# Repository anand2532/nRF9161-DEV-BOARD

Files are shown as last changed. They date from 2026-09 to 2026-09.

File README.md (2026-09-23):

# nRF9161-DEV-BOARD

Development board for **Nordic Semiconductor nRF9161-LACA-R7** (LTE-M, NB-IoT, DECT NR+, GNSS).

Electrical source of truth is official Nordic documentation only:

- nRF9161 Product Specification v1.0 (pinout Table 55, mechanics Table 56, reference circuitry)
- nRF91 Hardware Design Guidelines (nWP-037 family / Table 2) — nRF9161 uses the nRF9160 SiP power/RF pinout with DK extra **FB3 on VDD2**
- nRF91 Series Antenna and RF Interface Guidelines (nWP033)
- nRF9161 DK PCA10153 1.0.0 (FB3, GNSS U.FL + COEX0, TPD3F303, SWF MM8130)
- PCN134: DEC0 = **4.7 µF** (not the older 47 µF)

Do not treat this README as a substitute for those documents when certifying a product.

Project files keep the existing names `nRF9161-DEV-BOARD.kicad_*` (not `nRF9161_Board.*`).

## Board purpose

A 120 mm × 80 mm, 4-layer breakout so firmware and RF bring-up can use every nRF9161 interface: LTE/NR+ and GNSS antenna ports, nano-SIM, SWD, all 32 GPIOs, and labelled UART/SPI/I2C/I2S/PDM/ADC headers.

## nRF9161 capabilities on this board

| Function | Implementation |
| --- | --- |
| LTE-M / NB-IoT / DECT NR+ | ANT pin 61, reserved π-match (0 Ω series, DNP shunts), U.FL J2, SWF J3 |
| AUX | AUX pin 64, reserved π-match, TP1 |
| GNSS | GPS pin 67, nWP033 active-antenna bias-T, U.FL J5, SWF J6 |
| UICC/SIM | SIM_RST/CLK/IO/1V8 via TPD3F303 + JAE SF72S006 nano-SIM. SIM_DET pin 45 **floats** |
| 32 GPIOs | J12 (P0.00–P0.15) and J13 (P0.16–P0.31) |
| SWD | 10-pin Cortex-M J8 |
| MAGPIO / MIPI RFFE | J14 |
| COEX | J15 (COEX0 also enables GNSS bias through R4) |
| ENABLE / nRESET | R1 10 kΩ + C14; SW1 DISABLE; R5 1 kΩ + SW2 RESET |

Onboard GNSS ceramic antenna + BGM1212N7 LNA from the nRF9161 DK is **not fitted**. GNSS is U.FL-only for an external **active** antenna.

## Power requirements

VIN **3.0–5.5 V** on J1 (nRF9161 VDD range).

```
VIN (J1)
  D1 PMEG4030ER reverse Schottky → D2 SMAJ5.0A → F1 2 A → FB4 → C1/C2
  R2 50 mΩ (JP1 bypass) → VDD_nRF
       FB1 → VDD1 (pin 102) + C3 47 µF / C4 4.7 µF / C5 100 nF / C6 15 pF
       FB2 + FB3 → VDD2 (pin 22) + C7–C10 (FB3 per nRF9161 DK)
  R1 10 kΩ → ENABLE (pin 101) + C14 100 nF; SW1 to GND = disable
  TLV73333 3.3 V (EN=ENABLE) → VDD_GPIO (pin 12) + C11/C12
  DEC0 (pin 13) → C13 4.7 µF
```

Peak LTE TX on VDD2 is on the order of **500 mA**. Do not power the board from a weak USB 5 V dongle without checking cable and supply headroom. Use a current-limited bench supply for first power-up (1 A limit is a reasonable start; 2 A fuse is the hard limit).

Open JP1 and measure across R2 / TP19–TP20 for current. Close JP1 for normal operation.

Power LED D3 is on VIN, not a GPIO.

Test points: TP_VIN (TP15), TP_VDD_nRF (TP14), TP_VDD1 (TP11), TP_VDD2 (TP12), TP_VDD_GPIO (TP10/TP13), TP_GND (TP16), TP_ENABLE (TP17).

## RF architecture

Nordic evaluates ANT/AUX/GPS as **50 Ω single-ended**. Matching values are antenna- and PCB-specific (nWP033). This board does **not** invent tuned L/C values:

- LTE/NR+: series L1 is a 0 Ω / LQW15AN placeholder; C21/C22 DNP high-Q 0402 (HDG: Murata LQW15AN + GJM1555C1).
- AUX: same reserved π (L2, C23, C24).
- GNSS: nWP033 active-antenna bias-T — C27 100 pF DC block, L4 100 nH choke, C28–C30 + FB5 on ~3.3 V bias from VDD_GPIO via U3 TPS22919DCKR (ON=COEX0) → FB5; R4/TP2 are COEX0 sense only. Shunts C31/C32 DNP.

Tune L1/C21/C22 (and GNSS shunts) on the finished mechanics with a VNA.

LTE and GNSS matching sit immediately west of the SiP (U1 rotation 180°, RF edge west). Do not place digital traces under the matching networks.

## Antenna requirements

| Connector | Net | Use |
| --- | --- | --- |
| J2 U.FL | ANT_FIT | External LTE / DECT NR+ antenna |
| J3 SWF MM8130 | ANT_FIT | Conducted LTE RF test |
| J5 U.FL | GNSS_ANT | External **active** GNSS antenna (DC on center) |
| J6 SWF MM8130 | GNSS_ANT | Conducted GNSS RF test |
| TP1 | AUX_FIT | AUX test |

Disable GNSS LNA bias (`%XCOEX0`) if using a passive GNSS antenna.

## SIM requirements

- nRF9161 SIM_RST / SIM_CLK / SIM_IO / SIM_1V8 → TPD3F303DPV → JAE SF72S006 **nano-SIM (4FF)**
- SIM_DET (pin 45) **must float** (PS). Mechanical card-detect is `SIM_CD` on J7 CSW-DSW / TP6 — **not** pin 45
- Close JP2 to feed SIM_1V8 to the card
- SIM VPP (C6) NC

## GPIO map (authoritative)

All 32 GPIOs are on J12/J13. Protocol headers J9–J11 and J16–J18 are the **same nets** (intentional probe multiplexing). Onboard LEDs/USER share P0.00–P0.02 and P0.08 — drive those pins as GPIO or leave the LED/button unused in firmware.

| Pin | GPIO | Default header | Onboard | Alternate |
| --- | --- | --- | --- | --- |
| 95 | P0.00 | J12.1 | STATUS LED D4 | — |
| 96 | P0.01 | J12.2 | LTE LED D5 | — |
| 97 | P0.02 | J12.3 | GNSS LED D6 | — |
| 99 | P0.03 | J12.4 | SPARE LED D7 (optional) | — |
| 100 | P0.04 | J12.5 / UART CTS J9 | — | — |
| 2 | P0.05 | J12.6 / UART RTS J9 | — | — |
| 3 | P0.06 | J12.7 / UART TX J9 | — | — |
| 4 | P0.07 | J12.8 / UART RX J9 | — | — |
| 15 | P0.08 | J12.9 | USER SW3, R14 10 kΩ to VDD_GPIO | — |
| 16 | P0.09 | J12.10 / I2S SDIN J16 | — | — |
| 18 | P0.10 | J12.11 / I2S SCK J16 | — | — |
| 19 | P0.11 | J12.12 / I2S LRCK J16 | — | — |
| 20 | P0.12 | J12.13 / I2S SDOUT J16 | — | — |
| 23 | P0.13 | J12.14 / AIN0 J18 | — | AIN0 |
| 24 | P0.14 | J12.15 / AIN1 J18 | — | AIN1 |
| 25 | P0.15 | J12.16 / AIN2 J18 | — | AIN2 |
| 26 | P0.16 | J13.1 / AIN3 J18 | — | AIN3 |
| 28 | P0.17 | J13.2 / AIN4 J18 / PDM CLK J17 | — | AIN4 |
| 29 | P0.18 | J13.3 / AIN5 J18 / PDM DIN J17 | — | AIN5 |
| 30 | P0.19 | J13.4 / AIN6 J18 | — | AIN6 |
| 35 | P0.20 | J13.5 / AIN7 J18 | — | AIN7 |
| 37 | P0.21 | J13.6 / SPI SCK J10 | — | TRACECLK |
| 38 | P0.22 | J13.7 / SPI MOSI J10 / J8.6 SWO | — | TRACEDATA0 |
| 39 | P0.23 | J13.8 / SPI MISO J10 | — | TRACEDATA1 |
| 40 | P0.24 | J13.9 / SPI CS J10 | — | TRACEDATA2 |
| 42 | P0.25 | J13.10 | — | TRACEDATA3 |
| 83 | P0.26 | J13.11 | — | — |
| 84 | P0.27 | J13.12 | — | — |
| 86 | P0.28 | J13.13 | — | — |
| 87 | P0.29 | J13.14 | — | — |
| 88 | P0.30 | J13.15 / I2C SDA J11 | — | — |
| 89 | P0.31 | J13.16 / I2C SCL J11 | — | — |

J12/J13 pins 17–18 = VDD_GPIO (3.3 V), 19–20 = GND.

Full 127-pin audit: `reports/PIN_AUDIT.csv`.

## Peripheral map

| Header | Signals |
| --- | --- |
| J9 UART | TX P0.06, RX P0.07, RTS P0.05, CTS P0.04, 3V3, GND |
| J10 SPI | SCK P0.21, MOSI P0.22, MISO P0.23, CS P0.24, 3V3, GND |
| J11 I2C | SDA P0.30, SCL P0.31, 3V3, GND |
| J16 I2S | SCK P0.10, LRCK P0.11, SDIN P0.09, SDOUT P0.12, 3V3, GND |
| J17 PDM | CLK P0.17, DATA P0.18, 3V3, GND |
| J18 ADC | AIN0–AIN7 (P0.13–P0.20), GND |
| J8 SWD | 10-pin 1.27 mm ARM Cortex (J-Link) |

PWM can be assigned to any GPIO in software; there is no dedicated PWM header.

## SWD / programming

J8 (Samtec FTSH-105 style 1.27 mm 2×5):

| Pin | Signal |
| --- | --- |
| 1 | VDD_GPIO (VTREF) |
| 2 | SWDIO (pin 34) + TP7 |
| 3 | GND |
| 4 | SWCLK (pin 33) + TP8 |
| 5 | GND |
| 6 | P0.22 SWO (optional) |
| 7 | NC |
| 8 | nRESET via R5 1 kΩ + TP9 |
| 9 | NC |
| 10 | GND |

Use nRF Command Line Tools / J-Link. SWD is referenced to the SiP debug domain; VDD_GPIO on pin 1 is target-voltage sense at 3.3 V.

```
nrfjprog -f NRF91 --program firmware.hex --chiperase --verify --reset
```

## PCB stackup

Assumed **4-layer, 1.6 mm**, JLCPCB-like 7628 / JLC04161H-7628 (confirm with the fabricator impedance coupon):

| Layer | Name | Copper | Use |
| --- | --- | --- | --- |
| L1 | F.Cu | 1 oz | Components, RF microstrip, short digital |
| prepreg | ~0.12 mm, εr ≈ 4.2 | | |
| L2 | In1.Cu | 1 oz | **Solid GND** |
| core | ~1.2 mm | | |
| L3 | In2.Cu | 1 oz | VDD_nRF pour + remaining signals |
| prepreg | ~0.12 mm | | |
| L4 | B.Cu | 1 oz | GND pour + digital |

Outline 120 mm × 80 mm, R2 mm corners.

## Impedance assumptions

50 Ω microstrip on L1 over L2 GND:

- H ≈ 0.12 mm, εr ≈ 4.2, 1 oz copper
- Trace width **0.20 mm** (net class `RF_50OHM`)
- Confirm with the fabricator’s 4-layer impedance coupon before tape-out (typical 0.16–0.22 mm)

RF keepout: no digital components or buses in the west matching/U.FL region. L2 under the 50 Ω line is solid GND (required for microstrip). Do not split L2 under ANT/GPS.

## Assembly notes

1. LGA 16.0×10.5 mm, 0.30 mm round-rect pads from PS Table 56 (b=0.30). Nordic also documents oblong b×b1 0.30×0.80 for perimeter fanout; this revision uses 0.30 mm pads. Verify against the DK PcbDoc before SMT.
2. Stencil: follow Nordic DK practice; typical 0.10–0.12 mm stainless with reduction on LGA pads. Characterise with the EMS.
3. Populate DNP match parts only after VNA tune.
4. Close JP1 and JP2 for bring-up unless measuring current / isolating SIM VCC.
5. Ferrites: BOM uses BLM18KG221SN1 on VDD1/VDD2 (HDG Table 2 family). Some later DK notes prefer BLM18PG121SN1D (DCR < 0.1 Ω) — either is a Nordic-documented option; do not substitute arbitrary beads.

## First power-up procedure

1. Visual inspect solder, LGA, RF matching, SIM cage, polarity of D1/D2/LEDs.
2. With power off, measure resistance VIN–GND and VDD_nRF–GND. Expect high kΩ after capacitors charge; a dead short is a stop.
3. Leave J2/J5 antennas disconnected until DC rails are good.
4. Apply **current-limited** 3.3–5.0 V at J1 (start ~200 mA limit, raise to 1 A).
5. Check TP15 VIN, TP14 VDD_nRF, TP11 VDD1, TP12 VDD2, TP10 VDD_GPIO (~3.3 V), TP17 ENABLE high, TP16 GND.
6. Confirm SW1 not held (DISABLE). nRESET should sit high (internal pull-up).
7. Connect J-Link to J8. `nrfjprog -f NRF91 --ids` must see the SiP.
8. Program a blink/UART sample.
9. Toggle P0.00–P0.02 and watch STATUS/LTE/GNSS LEDs; press USER (P0.08).
10. Insert nano-SIM, close JP2, check SIM_1V8, CLK, RST, IO with a scope (keep probes short).
11. Fit LTE antenna on J2, run `%COPS` / Nordic asset_tracker LTE attach.
12. Fit **active** GNSS antenna on J5, enable COEX0 / LNA bias, check `$GNGGA` or `%XMONITOR`.
13. DECT NR+ only with matching firmware and a suitable 1.9 GHz antenna on J2.

## Hardware validation

Follow Nordic nRF9161 Hardware Verification Guidelines: current vs TX, VDD2 droop during LTE pulses, conducted RF via J3/J6 SWF, UICC ISO-7816, SWD, GPIO loopback on J12/J13.

## Known limitations — not production-ready until these are closed

kicad-cli DRC (`--severity-error`): **0 shorts, 0 clearance, 0 hole_clearance**. ERC: **0 errors**. The board is **not fab-ready** because **116 pads are still unconnected**.

1. **Routing is incomplete.** Outer LGA pads are Nordic oblong 0.30×0.80 mm; 27 U1 nets have courtyard vias; J3 SWF tap is on F.Cu. Remaining unconnected copper is mainly VDD1/VDD2/VDD_GPIO, SIM (RST/CLK/IO/1V8), ENABLE/nRESET, MAGPIO/MIPI/COEX, and several GPIOs plus their protocol-header duplicates (J9/J10/J16/J18). Finish those in Pcbnew.
2. GNSS_VBIAS still needs C30 and L4 joined around the GNSS_ANT spine without crossing the 50 Ω line.
3. 0.50 mm-pitch LGA escape cannot run traces *along* pad rows; remaining U1 pads that failed fanout must leave along the oblong long axis into the north/south/east via rings (west MAGPIO/MIPI should jog to the north ring).
4. In2.Cu is the VDD_nRF plane — do not pour GPIO on it. Long GPIO remainder belongs on B.Cu with unique channels south of J18 (y≈46–55) and west wrap x≈25–33 for J12 pins in the RF x-range.
5. Silkscreen is dense on 0402 clusters. Connector names and pin-1 markers are present.
6. No onboard GNSS LNA/patch. Active antenna required.
7. Input TVS is 5.0 V; continuous VIN must stay within 3.0–5.5 V.
8. `schematics/` (plural) is leftover unused hierarchy; the live design is `schematic/` (singular).

**Do not send this PCB to a fab until unconnected nets are routed and DRC unconnected_items is zero.**

## Reports and manufacturing

- BOM: `BOM.csv`
- ERC: `reports/ERC.txt`, `reports/ERC_kicad-cli.rpt`
- DRC: `reports/DRC_kicad-cli.rpt`, `reports/DRC_SUMMARY.txt`
- Pin audit: `reports/PIN_AUDIT.csv`
- Gerbers/drill/pos: `fab/` (generated from the last saved PCB; reflects the routing state above)

## Project files

- `nRF9161-DEV-BOARD.kicad_pro`
- `nRF9161-DEV-BOARD.kicad_sch` — sheets A–L
- `schematic/01_nRF9161.kicad_sch` … `12_TESTPOINTS.kicad_sch`
- `nRF9161-DEV-BOARD.kicad_pcb`
- `libraries/Nordic_nRF9161.kicad_sym`
- `libraries/Board.pretty` — LGA, SWF, TPD3F303 USON

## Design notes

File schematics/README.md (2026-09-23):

DO NOT EDIT — live hierarchical tree is schematic/ (singular). This folder is leftover unused.

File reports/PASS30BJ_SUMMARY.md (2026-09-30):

# PASS30BJ_SUMMARY — P0.05 leftover

**Timestamp:** 2026-09-30 18:05 IST
**KiCad:** 9.0.2
**Decision:** **NO-ROUTE**
**Net:** P0.05
**Git HEAD:** `d9a24687f90a94df2bd3796832823588efd1e078`
**PCB blob at start:** `7bcfe5791b156e426a2a0affefe938be4d39f8e6`
**PCB blob at end:** `7bcfe5791b156e426a2a0affefe938be4d39f8e6`
**sha1sum at start:** `c6dc3ba60aa52dbe533823c2a6a2af7aa5fb0e40`
**sha1sum at end:** `c6dc3ba60aa52dbe533823c2a6a2af7aa5fb0e40`
**Routed:** no
**Copper changed:** no
**New via:** no
**New segments:** 0
**Stopping rule:** length (pad-edge 63.217656 mm > 36 mm).

## Preconditions

Live `kicad-cli` DRC (`run_drc`, same gate as pass30bh / pass30bi): unconnected **51** (required 51), P0.05 opens **1** (required 1). short/clearance/crossing/hole 0/0/0/0. hole_to_hole 1. GND islands 12. Counts matched, so the gap was measured. No copper was added. No backup (no edit).

## Leftover pad

**J9.3** center (116.000, 13.080), circle PTH 1.700 x 1.700 mm, drill 1.000 mm. Copper on F.Cu, In1.Cu, In2.Cu, B.Cu. This pad is its own island. U1.2 and J12.6 are already one island and were not ripped. Prior report named J9.3 at (116.00, 13.08): **True**.

## Pad-edge

Pad-edge to the nearest copper on the closed U1.2/J12.6 island: **63.217656 mm** on In1.Cu. `GetClearance` from J9.3 to the locked In1 run. The minimum is shared by In1.Cu (47.400,38.400)-(57.050,38.400), In1.Cu (57.050,38.400)-(57.050,74.700) because both end on the round cap at (57.05, 38.40). Track-edge point (57.132695, 38.364481), pad-edge point (115.218994, 13.415455). Center distance to that corner 64.157657 mm. **Over the 36 mm cap.** Same length rule as pass30bh (J9.2 was 58.617 mm and was not routed). No route attempted.

## Why no route

Rule that stopped the pass: **length**. Pad-edge 63.217656 mm is over 36 mm. No segments were laid, so there is no foreign clearance, no POWER clearance, and no new via. Whole-segment crossing count: 0 (no segments). The locked P0.05 In1 run was not ripped and nothing was stacked on its centerline. P0.07, P0.00, SIM_RST, SIM_CLK, and the four skirts were not ripped or stacked. J9.2 (P0.07) was not touched and stays open. Skirt slot, sealed pocket, and RF keepout were not entered. No second path. No other net. No Gerbers. No git commit.

## Locked copper check (read only)

```
{
  "p016": true,
  "p017": true,
  "p019": true,
  "p020": true,
  "sim_clk": true,
  "sim_rst_in1": true,
  "sim_rst_neck": true,
  "sim_rst_via": true,
  "p000": true,
  "p007": true,
  "p007_via": true,
  "p005": true,
  "p005_via": true,
  "j9_2": true
}
```

J9.2: `{"xy": [116.0, 10.54], "net": "P0.07", "fp_xy": [116.0, 8.0]}`.

All locked checks true: **True**.

## DRC (unchanged board)

| | unconnected | P0.05 | short | clearance | crossing | hole | hole_to_hole | GND islands |
| --- | --- | --- | --- | --- | --- | --- | --- | --- |
| before | 51 | 1 | 0 | 0 | 0 | 0 | 1 | 12 |
| after | 51 | 1 | 0 | 0 | 0 | 0 | 1 | 12 |

No mid DRC: copper was not edited. AFTER is a copy of BEFORE. End blob matches start blob: **True**.

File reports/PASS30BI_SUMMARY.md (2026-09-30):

# PASS30BI_SUMMARY — P0.05 U1.2 to J12.6

**Timestamp:** 2026-09-30 18:00 IST
**KiCad:** 9.0.2
**Decision:** **KEEP**
**Net:** P0.05
**Pair:** U1.2 ↔ J12.6 only
**Git HEAD:** `99ff66c8a933ebb01cc397bcf392732c55d9c9c6`
**PCB blob at start:** `953e98bc52f2b39ffec50928389f4492eff69ce7`
**PCB blob at end:** `7bcfe5791b156e426a2a0affefe938be4d39f8e6`
**sha1sum at start:** `828df5c6726a56fb12bc18312f258fc973d582d6`
**sha1sum at end:** `c6dc3ba60aa52dbe533823c2a6a2af7aa5fb0e40`
**Expected tip/blob matched:** True / True
**End blob matches start:** False
**Ends already one island:** False
**Via (47.40, 36.50) on U1.2 island:** True
**Start via:** {'xy': [47.4, 36.5], 'width_mm': 0.6, 'radius_mm': 0.3, 'drill_mm': 0.3, 'through': True, 'nm': [47400000, 36500000], 'net': 'P0.05'}
**J12.6 center:** [18.7, 76.0]
**J12.6 size mm:** [1.7, 1.7]
**J12.6 drill mm:** 1.0
**J12.6 layers:** ['F.Cu', 'In1.Cu', 'In2.Cu', 'B.Cu']
**Far island F.Cu-only:** False
**U1 island layers:** ['F.Cu', 'In1.Cu', 'In2.Cu', 'B.Cu']
**Pad-edge (U1.2 copper to J12.6 copper):** 45.730103 mm (census 45.733)
**New via:** no
**Joined:** J12.6 pad center on In1.Cu (PTH copper already on In1)
**New segments:** 7 (limit 10)
**Crossing test failed:** False
**Whole-segment crossing count:** 0
**Min foreign clearance:** 0.33 mm vs {'net': 'P0.20', 'item': 'pad J18.8'}
**Min POWER/VIN clearance:** 0.33 mm vs {'net': 'VDD_GPIO', 'item': 'pad J18.9'}
**Min hole clearance:** 0.68 mm vs hole J18.8 [P0.20]
**Other P0.05 opens left untouched:** [{'name': 'J9.3', 'xy': [116.0, 13.08], 'island': ['J9.3'], 'same_as_u1': False, 'same_as_j12': False}]
**P0.05 opens:** 2 → 1
**U1.2↔J12.6 open:** True → False
**Unconnected:** 52 → 51
**GND islands:** 12 → 12 (waived)
**J9.2 before/after:** {'xy': [116.0, 10.54], 'net': 'P0.07', 'fp_xy': [116.0, 8.0]} / {'xy': [116.0, 10.54], 'net': 'P0.07', 'fp_xy': [116.0, 8.0]}

## Islands

U1 island: ['U1.2', 'F.Cu (44.000,36.500)-(47.400,36.500)', 'via@47.400,36.500']
Far island: ['J12.6']

## Straight chord

F.Cu 0.18 mm [43.622, 36.647] → [19.101, 75.25], length 45.732604 mm. Crosses SiP body: True. P0.02 {'xy': [40.75, 41.1], 'width_mm': 0.6, 'center_distance_mm': 0.03664350727677847, 'edge_clearance_mm': -0.35335649272322156}. Not used.

## Whole-segment crossing test

segment-vs-segment interior intersection plus 0.05 mm samples, against P0.16, P0.17, P0.19, P0.20, the SIM_CLK In1 run, the SIM_RST run (F.Cu neck plus In1), the P0.00 In1 run, and the P0.07 In2 run. Layers are not exempt. A same-centerline stack on x=44.25, x=44.60, the y=63.20 eastbounds, or any locked P0.07 centerline is a fail. Endpoint-only touches are not crossings.
Crossings: **0**. Min centerline to a locked run: **0.5 mm** vs {'net': 'P0.07', 'segment': [[48.05, 35.5], [48.05, 37.9]]}.

- (47.4, 36.5) → (47.4, 38.4) crossed=False nearest P0.07 [[48.05, 35.5], [48.05, 37.9]] center 0.65 mm (edge 0.47 mm), 38 samples
- (47.4, 38.4) → (57.05, 38.4) crossed=False nearest P0.07 [[48.05, 35.5], [48.05, 37.9]] center 0.5 mm (edge 0.32 mm), 193 samples
- (57.05, 38.4) → (57.05, 74.7) crossed=False nearest P0.07 [[48.05, 37.9], [63.1, 37.9]] center 0.5 mm (edge 0.32 mm), 727 samples
- (57.05, 74.7) → (22.51, 74.7) crossed=False nearest P0.07 [[25.2, 79.2], [25.2, 76.0]] center 1.3 mm (edge 1.12 mm), 691 samples
- (22.51, 74.7) → (22.51, 79.4) crossed=False nearest P0.07 [[25.2, 76.0], [23.78, 76.0]] center 1.27 mm (edge 1.09 mm), 95 samples
- (22.51, 79.4) → (18.7, 79.4) crossed=False nearest P0.07 [[62.7, 79.2], [25.2, 79.2]] center 2.6974 mm (edge 2.5174 mm), 77 samples
- (18.7, 79.4) → (18.7, 76.0) crossed=False nearest P0.07 [[25.2, 76.0], [23.78, 76.0]] center 5.08 mm (edge 4.9 mm), 69 samples

## Attempt

In1.Cu only, 7 segments, no new via. Via (47.40, 36.50) is P0.05 and is on the U1.2 island. Starts there and lands on J12.6 (PTH, In1 copper) from the south. Kept.

- (47.4, 36.5) → (47.4, 38.4) In1.Cu 0.18 mm
- (47.4, 38.4) → (57.05, 38.4) In1.Cu 0.18 mm
- (57.05, 38.4) → (57.05, 74.7) In1.Cu 0.18 mm
- (57.05, 74.7) → (22.51, 74.7) In1.Cu 0.18 mm
- (22.51, 74.7) → (22.51, 79.4) In1.Cu 0.18 mm
- (22.51, 79.4) → (18.7, 79.4) In1.Cu 0.18 mm
- (18.7, 79.4) → (18.7, 76.0) In1.Cu 0.18 mm

South of the P0.07 y=37.90 run at y=38.40 (0.50 mm off that centerline), east to x=57.05 (the J18.8/J18.9 gap, east of the P0.20 y=63.20 end at x=55.78), south to y=74.70 (north of the J12 row and of the P0.07 x=25.20 wall), west to x=22.51 (the J12.7/J12.8 gap), south to y=79.40 (south of the P0.07 y=79.20 run and of the header, west of x=25.20 so the locked horizontal is not crossed), west to x=18.70, then north onto the J12.6 pad center. x=44.25 and x=44.60 not used. P0.07 centerline not used. Sealed y=44.60 pocket not entered. RF keepout box x<=24.2 and y in [20, 64] not entered. P0.00, SIM_RST, SIM_CLK, and P0.07 centerlines not stacked. J9.2 not touched. No header or U1 move. No other net. J9.3 left open.

## Clearance by segment

- In1.Cu (47.4, 36.5)–(47.4, 38.4) ok=True foreign=0.61 vs {'net': 'P0.07', 'item': 'via@47.400,35.500'} power=None vs None hole=0.76 vs via P0.07 @47.400,35.500 why=None
- In1.Cu (47.4, 38.4)–(57.05, 38.4) ok=True foreign=2.01 vs {'net': 'P0.06', 'item': 'via@48.620,36.000'} power=2.4504 vs {'net': 'VDD2', 'item': 'via@59.700,37.126'} hole=2.16 vs via P0.06 @48.620,36.000 why=None
- In1.Cu (57.05, 38.4)–(57.05, 74.7) ok=True foreign=0.33 vs {'net': 'P0.20', 'item': 'pad J18.8'} power=0.33 vs {'net': 'VDD_GPIO', 'item': 'pad J18.9'} hole=0.68 vs hole J18.8 [P0.20] why=None
- In1.Cu (57.05, 74.7)–(22.51, 74.7) ok=True foreign=0.36 vs {'net': 'P0.07', 'item': 'pad J12.8'} power=0.36 vs {'net': 'VDD_GPIO', 'item': 'pad J12.17'} hole=0.71 vs hole J12.8 [P0.07] why=None
- In1.Cu (22.51, 74.7)–(22.51, 79.4) ok=True foreign=0.33 vs {'net': 'P0.06', 'item': 'pad J12.7'} power=None vs None hole=0.68 vs hole J12.8 [P0.07] why=None
- In1.Cu (22.51, 79.4)–(18.7, 79.4) ok=True foreign=1.7941 vs {'net': 'P0.01', 'item': 'via@24.500,78.500'} power=None vs None hole=1.9441 vs via P0.01 @24.500,78.500 why=None
- In1.Cu (18.7, 79.4)–(18.7, 76.0) ok=True foreign=1.6 vs {'net': 'P0.04', 'item': 'pad J12.5'} power=None vs None hole=1.95 vs hole J12.5 [P0.04] why=None

## Gate

KEEP. In1 south approach, 7 new segments, no new via, from existing P0.05 through-via (47.40, 36.50) onto J12.6. Via is on the U1.2 island. Straight F.Cu chord not used (P0.02). P0.07 centerline not used. Skirt slot, sealed pocket, and RF keepout not used. Whole-segment crossings: 0. P0.05 opens 2→1. U1.2↔J12.6 open closed. Unconnected 52→51. Foreign 0.33 mm vs {'net': 'P0.20', 'item': 'pad J18.8'}. POWER 0.33 mm vs {'net': 'VDD_GPIO', 'item': 'pad J18.9'}. short/clearance/crossing/hole 0/0/0/0. hole_to_hole 1. GND islands 12→12 (waived). Other non-GND gained: none. J9.3 left open. J9.2 not touched. Four skirts, SIM_CLK, SIM_RST, P0.00, and P0.07 not ripped or stacked. No other net.

## DRC

| | unconnected | P0.05 | short | clearance | crossing | hole | hole_to_hole | GND islands |
| --- | --- | --- | --- | --- | --- | --- | --- | --- |
| before | 52 | 2 | 0 | 0 | 0 | 0 | 1 | 12 |
| after | 51 | 1 | 0 | 0 | 0 | 0 | 1 | 12 |

No other non-GND net gained an open.
P0.16 / P0.17 / P0.19 / P0.20 skirts not ripped and not stacked. SIM_CLK, SIM_RST, P0.00, and the P0.07 In2 run not ripped and not stacked. J9.2 not touched. Skirt slot, sealed pocket, and RF keepout not used. No other net. No Gerbers. No git commit.

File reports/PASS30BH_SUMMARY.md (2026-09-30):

# PASS30BH_SUMMARY — P0.07 leftover

**Timestamp:** 2026-09-30 17:47 IST
**KiCad:** 9.0.2
**Decision:** **NO-ROUTE**
**Net:** P0.07
**Git HEAD:** `bed9dc7e7d4542c71796af436ae8c8e2b224188d`
**PCB blob at start:** `953e98bc52f2b39ffec50928389f4492eff69ce7`
**PCB blob at end:** `953e98bc52f2b39ffec50928389f4492eff69ce7`
**sha1sum at start:** `828df5c6726a56fb12bc18312f258fc973d582d6`
**sha1sum at end:** `828df5c6726a56fb12bc18312f258fc973d582d6`
**Routed:** no
**Copper changed:** no
**New via:** no
**New segments:** 0
**Stopping rule:** length (pad-edge 58.616524 mm > 36 mm).

## Preconditions

Live `kicad-cli` DRC (`run_drc`, same gate as pass30bg): unconnected **52** (required 52), P0.07 opens **1** (required 1). short/clearance/crossing/hole 0/0/0/0. hole_to_hole 1. GND islands 12. Counts matched, so the gap was measured. No copper was added. No backup (no edit).

## Leftover pad

**J9.2** center (116.000, 10.540), circular PTH 1.700 mm, drill 1.000 mm. Copper on F.Cu, In1.Cu, In2.Cu, B.Cu. This pad is its own island. U1.4 and J12.8 are already one island and were not ripped.

## Pad-edge

Pad-edge to the nearest copper on the closed U1.4/J12.8 island: **58.616524 mm** on In2.Cu. `GetClearance` from J9.2 to the locked In2 run. The minimum is shared by In2.Cu (48.050,37.900)-(63.100,37.900), In2.Cu (63.100,37.900)-(63.100,70.000) because both end on the round cap at (63.10, 37.90). Track-edge point (63.179941, 37.858654), pad-edge point (115.245003, 10.930486). Center distance to that corner 59.556524 mm. **Over the 36 mm cap.** Same length rule as the P0.17 leftover. No route attempted.

## Why no route

Rule that stopped the pass: **length**. Pad-edge 58.616524 mm is over 36 mm. No segments were laid, so there is no foreign clearance, no POWER clearance, and no new via. Whole-segment crossing count: 0 (no segments). The locked P0.07 In2 run was not ripped and nothing was stacked on its centerline. P0.00, SIM_RST, SIM_CLK, and the four skirts were not ripped or stacked. P0.05 via at (47.40, 36.50) is still net P0.05 and was not routed. Skirt slot, sealed pocket, and RF keepout were not entered. No second path. No other net. No Gerbers. No git commit.

## Locked copper check (read only)

```
{
  "p016": true,
  "p017": true,
  "p019": true,
  "p020": true,
  "sim_clk": true,
  "sim_rst_in1": true,
  "sim_rst_neck": true,
  "sim_rst_via": true,
  "p000": true
}
```

All locked checks true: **True**.

## DRC (unchanged board)

| | unconnected | P0.07 | short | clearance | crossing | hole | hole_to_hole | GND islands |
| --- | --- | --- | --- | --- | --- | --- | --- | --- |
| before | 52 | 1 | 0 | 0 | 0 | 0 | 1 | 12 |
| after | 52 | 1 | 0 | 0 | 0 | 0 | 1 | 12 |

No mid DRC: copper was not edited. AFTER is a copy of BEFORE. End blob matches start blob: **True**.

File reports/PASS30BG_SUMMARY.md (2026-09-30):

# PASS30BG_SUMMARY — P0.07

**Timestamp:** 2026-09-30 17:41 IST
**KiCad:** 9.0.2
**Decision:** **KEEP**
**Net:** P0.07
**Git HEAD:** `e851c3b7098da41ad116489be01451cd2c113723`
**PCB blob at start:** `1689715203e755d4422b71fb29202c387b9c7889`
**PCB blob at end:** `953e98bc52f2b39ffec50928389f4492eff69ce7`
**Expected tip/blob matched:** True / True
**Ends already one island:** False
**Named via (47.40, 36.50) on U1.4 island:** False
**Named via:** {'net': 'P0.05', 'xy': [47.4, 36.5], 'width_mm': 0.6, 'radius_mm': 0.3, 'drill_mm': 0.3, 'through': True, 'nm': [47400000, 36500000], 'on_u1_island': False}
**Start via (47.40, 35.50) on U1.4 island:** True
**Start via:** {'xy': [47.4, 35.5], 'width_mm': 0.6, 'radius_mm': 0.3, 'drill_mm': 0.3, 'through': True, 'nm': [47400000, 35500000], 'net': 'P0.07'}
**J12.8 center:** [23.78, 76.0]
**J12.8 layers:** ['F.Cu', 'In1.Cu', 'In2.Cu', 'B.Cu']
**Far island F.Cu-only:** False
**U1 island layers:** ['F.Cu', 'In1.Cu', 'In2.Cu', 'B.Cu']
**Pad-edge (U1.4 to J12.8):** 44.117219 mm (census 44.118)
**New via:** no
**Joined:** J12.8 pad center on In2.Cu (PTH copper already on In2)
**New segments:** 9 (limit 10)
**Crossing test failed:** False
**Whole-segment crossing count:** 0
**Min foreign clearance:** 0.18 mm vs {'net': 'P0.08', 'item': 'pad J12.9'}
**Min POWER/VIN clearance:** 0.2842 mm vs {'net': 'VDD2', 'item': 'via@59.700,37.126'}
**Min hole clearance:** 0.33 mm vs via P0.06 @48.620,36.000
**P0.07 opens:** 2 → 1
**Unconnected:** 53 → 52
**GND islands:** 12 → 12 (waived)

## Islands

U1 island: ['U1.4', 'F.Cu (44.000,35.500)-(47.400,35.500)', 'via@47.400,35.500']
Far island: ['J12.8']

## Straight chord

F.Cu 0.18 mm [43.622, 35.647] → [24.181, 75.25], length 44.117458 mm. Crosses SiP body: True. P0.02 {'xy': [40.75, 41.1], 'width_mm': 0.6, 'center_distance_mm': 0.17516972579450418, 'edge_clearance_mm': -0.2148302742054958}. Not used.

## Whole-segment crossing test

segment-vs-segment interior intersection plus 0.05 mm samples, against P0.16, P0.17, P0.19, P0.20, the SIM_CLK In1 run, the SIM_RST run (F.Cu neck plus In1), and the P0.00 In1 run. Layers are not exempt. A same-centerline stack on x=44.25, x=44.60, or the y=63.20 eastbounds is a fail. Endpoint-only touches are not crossings.
Crossings: **0**. Min centerline to a locked run: **1.9 mm** vs {'net': 'SIM_CLK', 'segment': [[57.2, 19.55], [57.2, 36.0]]}.

- (47.4, 35.5) → (48.05, 35.5) crossed=False nearest P0.16 [[44.6, 27.4], [44.6, 60.4]] center 2.8 mm (edge 2.62 mm), 13 samples
- (48.05, 35.5) → (48.05, 37.9) crossed=False nearest P0.16 [[44.6, 27.4], [44.6, 60.4]] center 3.45 mm (edge 3.27 mm), 48 samples
- (48.05, 37.9) → (63.1, 37.9) crossed=False nearest SIM_CLK [[57.2, 19.55], [57.2, 36.0]] center 1.9 mm (edge 1.72 mm), 302 samples
- (63.1, 37.9) → (63.1, 70.0) crossed=False nearest SIM_CLK [[57.2, 36.0], [73.3, 36.0]] center 1.9 mm (edge 1.72 mm), 643 samples
- (63.1, 70.0) → (62.7, 70.0) crossed=False nearest P0.20 [[44.25, 63.2], [55.78, 63.2]] center 9.7019 mm (edge 9.5219 mm), 8 samples
- (62.7, 70.0) → (62.7, 79.2) crossed=False nearest P0.20 [[44.25, 63.2], [55.78, 63.2]] center 9.7019 mm (edge 9.5219 mm), 185 samples
- (62.7, 79.2) → (25.2, 79.2) crossed=False nearest P0.19 [[44.25, 40.7], [44.25, 63.2]] center 16.0 mm (edge 15.82 mm), 751 samples
- (25.2, 79.2) → (25.2, 76.0) crossed=False nearest P0.19 [[44.25, 40.7], [44.25, 63.2]] center 22.9509 mm (edge 22.7709 mm), 65 samples
- (25.2, 76.0) → (23.78, 76.0) crossed=False nearest P0.19 [[44.25, 40.7], [44.25, 63.2]] center 22.9509 mm (edge 22.7709 mm), 29 samples

## Attempt

In2.Cu only, 9 segments, no new via. Named via (47.40, 36.50) is P0.05 and was not used. Starts at existing P0.07 through-via (47.40, 35.50) and lands on J12.8 (PTH, In2 copper). Kept.

- (47.4, 35.5) → (48.05, 35.5) In2.Cu 0.18 mm
- (48.05, 35.5) → (48.05, 37.9) In2.Cu 0.18 mm
- (48.05, 37.9) → (63.1, 37.9) In2.Cu 0.18 mm
- (63.1, 37.9) → (63.1, 70.0) In2.Cu 0.18 mm
- (63.1, 70.0) → (62.7, 70.0) In2.Cu 0.18 mm
- (62.7, 70.0) → (62.7, 79.2) In2.Cu 0.18 mm
- (62.7, 79.2) → (25.2, 79.2) In2.Cu 0.18 mm
- (25.2, 79.2) → (25.2, 76.0) In2.Cu 0.18 mm
- (25.2, 76.0) → (23.78, 76.0) In2.Cu 0.18 mm

East of the SiP at x=48.05 (clear of the P0.06 via at 48.62, 36.00), east to x=63.10 (east of the P0.20 y=63.20 end at x=55.78 and of the skirt verticals), south to y=70, jog to x=62.70 to clear J13.1, south to y=79.20 (south of the header row and of the RF keepout), west to x=25.20, north into the gap east of J12.8, then west onto the pad center. x=44.25 and x=44.60 not used. Sealed y=44.60 pocket not entered. RF keepout box x<=24.2 and y in [20, 64] not entered. P0.00, SIM_RST, and SIM_CLK centerlines not stacked. No header or U1 move. No other net.

## Clearance by segment

- In2.Cu (47.4, 35.5)–(48.05, 35.5) ok=True foreign=0.3682 vs {'net': 'P0.06', 'item': 'via@48.620,36.000'} power=None vs None hole=0.5182 vs via P0.06 @48.620,36.000 why=None
- In2.Cu (48.05, 35.5)–(48.05, 37.9) ok=True foreign=0.18 vs {'net': 'P0.06', 'item': 'via@48.620,36.000'} power=None vs None hole=0.33 vs via P0.06 @48.620,36.000 why=None
- In2.Cu (48.05, 37.9)–(63.1, 37.9) ok=True foreign=0.2842 vs {'net': 'VDD2', 'item': 'via@59.700,37.126'} power=0.2842 vs {'net': 'VDD2', 'item': 'via@59.700,37.126'} hole=0.4842 vs via VDD2 @59.700,37.126 why=None
- In2.Cu (63.1, 37.9)–(63.1, 70.0) ok=True foreign=0.21 vs {'net': 'ENABLE', 'item': 'via@62.500,40.950'} power=0.81 vs {'net': 'VDD2', 'item': 'via@61.800,45.100'} hole=0.36 vs via ENABLE @62.500,40.950 why=None
- In2.Cu (63.1, 70.0)–(62.7, 70.0) ok=True foreign=2.6877 vs {'net': 'P0.08', 'item': 'via@65.200,72.250'} power=None vs None hole=2.8377 vs via P0.08 @65.200,72.250 why=None
- In2.Cu (62.7, 70.0)–(62.7, 79.2) ok=True foreign=0.31 vs {'net': 'P0.01', 'item': 'via@62.000,74.500'} power=None vs None hole=0.46 vs via P0.01 @62.000,74.500 why=None
- In2.Cu (62.7, 79.2)–(25.2, 79.2) ok=True foreign=0.31 vs {'net': 'P0.01', 'item': 'via@27.200,78.500'} power=2.26 vs {'net': 'VDD_GPIO', 'item': 'pad J12.17'} hole=0.46 vs via P0.01 @27.200,78.500 why=None
- In2.Cu (25.2, 79.2)–(25.2, 76.0) ok=True foreign=0.18 vs {'net': 'P0.08', 'item': 'pad J12.9'} power=None vs None hole=0.46 vs via P0.01 @24.500,78.500 why=None
- In2.Cu (25.2, 76.0)–(23.78, 76.0) ok=True foreign=0.18 vs {'net': 'P0.08', 'item': 'pad J12.9'} power=None vs None hole=0.53 vs hole J12.9 [P0.08] why=None

## Gate

KEEP. In2 south bypass, 9 new segments, no new via, from existing P0.07 through-via (47.40, 35.50) onto J12.8. Named via (47.40, 36.50) is P0.05 and was not used. Straight F.Cu chord not used (P0.02). Skirt slot, sealed pocket, and RF keepout not used. Whole-segment crossings: 0. P0.07 opens 2→1. Unconnected 53→52. Foreign 0.18 mm vs {'net': 'P0.08', 'item': 'pad J12.9'}. POWER 0.2842 mm vs {'net': 'VDD2', 'item': 'via@59.700,37.126'}. short/clearance/crossing/hole 0/0/0/0. hole_to_hole 1. GND islands 12→12 (waived). Other non-GND gained: none. Four skirts, SIM_CLK, SIM_RST, and P0.00 not ripped or stacked. No other net.

## DRC

| | unconnected | P0.07 | short | clearance | crossing | hole | hole_to_hole | GND islands |
| --- | --- | --- | --- | --- | --- | --- | --- | --- |
| before | 53 | 2 | 0 | 0 | 0 | 0 | 1 | 12 |
| after | 52 | 1 | 0 | 0 | 0 | 0 | 1 | 12 |

No other non-GND net gained an open.
P0.16 / P0.17 / P0.19 / P0.20 skirts not ripped and not stacked. SIM_CLK, SIM_RST, and P0.00 not ripped and not stacked. Skirt slot, sealed pocket, and RF keepout not used. No other net. No Gerbers. No git commit.

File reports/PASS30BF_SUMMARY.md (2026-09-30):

# PASS30BF_SUMMARY — P0.00

**Timestamp:** 2026-09-30 17:28 IST
**KiCad:** 9.0.2
**Decision:** **KEEP**
**Net:** P0.00
**Git HEAD:** `b60ffcb6ad9ac026ee3b82eadcfdd6fd9ef8adba`
**PCB blob at start:** `625ef9d7ba5150f27306905b448cc93eee4f59d9`
**PCB blob at end:** `1689715203e755d4422b71fb29202c387b9c7889`
**Expected tip/blob matched:** True / True
**Ends already one island:** False
**Start via (39.75, 41.10) on U1.95 island:** True
**Start via:** {'xy': [39.75, 41.1], 'width_mm': 0.6, 'radius_mm': 0.3, 'drill_mm': 0.3, 'through': True, 'nm': [39750000, 41100000]}
**Far island layers:** ['F.Cu', 'In1.Cu', 'In2.Cu', 'B.Cu']
**Far island F.Cu-only:** False
**Far through-vias:** [{'name': 'via@80.140,19.126', 'xy': [80.14, 19.125833], 'width_mm': 0.6, 'drill_mm': 0.3, 'nm': [80140000, 19125833]}]
**U1 island layers:** ['F.Cu', 'In1.Cu', 'In2.Cu', 'B.Cu']
**Pad-edge (U1.95 to F.Cu x=79.49 segment):** 43.297995 mm (census 43.298)
**New via:** no
**Joined:** existing through-via (80.14, 19.125833) on In1.Cu
**New segments:** 9 (limit 10)
**Crossing test failed:** False
**Whole-segment crossing count:** 0
**Min foreign clearance:** 0.16 mm vs {'net': 'MIPI_VIO', 'item': 'via@24.650,24.400'}
**Min POWER/VIN clearance:** 0.2457 mm vs {'net': 'VDD2', 'item': 'via@68.137,16.874'}
**Min hole clearance:** 0.31 mm vs via MIPI_VIO @24.650,24.400
**P0.00 opens:** 1 → 0
**Unconnected:** 54 → 53
**GND islands:** 12 → 12 (waived)

## Islands

U1 island: ['J12.1', 'U1.95', 'F.Cu (39.750,41.100)-(6.000,76.000)', 'F.Cu (39.750,37.250)-(39.750,41.100)', 'via@39.750,41.100']
Far island: ['R10.1', 'F.Cu (79.490,18.000)-(79.490,19.126)', 'F.Cu (79.490,19.126)-(80.140,19.126)', 'via@80.140,19.126']

## Straight chord

F.Cu 0.18 mm [39.897, 36.872] → [79.408, 19.163], length 43.298127 mm. Crosses SiP body: True. VDD1 {'track': [50.68, 35.0, 50.68, 31.0], 'width_mm': 0.4, 'proper_cross': True, 'edge_clearance_mm': -0.29000000000000004}. Not used.

## Whole-segment crossing test

segment-vs-segment interior intersection plus 0.05 mm samples, against P0.16, P0.17, P0.19, P0.20, the SIM_CLK In1 run, and the SIM_RST run (F.Cu neck plus In1). Layers are not exempt. A same-centerline stack on x=44.25, x=44.60, or the y=63.20 eastbounds is a fail. Endpoint-only touches are not crossings.
Crossings: **0**. Min centerline to a locked run: **1.0 mm** vs {'net': 'SIM_RST', 'segment': [[32.75, 25.5], [26.2, 25.5]]}.

- (39.75, 41.1) → (39.75, 37.4) crossed=False nearest P0.19 [[44.25, 39.1], [42.8, 39.9]] center 3.05 mm (edge 2.87 mm), 75 samples
- (39.75, 37.4) → (25.2, 37.4) crossed=False nearest P0.19 [[44.25, 39.1], [42.8, 39.9]] center 3.9437 mm (edge 3.7637 mm), 292 samples
- (25.2, 37.4) → (25.2, 23.5) crossed=False nearest SIM_RST [[32.75, 25.5], [26.2, 25.5]] center 1.0 mm (edge 0.82 mm), 278 samples
- (25.2, 23.5) → (25.0, 23.5) crossed=False nearest SIM_RST [[26.2, 25.5], [26.2, 17.6]] center 1.0 mm (edge 0.82 mm), 4 samples
- (25.0, 23.5) → (25.0, 15.2) crossed=False nearest SIM_RST [[26.2, 25.5], [26.2, 17.6]] center 1.2 mm (edge 1.02 mm), 167 samples
- (25.0, 15.2) → (68.7, 15.2) crossed=False nearest SIM_RST [[26.2, 25.5], [26.2, 17.6]] center 2.4 mm (edge 2.22 mm), 875 samples
- (68.7, 15.2) → (68.7, 16.4) crossed=False nearest SIM_RST [[55.3, 18.5], [68.0, 18.5]] center 2.2136 mm (edge 2.0336 mm), 24 samples
- (68.7, 16.4) → (80.14, 16.4) crossed=False nearest SIM_RST [[55.3, 18.5], [68.0, 18.5]] center 2.2136 mm (edge 2.0336 mm), 229 samples
- (80.14, 16.4) → (80.14, 19.125833) crossed=False nearest SIM_RST [[55.3, 18.5], [68.0, 18.5]] center 12.14 mm (edge 11.96 mm), 55 samples

## Attempt

In1.Cu only, 9 segments, no new via. Starts at existing through-via (39.75, 41.10) and lands on existing through-via (80.14, 19.125833). Kept.

- (39.75, 41.1) → (39.75, 37.4) In1.Cu 0.18 mm
- (39.75, 37.4) → (25.2, 37.4) In1.Cu 0.18 mm
- (25.2, 37.4) → (25.2, 23.5) In1.Cu 0.18 mm
- (25.2, 23.5) → (25.0, 23.5) In1.Cu 0.18 mm
- (25.0, 23.5) → (25.0, 15.2) In1.Cu 0.18 mm
- (25.0, 15.2) → (68.7, 15.2) In1.Cu 0.18 mm
- (68.7, 15.2) → (68.7, 16.4) In1.Cu 0.18 mm
- (68.7, 16.4) → (80.14, 16.4) In1.Cu 0.18 mm
- (80.14, 16.4) → (80.14, 19.125833) In1.Cu 0.18 mm

West of the SiP on In1 at x=25.20 then x=25.00 (east of the RF keepout x=24.2), north at y=15.20 (north of SIM_RST y=17.60 and of SIM_CLK), east to x=80.14, south onto the existing far through-via. x=44.25 and x=44.60 not used. Sealed y=44.60 pocket not entered. SIM_RST and SIM_CLK centerlines not stacked. No header or U1 move. No other net.

## Clearance by segment

- In1.Cu (39.75, 41.1)–(39.75, 37.4) ok=True foreign=0.61 vs {'net': 'COEX0', 'item': 'via@38.750,41.100'} power=None vs None hole=0.76 vs via COEX0 @38.750,41.100 why=None
- In1.Cu (39.75, 37.4)–(25.2, 37.4) ok=True foreign=2.01 vs {'net': 'GND', 'item': 'via@39.000,35.000'} power=2.11 vs {'net': 'VDD_GPIO', 'item': 'via@28.500,40.000'} hole=2.16 vs via GND @39.000,35.000 why=None
- In1.Cu (25.2, 37.4)–(25.2, 23.5) ok=True foreign=0.16 vs {'net': 'MIPI_VIO', 'item': 'via@24.650,24.400'} power=3.7112 vs {'net': 'VDD_GPIO', 'item': 'via@28.500,40.000'} hole=0.31 vs via MIPI_VIO @24.650,24.400 why=None
- In1.Cu (25.2, 23.5)–(25.0, 23.5) ok=True foreign=0.1757 vs {'net': 'MAGPIO1', 'item': 'via@25.600,23.100'} power=None vs None hole=0.3257 vs via MAGPIO1 @25.600,23.100 why=None
- In1.Cu (25.0, 23.5)–(25.0, 15.2) ok=True foreign=0.21 vs {'net': 'MAGPIO1', 'item': 'via@25.600,23.100'} power=None vs None hole=0.36 vs via MAGPIO1 @25.600,23.100 why=None
- In1.Cu (25.0, 15.2)–(68.7, 15.2) ok=True foreign=0.21 vs {'net': 'nRESET', 'item': 'via@45.680,15.800'} power=0.61 vs {'net': 'VDD2_MID', 'item': 'via@67.213,16.300'} hole=0.36 vs via nRESET @45.680,15.800 why=None
- In1.Cu (68.7, 15.2)–(68.7, 16.4) ok=True foreign=0.21 vs {'net': 'P0.15', 'item': 'via@69.300,15.350'} power=0.2457 vs {'net': 'VDD2', 'item': 'via@68.137,16.874'} hole=0.36 vs via P0.15 @69.300,15.350 why=None
- In1.Cu (68.7, 16.4)–(80.14, 16.4) ok=True foreign=0.2457 vs {'net': 'VDD2', 'item': 'via@68.137,16.874'} power=0.2457 vs {'net': 'VDD2', 'item': 'via@68.137,16.874'} hole=0.4457 vs via VDD2 @68.137,16.874 why=None
- In1.Cu (80.14, 16.4)–(80.14, 19.125833) ok=True foreign=None vs None power=None vs None hole=None vs None why=None

## Gate

KEEP. In1 west/north bypass, 9 new segments, no new via, from existing through-via (39.75, 41.10) onto existing through-via (80.14, 19.125833). Straight F.Cu chord not used (VDD1). Skirt slot and sealed pocket not used. Whole-segment crossings: 0. P0.00 opens 1→0. Unconnected 54→53. Foreign 0.16 mm vs {'net': 'MIPI_VIO', 'item': 'via@24.650,24.400'}. POWER 0.2457 mm vs {'net': 'VDD2', 'item': 'via@68.137,16.874'}. short/clearance/crossing/hole 0/0/0/0. hole_to_hole 1. GND islands 12→12 (waived). Other non-GND gained: none. Four skirts, SIM_CLK, and SIM_RST not ripped or stacked. No other net.

## DRC

| | unconnected | P0.00 | short | clearance | crossing | hole | hole_to_hole | GND islands |
| --- | --- | --- | --- | --- | --- | --- | --- | --- |
| before | 54 | 1 | 0 | 0 | 0 | 0 | 1 | 12 |
| after | 53 | 0 | 0 | 0 | 0 | 0 | 1 | 12 |

No other non-GND net gained an open.
P0.16 / P0.17 / P0.19 / P0.20 skirts not ripped and not stacked. SIM_CLK and SIM_RST not ripped and not stacked. Skirt slot and sealed pocket not used. No other net. No Gerbers. No git commit.

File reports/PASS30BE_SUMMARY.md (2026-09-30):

# PASS30BE_SUMMARY — SIM_RST

**Timestamp:** 2026-09-30 17:18 IST
**KiCad:** 9.0.2
**Decision:** **KEEP**
**Net:** SIM_RST
**Git HEAD:** `2201658b04f89bfdfeeced2907dfc9a9eb94ee8d`
**PCB blob at start:** `036e870670d173055c85ca41c994405c95fbb4e8`
**PCB blob at end:** `625ef9d7ba5150f27306905b448cc93eee4f59d9`
**Expected tip/blob matched:** True / True
**Ends already one island:** False
**Far island layers:** ['F.Cu', 'In1.Cu', 'In2.Cu', 'B.Cu']
**Far island B.Cu-only:** False
**Far through-vias:** [{'name': 'via@79.376,58.050', 'xy': [79.376, 58.05]}, {'name': 'via@79.300,36.000', 'xy': [79.3, 36.0]}, {'name': 'via@78.000,36.000', 'xy': [78.0, 36.0]}, {'name': 'via@79.376,57.250', 'xy': [79.376, 57.25]}, {'name': 'via@71.030,49.126', 'xy': [71.03, 49.126]}]
**U1 island layers:** ['F.Cu']
**Pad-edge (U1.43 to B.Cu x=71.68 track):** 42.124496 mm (census 42.124)
**P0.25 flank x=32.71 copper clearance:** 0.15 mm (stored x nm 32710000; under 0.15: False)
**P0.25 x decision:** rejected as a through-run. Clearance is exactly 0.150 mm, not under the gate, but the north continuation crosses SIM_CLK In1 at (32.71, 22.665). Kept route does not pass that via.
**New via:** yes (32.75, 25.50) 0.50/0.30 through
**New segments:** 9 (limit 10)
**Crossing test failed:** False
**Min foreign clearance:** 0.16 mm vs {'net': 'COEX0', 'item': 'B.Cu trk (32.25,22.00)-(32.25,30.50)'}
**Min POWER/VIN clearance:** 0.2358 mm vs {'net': 'VDD1', 'item': 'via@49.438,16.874'}
**Min hole clearance:** 0.31 mm vs via MAGPIO2 @26.750,23.100
**SIM_RST opens:** 1 → 0
**Unconnected:** 55 → 54
**GND islands:** 12 → 12 (waived)

## Islands

U1 island: ['U1.43']
Far island: ['TP4.1', 'U4.6', 'C36.1', 'F.Cu (78.000,36.000)-(79.300,36.000)', 'F.Cu (78.250,56.600)-(78.250,57.050)', 'F.Cu (71.030,48.000)-(71.030,49.126)', 'F.Cu (71.680,48.000)-(71.030,48.000)', 'F.Cu (78.250,57.050)-(79.376,57.050)', 'F.Cu (79.376,57.050)-(79.376,58.050)', 'via@79.376,58.050', 'via@79.300,36.000', 'via@78.000,36.000', 'via@79.376,57.250', 'via@71.030,49.126', 'B.Cu (71.680,43.800)-(71.680,48.000)', 'B.Cu (71.680,48.000)-(71.680,43.800)', 'B.Cu (79.376,57.250)-(79.376,58.050)', 'B.Cu (71.680,43.800)-(78.250,43.800)', 'B.Cu (71.680,43.800)-(78.000,43.800)', 'B.Cu (78.250,56.600)-(74.000,56.600)', 'B.Cu (71.680,43.800)-(78.000,43.800)', 'B.Cu (78.000,43.800)-(78.000,36.000)', 'B.Cu (78.250,43.800)-(71.680,43.800)', 'B.Cu (71.680,48.000)-(71.680,43.800)', 'B.Cu (71.030,49.126)-(71.680,48.000)', 'B.Cu (74.000,43.800)-(71.680,43.800)', 'B.Cu (71.680,48.000)-(71.680,43.800)', 'B.Cu (79.376,57.250)-(78.250,56.600)', 'B.Cu (74.000,56.600)-(74.000,43.800)', 'B.Cu (78.000,36.000)-(78.000,43.800)', 'B.Cu (78.000,43.800)-(78.000,36.000)']

## Straight chord

F.Cu 0.18 mm [32.897, 27.128] → [71.597, 43.764], length 42.124179 mm. Crosses SiP body: True. VDD1 {'track': [50.68, 35.0, 50.68, 31.0], 'width_mm': 0.4, 'proper_cross': True, 'edge_clearance_mm': -0.29000000000000004}. Not used.

## P0.25 flank

Via: {'xy': [33.25, 23.1], 'width_mm': 0.6, 'radius_mm': 0.3, 'drill_mm': 0.3, 'pos_nm': [33250000, 23100000]}

- x=32.71 stored_nm=32710000 copper=0.150000 mm hole=0.300000 mm under_0.15=False
- x=32.70 stored_nm=32700000 copper=0.160000 mm hole=0.310000 mm under_0.15=False
- x=32.69 stored_nm=32689999 copper=0.170001 mm hole=0.320000 mm under_0.15=False

## Whole-segment crossing test

segment-vs-segment interior intersection plus 0.05 mm samples, against P0.16, P0.17, P0.19, P0.20, and the SIM_CLK In1 run. Layers are not exempt. A same-centerline stack on x=44.25, x=44.60, or the y=63.20 eastbounds is a fail. Endpoint-only touches are not crossings.
Crossings: **0**. Min centerline to a locked run: **0.6 mm** vs {'net': 'SIM_CLK', 'segment': [[57.2, 36.0], [73.3, 36.0]]}.

- (32.71, 26.4) → (32.75, 25.5) crossed=False nearest SIM_CLK [[31.25, 23.1], [33.6, 22.4]] center 2.7283 mm (edge 2.5483 mm), 19 samples
- (32.75, 25.5) → (26.2, 25.5) crossed=False nearest SIM_CLK [[31.25, 23.1], [33.6, 22.4]] center 2.4 mm (edge 2.22 mm), 132 samples
- (26.2, 25.5) → (26.2, 17.6) crossed=False nearest SIM_CLK [[31.25, 23.1], [33.6, 22.4]] center 5.05 mm (edge 4.87 mm), 158 samples
- (26.2, 17.6) → (55.3, 17.6) crossed=False nearest SIM_CLK [[33.6, 22.4], [33.6, 19.2]] center 1.6 mm (edge 1.42 mm), 582 samples
- (55.3, 17.6) → (55.3, 18.5) crossed=False nearest SIM_CLK [[56.0, 20.05], [56.0, 19.55]] center 1.2619 mm (edge 1.0819 mm), 18 samples
- (55.3, 18.5) → (68.0, 18.5) crossed=False nearest SIM_CLK [[56.0, 20.05], [56.0, 19.55]] center 1.05 mm (edge 0.87 mm), 255 samples
- (68.0, 18.5) → (68.0, 35.4) crossed=False nearest SIM_CLK [[57.2, 36.0], [73.3, 36.0]] center 0.6 mm (edge 0.42 mm), 338 samples
- (68.0, 35.4) → (78.0, 35.4) crossed=False nearest SIM_CLK [[57.2, 36.0], [73.3, 36.0]] center 0.6 mm (edge 0.42 mm), 201 samples
- (78.0, 35.4) → (78.0, 36.0) crossed=False nearest SIM_CLK [[57.2, 36.0], [73.3, 36.0]] center 4.7 mm (edge 4.52 mm), 13 samples

## Attempt

F.Cu neck plus In1.Cu, one 0.50/0.30 through-via. Kept.

- via (32.75, 25.50) drill 0.30 diameter 0.50 through
- (32.71, 26.4) → (32.75, 25.5) F.Cu 0.18 mm
- (32.75, 25.5) → (26.2, 25.5) In1.Cu 0.18 mm
- (26.2, 25.5) → (26.2, 17.6) In1.Cu 0.18 mm
- (26.2, 17.6) → (55.3, 17.6) In1.Cu 0.18 mm
- (55.3, 17.6) → (55.3, 18.5) In1.Cu 0.18 mm
- (55.3, 18.5) → (68.0, 18.5) In1.Cu 0.18 mm
- (68.0, 18.5) → (68.0, 35.4) In1.Cu 0.18 mm
- (68.0, 35.4) → (78.0, 35.4) In1.Cu 0.18 mm
- (78.0, 35.4) → (78.0, 36.0) In1.Cu 0.18 mm

West of the SiP on In1 at x=26.20 (east of the RF keepout x=24.2), north at y=17.60 (north of the skirt cap y=20.80 and of the SIM_CLK run), east to x=68.00, south to y=35.40 (0.60 mm centerline off the SIM_CLK y=36.00 run), east onto through-via (78.00, 36.00). x=44.25 and x=44.60 not used. Sealed y=44.60 pocket not entered. No header or U1 move. Skirts not ripped and not stacked. SIM_CLK run not ripped and not stacked. No other net.

## Clearance by segment

- via (32.75, 25.50) 0.50 mm ok=True foreign=0.16 vs {'net': 'COEX0', 'item': 'B.Cu trk (32.25,22.00)-(32.25,30.50)'} power=9.1319 hole=2.1515 vs via P0.25 @33.250,23.100
- F.Cu (32.71, 26.4)–(32.75, 25.5) ok=True foreign=0.22 vs {'net': 'GND', 'item': 'pad U1.44'} power=None vs None hole=2.2115 vs via P0.25 @33.250,23.100 why=None
- In1.Cu (32.75, 25.5)–(26.2, 25.5) ok=True foreign=1.5107 vs {'net': 'MIPI_VIO', 'item': 'via@24.650,24.400'} power=None vs None hole=1.6607 vs via MIPI_VIO @24.650,24.400 why=None
- In1.Cu (26.2, 25.5)–(26.2, 17.6) ok=True foreign=0.16 vs {'net': 'MAGPIO2', 'item': 'via@26.750,23.100'} power=None vs None hole=0.31 vs via MAGPIO2 @26.750,23.100 why=None
- In1.Cu (26.2, 17.6)–(55.3, 17.6) ok=True foreign=0.2358 vs {'net': 'VDD1', 'item': 'via@49.438,16.874'} power=0.2358 vs {'net': 'VDD1', 'item': 'via@49.438,16.874'} hole=0.4358 vs via VDD1 @49.438,16.874 why=None
- In1.Cu (55.3, 17.6)–(55.3, 18.5) ok=True foreign=0.3354 vs {'net': 'VDD_nRF', 'item': 'via@56.087,17.350'} power=0.3354 vs {'net': 'VDD_nRF', 'item': 'via@56.087,17.350'} hole=0.5354 vs via VDD_nRF @56.087,17.350 why=None
- In1.Cu (55.3, 18.5)–(68.0, 18.5) ok=True foreign=0.5179 vs {'net': 'VDD2', 'item': 'via@68.790,19.126'} power=0.5179 vs {'net': 'VDD2', 'item': 'via@68.790,19.126'} hole=0.7179 vs via VDD2 @68.790,19.126 why=None
- In1.Cu (68.0, 18.5)–(68.0, 35.4) ok=True foreign=0.3 vs {'net': 'VDD2', 'item': 'via@68.790,19.126'} power=0.3 vs {'net': 'VDD2', 'item': 'via@68.790,19.126'} hole=0.5 vs via VDD2 @68.790,19.126 why=None
- In1.Cu (68.0, 35.4)–(78.0, 35.4) ok=True foreign=0.21 vs {'net': 'SIM_CLK', 'item': 'via@73.300,36.000'} power=2.91 vs {'net': 'VDD_GPIO', 'item': 'via@78.000,32.000'} hole=0.36 vs via SIM_CLK @73.300,36.000 why=None
- In1.Cu (78.0, 35.4)–(78.0, 36.0) ok=True foreign=2.91 vs {'net': 'VDD_GPIO', 'item': 'via@78.000,32.000'} power=2.91 vs {'net': 'VDD_GPIO', 'item': 'via@78.000,32.000'} hole=3.11 vs via VDD_GPIO @78.000,32.000 why=None

## Gate

KEEP. F.Cu neck plus In1 west/north bypass, 9 new segments, one 0.50/0.30 through-via at (32.75, 25.50), landing on existing through-via (78.00, 36.00). x=32.71 through-run was not used (P0.25 clearance exactly 0.150 mm, but it crosses SIM_CLK). Skirt slot and sealed pocket not used. Whole-segment crossings: 0. SIM_RST opens 1→0. Unconnected 55→54. Foreign 0.16 mm vs {'net': 'COEX0', 'item': 'B.Cu trk (32.25,22.00)-(32.25,30.50)'}. POWER 0.2358 mm vs {'net': 'VDD1', 'item': 'via@49.438,16.874'}. short/clearance/crossing/hole 0/0/0/0. hole_to_hole 1. GND islands 12→12 (waived). Other non-GND gained: none. Four skirts and the SIM_CLK run not ripped or stacked. No other net.

## DRC

| | unconnected | SIM_RST | short | clearance | crossing | hole | hole_to_hole | GND islands |
| --- | --- | --- | --- | --- | --- | --- | --- | --- |
| before | 55 | 1 | 0 | 0 | 0 | 0 | 1 | 12 |
| after | 54 | 0 | 0 | 0 | 0 | 0 | 1 | 12 |

No other non-GND net gained an open.
P0.16 / P0.17 / P0.19 / P0.20 skirts not ripped and not stacked. SIM_CLK In1 run not ripped and not stacked. No other net. No Gerbers. No git commit.

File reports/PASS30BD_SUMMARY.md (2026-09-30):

# PASS30BD_SUMMARY — SIM_CLK

**Timestamp:** 2026-09-30 13:58 IST
**KiCad:** 9.0.2
**Decision:** **KEEP**
**Net:** SIM_CLK
**Git HEAD:** `558e22168742b1b3293ff22ca9a987baccc5f8c5`
**PCB blob at start:** `2d07228fba7bf2e61497e4e15cb3c4a9b90e1d57`
**PCB blob at end:** `036e870670d173055c85ca41c994405c95fbb4e8`
**Expected tip/blob matched:** True / True
**Ends already one island:** False
**Far island layers:** ['F.Cu', 'In1.Cu', 'In2.Cu', 'B.Cu']
**U1 island layers:** ['F.Cu', 'In1.Cu', 'In2.Cu', 'B.Cu']
**Pad-edge (U1.46 to B.Cu 45.50 track):** 40.989923 mm (census 40.990)
**Existing via:** {'pos': [31.25, 23.1], 'drill_mm': 0.3, 'pad_mm': 0.6, 'top': 'F.Cu', 'bottom': 'B.Cu', 'through': True, 'on': {'F.Cu': True, 'In1.Cu': True, 'In2.Cu': True, 'B.Cu': True}}
**New via:** no
**New segments:** 9 (limit 10)
**Crossing test failed:** False
**Min foreign clearance:** 0.169 mm vs {'net': 'ENABLE', 'item': 'via@56.500,20.300'}
**Min POWER/VIN clearance:** 0.2836 mm vs {'net': 'VDD_GPIO', 'item': 'via@40.170,19.126'}
**Min hole clearance:** 0.319 mm vs via ENABLE @56.500,20.300
**SIM_CLK opens:** 1 → 0
**Unconnected:** 56 → 55
**GND islands:** 12 → 12 (waived)

## Islands

U1 island: ['U1.46', 'F.Cu (31.250,26.750)-(31.250,23.100)', 'via@31.250,23.100']
Far island: ['U4.7', 'C35.1', 'TP3.1', 'F.Cu (71.680,42.400)-(70.900,42.400)', 'F.Cu (70.900,44.000)-(70.900,42.400)', 'F.Cu (77.750,57.726)-(78.400,57.726)', 'F.Cu (72.000,36.000)-(73.300,36.000)', 'F.Cu (71.680,44.000)-(70.900,44.000)', 'F.Cu (71.680,44.000)-(71.680,42.400)', 'F.Cu (77.750,56.600)-(77.750,57.726)', 'via@70.900,42.400', 'via@78.400,57.726', 'via@73.300,36.000', 'B.Cu (71.580,57.730)-(75.500,57.730)', 'B.Cu (70.900,45.500)-(68.140,45.500)', 'B.Cu (78.400,59.150)-(78.400,57.730)', 'B.Cu (68.140,54.400)-(71.580,54.400)', 'B.Cu (70.900,42.400)-(70.900,45.500)', 'B.Cu (68.140,45.500)-(68.140,54.400)', 'B.Cu (73.300,36.000)-(73.300,42.400)', 'B.Cu (75.500,57.730)-(75.500,59.150)', 'B.Cu (71.580,54.400)-(71.580,57.730)', 'B.Cu (75.500,59.150)-(78.400,59.150)', 'B.Cu (73.300,42.400)-(70.900,42.400)']

## Straight chord

F.Cu 0.18 mm [31.397, 27.128] → [68.06, 45.46], length 40.990704 mm. Crosses SiP body: True. VDD2 via {'via_xy': [61.3, 42.0], 'via_radius_mm': 0.4, 'centerline_distance_mm': 0.0715, 'edge_clearance_mm': -0.4185}. Not used.

## Lanes checked

The four locked skirts occupy x=44.25 and x=44.60 from about y=26.5 to y=63.2, and a same-centerline stack is forbidden on every layer. East of them, x=44.93 hits P0.06 (45.150, 36.000) at -0.12 mm. West of them, x=43.92 is inside the fab body. That slot is closed, but it is not the only way out: the through-via can leave north on In1.Cu, run at y=19.20/20.05/19.55 (all north of the skirt y=20.80 cap), and drop south at x=57.20, which is east of every locked segment. F.Cu and B.Cu copies of that polyline are blocked by VDD_GPIO, DEC0, P0.15, and VDD2 tracks. In2.Cu clears the same polyline; only In1.Cu was placed.

x=44.93 remeasure: {'via_xy': [45.15, 36.0], 'radius_mm': 0.25, 'width_mm': 0.5, 'centerline_x': 44.93, 'edge_clearance_mm': -0.12}
x=43.92 inside body: True

Per-layer probe of x=44.93 from y=27.40 to y=50.00 (stops before the y=60.40 east caps so the via hit is visible):

- In1.Cu: ok=False foreign=-0.18 vs {'net': 'P0.16', 'item': 'trk (45.55,27.40)-(44.60,27.40)'} hole=-0.02 vs via P0.06 @45.150,36.000
- In2.Cu: ok=False foreign=-0.18 vs {'net': 'P0.17', 'item': 'trk (45.55,27.40)-(44.60,27.40)'} hole=-0.02 vs via P0.06 @45.150,36.000
- F.Cu: ok=False foreign=-0.12 vs {'net': 'P0.06', 'item': 'via@45.150,36.000'} hole=-0.02 vs via P0.06 @45.150,36.000
- B.Cu: ok=False foreign=-0.12 vs {'net': 'P0.06', 'item': 'via@45.150,36.000'} hole=-0.02 vs via P0.06 @45.150,36.000

## Free space from via (31.25, 23.10)

The via sits at x=31.25, inside the fab body's x-range (28–44), so a straight south run enters the body at y=26.75. Straight north dies on the COEX0 via (31.110, 22.000). East along y=23.10 dies on the P0.25 via (33.250, 23.100) before the skirt. West dies on the SIM_IO via (30.250, 23.100). F.Cu and B.Cu therefore do not reach the far island in a straight shot. The kept route leaves northeast, then runs north of the skirts.

## Whole-segment crossing test

segment-vs-segment interior intersection plus 0.05 mm samples, against P0.16, P0.17, P0.19, and P0.20, layers not exempt. A same-centerline stack on x=44.25, x=44.60, or the y=63.20 eastbounds is a fail even on another layer. Endpoint-only touches are not crossings. A sample in the interior of a locked segment is a crossing.
Crossings: **0**. Min centerline to a locked skirt: **0.75 mm** vs {'net': 'P0.16', 'segment': [[40.7, 20.8], [45.55, 20.8]]}.

Per new segment, nearest locked skirt:

- (31.25, 23.1) → (33.6, 22.4) crossed=False nearest P0.20 [[36.45, 20.8], [36.45, 26.5]] center 2.85 mm (edge 2.67 mm), 50 samples
- (33.6, 22.4) → (33.6, 19.2) crossed=False nearest P0.20 [[36.2, 20.8], [36.45, 20.8]] center 2.6 mm (edge 2.42 mm), 64 samples
- (33.6, 19.2) → (39.4, 19.2) crossed=False nearest P0.20 [[36.2, 20.8], [36.45, 20.8]] center 1.6 mm (edge 1.42 mm), 116 samples
- (39.4, 19.2) → (39.4, 20.05) crossed=False nearest P0.16 [[40.7, 20.8], [45.55, 20.8]] center 1.5008 mm (edge 1.3208 mm), 18 samples
- (39.4, 20.05) → (56.0, 20.05) crossed=False nearest P0.16 [[40.7, 20.8], [45.55, 20.8]] center 0.75 mm (edge 0.57 mm), 333 samples
- (56.0, 20.05) → (56.0, 19.55) crossed=False nearest P0.16 [[40.7, 20.8], [45.55, 20.8]] center 10.4769 mm (edge 10.2969 mm), 11 samples
- (56.0, 19.55) → (57.2, 19.55) crossed=False nearest P0.16 [[40.7, 20.8], [45.55, 20.8]] center 10.5245 mm (edge 10.3445 mm), 25 samples
- (57.2, 19.55) → (57.2, 36.0) crossed=False nearest P0.16 [[40.7, 20.8], [45.55, 20.8]] center 11.65 mm (edge 11.47 mm), 329 samples
- (57.2, 36.0) → (73.3, 36.0) crossed=False nearest P0.16 [[44.6, 27.4], [44.6, 60.4]] center 12.6 mm (edge 12.42 mm), 322 samples

## Attempt

In1.Cu 0.18 mm, no new via. Kept.

- (31.25, 23.1) → (33.6, 22.4) In1.Cu
- (33.6, 22.4) → (33.6, 19.2) In1.Cu
- (33.6, 19.2) → (39.4, 19.2) In1.Cu
- (39.4, 19.2) → (39.4, 20.05) In1.Cu
- (39.4, 20.05) → (56.0, 20.05) In1.Cu
- (56.0, 20.05) → (56.0, 19.55) In1.Cu
- (56.0, 19.55) → (57.2, 19.55) In1.Cu
- (57.2, 19.55) → (57.2, 36.0) In1.Cu
- (57.2, 36.0) → (73.3, 36.0) In1.Cu

North bypass: leave the through-via northeast to clear P0.25, run north at x=33.60 (west of SWDCLK/P0.22), east at y=19.20 under VDD_GPIO (40.170, 19.126), south to y=20.05 (still 0.75 mm north of the P0.16/P0.20 y=20.80 cap), east to x=56.00, north to y=19.55 to clear ENABLE (56.500, 20.300), east to x=57.20, south to y=36.00, east onto SIM_CLK via (73.30, 36.00). x>24.2. No header or U1 move. Fanout vias not moved. Skirts not ripped and not stacked. No other net.

## Clearance by segment

- (31.25, 23.1)–(33.6, 22.4) ok=True foreign=0.181 vs {'net': 'P0.25', 'item': 'via@33.250,23.100'} power=None vs None hole=0.331 vs via P0.25 @33.250,23.100 why=None
- (33.6, 22.4)–(33.6, 19.2) ok=True foreign=0.21 vs {'net': 'SWDCLK', 'item': 'via@34.200,19.800'} power=None vs None hole=0.36 vs via SWDCLK @34.200,19.800 why=None
- (33.6, 19.2)–(39.4, 19.2) ok=True foreign=0.21 vs {'net': 'SWDCLK', 'item': 'via@34.200,19.800'} power=0.2836 vs {'net': 'VDD_GPIO', 'item': 'via@40.170,19.126'} hole=0.36 vs via SWDCLK @34.200,19.800 why=None
- (39.4, 19.2)–(39.4, 20.05) ok=True foreign=0.2836 vs {'net': 'VDD_GPIO', 'item': 'via@40.170,19.126'} power=0.2836 vs {'net': 'VDD_GPIO', 'item': 'via@40.170,19.126'} hole=0.4836 vs via VDD_GPIO @40.170,19.126 why=None
- (39.4, 20.05)–(56.0, 20.05) ok=True foreign=0.169 vs {'net': 'ENABLE', 'item': 'via@56.500,20.300'} power=0.4342 vs {'net': 'VDD_GPIO', 'item': 'via@40.170,19.126'} hole=0.319 vs via ENABLE @56.500,20.300 why=None
- (56.0, 20.05)–(56.0, 19.55) ok=True foreign=0.169 vs {'net': 'ENABLE', 'item': 'via@56.500,20.300'} power=1.4001 vs {'net': 'VDD2', 'item': 'via@54.500,21.200'} hole=0.319 vs via ENABLE @56.500,20.300 why=None
- (56.0, 19.55)–(57.2, 19.55) ok=True foreign=0.36 vs {'net': 'ENABLE', 'item': 'via@56.500,20.300'} power=1.71 vs {'net': 'VDD_nRF', 'item': 'via@56.087,17.350'} hole=0.51 vs via ENABLE @56.500,20.300 why=None
- (57.2, 19.55)–(57.2, 36.0) ok=True foreign=0.31 vs {'net': 'ENABLE', 'item': 'via@56.500,23.800'} power=0.41 vs {'net': 'VDD2', 'item': 'via@58.000,30.950'} hole=0.46 vs via ENABLE @56.500,23.800 why=None
- (57.2, 36.0)–(73.3, 36.0) ok=True foreign=0.6358 vs {'net': 'VDD2', 'item': 'via@59.700,37.126'} power=0.6358 vs {'net': 'VDD2', 'item': 'via@59.700,37.126'} hole=0.8358 vs via VDD2 @59.700,37.126 why=None

## Gate

KEEP. In1.Cu north bypass, 9 new segments, no new via. Skirt slot (x=44.25 / x=44.60) was not the only way and was not used. Whole-segment crossing test: 0 crossings (min center to a locked skirt 0.75 mm). SIM_CLK opens 1→0. Unconnected 56→55. Foreign 0.169 mm vs {'net': 'ENABLE', 'item': 'via@56.500,20.300'}. POWER 0.2836 mm vs {'net': 'VDD_GPIO', 'item': 'via@40.170,19.126'}. short/clearance/crossing/hole 0/0/0/0. hole_to_hole 1. GND islands 12→12 (waived). Other non-GND gained: none. Four skirts not ripped or stacked. No other net.

## DRC

| | unconnected | SIM_CLK | short | clearance | crossing | hole | hole_to_hole | GND islands |
| --- | --- | --- | --- | --- | --- | --- | --- | --- |
| before | 56 | 1 | 0 | 0 | 0 | 0 | 1 | 12 |
| after | 55 | 0 | 0 | 0 | 0 | 0 | 1 | 12 |

No other non-GND net gained an open.
P0.16 / P0.17 / P0.19 / P0.20 skirts not ripped and not stacked. No new via. No other net. No Gerbers. No git commit.

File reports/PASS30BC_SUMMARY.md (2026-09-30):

# PASS30BC_SUMMARY — P0.20

**Timestamp:** 2026-09-30 13:43 IST
**KiCad:** 9.0.2
**Decision:** **KEEP**
**Net:** P0.20
**Git HEAD:** `9ad4b9475455a74a7195575b6d0cec9b6566a38e`
**PCB blob at start:** `9f2d8c0370c9ac60c5283fc3cbb2bc8b015d447a`
**PCB blob at end:** `2d07228fba7bf2e61497e4e15cb3c4a9b90e1d57`
**Expected tip/blob matched:** True / True
**Ends already one island:** False
**Far island layers:** ['F.Cu', 'In1.Cu', 'In2.Cu', 'B.Cu']
**Far island F.Cu only:** False
**U1 island layers:** ['F.Cu', 'In1.Cu', 'In2.Cu', 'B.Cu']
**Pad-edge (U1.35 to F.Cu 55.78 stub):** 38.594909 mm (census 38.595)
**Existing via:** {'pos': [36.2, 20.8], 'drill_mm': 0.3, 'pad_mm': 0.6, 'top': 'F.Cu', 'bottom': 'B.Cu', 'through': True, 'on': {'F.Cu': True, 'In1.Cu': True, 'In2.Cu': True, 'B.Cu': True}}
**New via:** no
**Third In1 skirt:** no
**New segments:** 9 (limit 10)
**Crossing test failed:** False
**Min foreign clearance:** 0.17 mm vs {'net': 'P0.17', 'item': 'trk (44.60,27.40)-(44.60,60.40)'}
**Min POWER/VIN clearance:** 0.2736 mm vs {'net': 'VDD2', 'item': 'via@44.722,25.900'}
**Min hole clearance:** 0.3397 mm vs via P0.06 @44.000,39.900
**P0.20 opens:** 1 → 0
**Unconnected:** 57 → 56
**GND islands:** 12 → 12 (waived)

## Islands

U1 island: ['U1.35', 'F.Cu (36.750,26.750)-(36.200,20.800)', 'via@36.200,20.800']
Far island: ['J18.8', 'J13.5', 'F.Cu (55.780,62.000)-(55.780,60.900)', 'F.Cu (74.160,60.900)-(74.160,76.000)', 'F.Cu (55.780,60.900)-(74.160,60.900)']

## Straight chord

F.Cu 0.18 mm (36.878, 27.147) → (55.736, 60.821), length 38.59485 mm. Crosses SiP body: True. P0.06 via {'via_xy': [44.0, 39.9], 'via_radius_mm': 0.3, 'centerline_distance_mm': 0.0174, 'edge_clearance_mm': -0.3726}. Not used.

## Layer exit from (36.20, 20.80)

F.Cu and B.Cu (and In1/In2 on this same x) die at the P0.21 via (35.750, 23.100), before y=26.5. The neighbor vias at x=39.25/40.25 were the ones that died at y=26.5. This via is through-hole to In2, so the route jogs to x=36.45 on In2 and does not punch a new via.

## Whole-segment crossing test

segment-vs-segment interior intersection plus 0.05 mm samples, against P0.16, P0.17, and P0.19, layers not exempt. Collinear overlap with P0.19 is the x=44.25 In2 slot, not a crossing. Endpoint-only touches are not crossings. A sample in the interior of a locked segment is a crossing.
Crossings: **0**. Min centerline to P0.16/P0.17: **0.35 mm** vs {'net': 'P0.16', 'segment': [[45.55, 27.4], [44.6, 27.4]]}. Min centerline to P0.19: **0.0 mm** (0 means the same-centerline slot, not a transverse cross). Stacks recorded: 6.

Per new segment, nearest of P0.16/P0.17:

- (36.20, 20.80) → (36.45, 20.80) crossed=False nearest P0.17 [[40.25, 23.1], [40.25, 21.5]] center 3.8639 mm (edge 3.6839 mm), 6 samples
- (36.45, 20.80) → (36.45, 26.50) crossed=False nearest P0.17 [[40.25, 23.1], [40.25, 21.5]] center 3.8 mm (edge 3.62 mm), 114 samples
- (36.45, 26.50) → (44.25, 26.50) crossed=False nearest P0.16 [[45.55, 27.4], [44.6, 27.4]] center 0.9657 mm (edge 0.7857 mm), 156 samples
- (44.25, 26.50) → (44.25, 39.10) crossed=False nearest P0.16 [[45.55, 27.4], [44.6, 27.4]] center 0.35 mm (edge 0.17 mm), 253 samples
- (44.25, 39.10) → (42.80, 39.90) crossed=False nearest P0.16 [[44.6, 27.4], [44.6, 60.4]] center 0.35 mm (edge 0.17 mm), 34 samples
- (42.80, 39.90) → (44.25, 40.70) crossed=False nearest P0.16 [[44.6, 27.4], [44.6, 60.4]] center 0.35 mm (edge 0.17 mm), 34 samples
- (44.25, 40.70) → (44.25, 63.20) crossed=False nearest P0.16 [[44.6, 27.4], [44.6, 60.4]] center 0.35 mm (edge 0.17 mm), 451 samples
- (44.25, 63.20) → (55.78, 63.20) crossed=False nearest P0.17 [[48.16, 60.4], [48.16, 61.3]] center 1.9 mm (edge 1.72 mm), 231 samples
- (55.78, 63.20) → (55.78, 62.00) crossed=False nearest P0.17 [[48.16, 60.4], [48.16, 61.3]] center 7.6521 mm (edge 7.4721 mm), 25 samples

## Why not y=61.63

J18 pads are 1.700 mm circles on y=62.000. y=61.63 is inside the pad copper. Not placed.
Probe (44.25, 61.63)–(55.78, 61.63) foreign 0.0 mm vs {'net': 'P0.16', 'item': 'pad J18.4'}.

## No-dodge check

{'ok': False, 'foreign_mm': -0.14, 'foreign_item': {'net': 'P0.06', 'item': 'via@44.000,39.900'}, 'hole_mm': 0.01, 'hole_item': 'via P0.06 @44.000,39.900', 'why': 'x=44.25 passes 0.25 mm from P0.06 via (44.000, 39.900). Edge clearance is negative. Dodge required. P0.19 dodge not ripped.'}

## Attempt

In2.Cu 0.18 mm, no new via. Kept.

- (36.20, 20.80) → (36.45, 20.80) In2.Cu
- (36.45, 20.80) → (36.45, 26.50) In2.Cu
- (36.45, 26.50) → (44.25, 26.50) In2.Cu
- (44.25, 26.50) → (44.25, 39.10) In2.Cu
- (44.25, 39.10) → (42.80, 39.90) In2.Cu
- (42.80, 39.90) → (44.25, 40.70) In2.Cu
- (44.25, 40.70) → (44.25, 63.20) In2.Cu
- (44.25, 63.20) → (55.78, 63.20) In2.Cu
- (55.78, 63.20) → (55.78, 62.00) In2.Cu

x=36.45 clears the P0.21 via (35.750, 23.100) that blocks a straight south exit. y=26.50 then x=44.25 is the In2 slot beside the P0.17 skirt (x=44.60) and on the P0.19 centerline. West dodge (44.25, 39.10)→(42.80, 39.90)→(44.25, 40.70) around P0.06 via (44.000, 39.900). Eastbound y=63.20, then north onto J18.8 (55.78, 62.00). No third In1 skirt. No via punched into the F.Cu stub. Skirts and the P0.19 run not ripped. x>24.2. No other net.

## Clearance by segment

- (36.20, 20.80)–(36.45, 20.80) ok=True foreign=0.9186 vs {'net': 'P0.22', 'item': 'via@35.250,19.900'} power=None vs None hole=1.0686 vs via P0.22 @35.250,19.900 why=None
- (36.45, 20.80)–(36.45, 26.50) ok=True foreign=0.31 vs {'net': 'P0.21', 'item': 'via@35.750,23.100'} power=None vs None hole=0.46 vs via P0.21 @35.750,23.100 why=None
- (36.45, 26.50)–(44.25, 26.50) ok=True foreign=0.2736 vs {'net': 'VDD2', 'item': 'via@44.722,25.900'} power=0.2736 vs {'net': 'VDD2', 'item': 'via@44.722,25.900'} hole=0.4736 vs via VDD2 @44.722,25.900 why=None
- (44.25, 26.50)–(44.25, 39.10) ok=True foreign=0.17 vs {'net': 'P0.17', 'item': 'trk (44.60,27.40)-(44.60,60.40)'} power=0.2736 vs {'net': 'VDD2', 'item': 'via@44.722,25.900'} hole=0.4736 vs via VDD2 @44.722,25.900 why=None
- (44.25, 39.10)–(42.80, 39.90) ok=True foreign=0.17 vs {'net': 'P0.17', 'item': 'trk (44.60,27.40)-(44.60,60.40)'} power=None vs None hole=0.3397 vs via P0.06 @44.000,39.900 why=None
- (42.80, 39.90)–(44.25, 40.70) ok=True foreign=0.17 vs {'net': 'P0.17', 'item': 'trk (44.60,27.40)-(44.60,60.40)'} power=None vs None hole=0.3397 vs via P0.06 @44.000,39.900 why=None
- (44.25, 40.70)–(44.25, 63.20) ok=True foreign=0.17 vs {'net': 'P0.17', 'item': 'trk (44.60,60.40)-(48.16,60.40)'} power=None vs None hole=0.56 vs via ENABLE @43.400,45.126 why=None
- (44.25, 63.20)–(55.78, 63.20) ok=True foreign=0.26 vs {'net': 'P0.16', 'item': 'pad J18.4'} power=1.8692 vs {'net': 'VDD_GPIO', 'item': 'pad J18.9'} hole=0.61 vs hole J18.4 [P0.16] why=None
- (55.78, 63.20)–(55.78, 62.00) ok=True foreign=1.6 vs {'net': 'P0.19', 'item': 'pad J18.7'} power=1.6 vs {'net': 'VDD_GPIO', 'item': 'pad J18.9'} hole=1.95 vs hole J18.7 [P0.19] why=None

## Gate

KEEP. In2.Cu x=44.25 slot, 9 new segments, no new via. Whole-segment crossing test: 0 crossings (min center to P0.16/P0.17 0.35 mm; P0.19 same-centerline stacks 6, not crossings). P0.20 opens 1→0. Unconnected 57→56. Foreign 0.17 mm vs {'net': 'P0.17', 'item': 'trk (44.60,27.40)-(44.60,60.40)'}. POWER 0.2736 mm vs {'net': 'VDD2', 'item': 'via@44.722,25.900'}. short/clearance/crossing/hole 0/0/0/0. hole_to_hole 1. GND islands 12→12 (waived). Other non-GND gained: none. No third In1 skirt. Skirts and P0.19 not ripped.

## DRC

| | unconnected | P0.20 | short | clearance | crossing | hole | hole_to_hole | GND islands |
| --- | --- | --- | --- | --- | --- | --- | --- | --- |
| before | 57 | 1 | 0 | 0 | 0 | 0 | 1 | 12 |
| mid | 56 | 0 | 0 | 0 | 0 | 0 | 1 | 12 |
| after | 56 | 0 | 0 | 0 | 0 | 0 | 1 | 12 |

No other non-GND net gained an open.
P0.16 / P0.17 skirts and the P0.19 run not ripped. No third In1 skirt. No new via. No other net. No Gerbers. No git commit.

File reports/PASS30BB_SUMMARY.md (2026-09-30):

# PASS30BB_SUMMARY — P0.19

**Timestamp:** 2026-09-30 13:32 IST
**KiCad:** 9.0.2
**Decision:** **KEEP**
**Net:** P0.19
**Git HEAD:** `816310c76593afe19c905ba35450d05129ac5a6f`
**PCB blob at start:** `e1adfbd7a38989b42abaef3557368955484cd560`
**PCB blob at end:** `9f2d8c0370c9ac60c5283fc3cbb2bc8b015d447a`
**U1.30 and J18.7 same island:** False
**Pad-edge:** 36.658325 mm
**New via:** no
**New segments:** 8 (limit 10)
**Skirts crossed:** False
**Skirts ripped:** no
**Min foreign clearance:** 0.17 mm vs {'net': 'P0.16', 'item': 'trk (44.60,27.40)-(44.60,60.40)'}
**Min POWER/VIN clearance:** 0.2736 mm vs {'net': 'VDD2', 'item': 'via@44.722,25.900'}
**Min hole clearance:** 0.3397 mm vs via P0.06 @44.000,39.900
**P0.19 opens:** 1 → 0
**Unconnected:** 58 → 57
**GND islands:** 12 → 12 (waived)

## Whole-segment skirt test

segment-vs-segment intersection plus 0.05 mm samples along each new segment, both skirts, layers not exempt.
Crossings: **0**. Min centerline distance to either skirt: **0.35 mm** vs {'net': 'P0.16', 'segment': [[45.55, 27.4], [44.6, 27.4]]}.
Both P0.16 (In1.Cu) and P0.17 (In2.Cu) were tested. Different layers were not treated as allowed to cross.

Per new segment, nearest skirt:

- (39.25, 23.10) → (39.25, 26.50) crossed=False nearest P0.17 [[40.25, 23.1], [40.25, 21.5]] center 1.0 mm (edge 0.82 mm), 68 samples
- (39.25, 26.50) → (44.25, 26.50) crossed=False nearest P0.16 [[45.55, 27.4], [44.6, 27.4]] center 0.9657 mm (edge 0.7857 mm), 101 samples
- (44.25, 26.50) → (44.25, 39.10) crossed=False nearest P0.16 [[45.55, 27.4], [44.6, 27.4]] center 0.35 mm (edge 0.17 mm), 253 samples
- (44.25, 39.10) → (42.80, 39.90) crossed=False nearest P0.16 [[44.6, 27.4], [44.6, 60.4]] center 0.35 mm (edge 0.17 mm), 34 samples
- (42.80, 39.90) → (44.25, 40.70) crossed=False nearest P0.16 [[44.6, 27.4], [44.6, 60.4]] center 0.35 mm (edge 0.17 mm), 34 samples
- (44.25, 40.70) → (44.25, 63.20) crossed=False nearest P0.16 [[44.6, 27.4], [44.6, 60.4]] center 0.35 mm (edge 0.17 mm), 451 samples
- (44.25, 63.20) → (53.24, 63.20) crossed=False nearest P0.17 [[48.16, 60.4], [48.16, 61.3]] center 1.9 mm (edge 1.72 mm), 180 samples
- (53.24, 63.20) → (53.24, 62.00) crossed=False nearest P0.17 [[48.16, 60.4], [48.16, 61.3]] center 5.128 mm (edge 4.948 mm), 25 samples

## Why not y=61.63

J18 pads are 1.700 mm circles on y=62.000. y=61.63 is inside J18.4 (P0.16), J18.5 (P0.17) and J18.6 (P0.18). Blocked. Not placed.
Clearance of (44.25, 61.63)–(53.24, 61.63): foreign 0.0 mm vs {'net': 'P0.16', 'item': 'pad J18.4'}; hole -0.22 mm vs hole J18.4 [P0.16].
J18.7 is a 1.700 mm circle at (53.240, 62.000), drill 1.000 mm, on In1.Cu. Pad copper runs y=61.15–62.85. The P0.17 end cap stops at y=61.30 on x=48.16, which is J18.5's center, so there is no corridor between the end cap and the pad. The open eastbound is south of the pads.

## Attempt

In1.Cu 0.18 mm, no new via. Kept. Corners:

- (39.25, 23.10) → (39.25, 26.50) In1.Cu
- (39.25, 26.50) → (44.25, 26.50) In1.Cu
- (44.25, 26.50) → (44.25, 39.10) In1.Cu
- (44.25, 39.10) → (42.80, 39.90) In1.Cu
- (42.80, 39.90) → (44.25, 40.70) In1.Cu
- (44.25, 40.70) → (44.25, 63.20) In1.Cu
- (44.25, 63.20) → (53.24, 63.20) In1.Cu
- (53.24, 63.20) → (53.24, 62.00) In1.Cu

West dodge (44.25, 39.10)→(42.80, 39.90)→(44.25, 40.70) is around P0.06 via (44.000, 39.900). Vertical x=44.25 is 0.35 mm center-to-center from the locked x=44.60 skirts (edge 0.17 mm) and passes between J18.3 (43.08, 62.00) and J18.4 (45.62, 62.00). Eastbound y=63.20 is 1.90 mm south of the P0.17 end cap (y=61.30) and 0.26 mm off the J18 pad copper. North stub ends at the J18.7 center, not past the pad. x>24.2. No new via. P0.17 not retried. No other net.

## Clearance by segment

- (39.25, 23.10)–(39.25, 26.50) ok=True foreign=0.61 vs {'net': 'P0.17', 'item': 'via@40.250,23.100'} power=None vs None hole=0.76 vs via P0.17 @40.250,23.100 why=None
- (39.25, 26.50)–(44.25, 26.50) ok=True foreign=0.2736 vs {'net': 'VDD2', 'item': 'via@44.722,25.900'} power=0.2736 vs {'net': 'VDD2', 'item': 'via@44.722,25.900'} hole=0.4736 vs via VDD2 @44.722,25.900 why=None
- (44.25, 26.50)–(44.25, 39.10) ok=True foreign=0.17 vs {'net': 'P0.16', 'item': 'trk (44.60,27.40)-(44.60,60.40)'} power=0.2736 vs {'net': 'VDD2', 'item': 'via@44.722,25.900'} hole=0.4736 vs via VDD2 @44.722,25.900 why=None
- (44.25, 39.10)–(42.80, 39.90) ok=True foreign=0.17 vs {'net': 'P0.16', 'item': 'trk (44.60,27.40)-(44.60,60.40)'} power=None vs None hole=0.3397 vs via P0.06 @44.000,39.900 why=None
- (42.80, 39.90)–(44.25, 40.70) ok=True foreign=0.17 vs {'net': 'P0.16', 'item': 'trk (44.60,27.40)-(44.60,60.40)'} power=None vs None hole=0.3397 vs via P0.06 @44.000,39.900 why=None
- (44.25, 40.70)–(44.25, 63.20) ok=True foreign=0.17 vs {'net': 'P0.16', 'item': 'trk (44.60,60.40)-(45.62,60.40)'} power=None vs None hole=0.56 vs via ENABLE @43.400,45.126 why=None
- (44.25, 63.20)–(53.24, 63.20) ok=True foreign=0.26 vs {'net': 'P0.16', 'item': 'pad J18.4'} power=None vs None hole=0.61 vs hole J18.4 [P0.16] why=None
- (53.24, 63.20)–(53.24, 62.00) ok=True foreign=1.6 vs {'net': 'P0.18', 'item': 'pad J18.6'} power=None vs None hole=1.95 vs hole J18.6 [P0.18] why=None

## Gate

KEEP. In1.Cu south of both end caps, 8 new segments, no new via. Whole-segment skirt test: 0 crossings (min center distance 0.35 mm). P0.19 opens 1→0. Unconnected 58→57. Foreign 0.17 mm vs {'net': 'P0.16', 'item': 'trk (44.60,27.40)-(44.60,60.40)'}. POWER 0.2736 mm vs {'net': 'VDD2', 'item': 'via@44.722,25.900'}. short/clearance/crossing/hole 0/0/0/0. hole_to_hole 1. GND islands 12→12 (waived). Other non-GND gained: none. Skirts not crossed or ripped. P0.17 not retried.

## DRC

| | unconnected | P0.19 | short | clearance | crossing | hole | hole_to_hole | GND islands |
| --- | --- | --- | --- | --- | --- | --- | --- | --- |
| before | 58 | 1 | 0 | 0 | 0 | 0 | 1 | 12 |
| mid | 57 | 0 | 0 | 0 | 0 | 0 | 1 | 12 |
| after | 57 | 0 | 0 | 0 | 0 | 0 | 1 | 12 |

No other non-GND net gained an open.
Locked copper not ripped. P0.16 and P0.17 skirts not crossed and not ripped. P0.17 not retried. No other net. No Gerbers. No git commit.

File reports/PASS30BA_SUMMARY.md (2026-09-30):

# PASS30BA_SUMMARY — P0.19

**Timestamp:** 2026-09-30 13:23 IST
**KiCad:** 9.0.2
**Decision:** **NO-ROUTE**
**Net:** P0.19
**Git HEAD:** `019630abc7962b82bee07d5c52f7057c9bbcceff`
**PCB blob at start:** `e1adfbd7a38989b42abaef3557368955484cd560`
**U1.30 and J18.7 same island:** False
**New via:** no
**New segments:** 0 (limit 8)
**Min foreign clearance:** 0.17 mm vs {'net': 'P0.16', 'item': 'trk (44.60,27.40)-(44.60,60.40)'}
**Min POWER/VIN clearance:** 0.2736 mm vs {'net': 'VDD2', 'item': 'via@44.722,25.900'}
**Min hole clearance:** 0.3397 mm vs via P0.06 @44.000,39.900
**P0.19 opens:** 1 → 1
**Unconnected:** 58 → 58
**GND islands:** 12 → 12 (waived)

## Endpoints

U1.30 center [39.25, 26.75], copper point [39.378, 27.147]. Existing exit F.Cu (39.25, 26.75)–(39.25, 23.10) and through-via (39.25, 23.10) were not ripped. J18.7 center [53.24, 62.0] (census point [52.993, 61.187] is inside the 1.7 mm pad, not the center). Same island: **False**. Islands: 2.

U1 island: U1.30, F.Cu (39.250,26.750)-(39.250,23.100), via@39.250,23.100.

J18 island: J18.7, J13.4, F.Cu (64.000,64.000)-(66.400,64.000), via@66.400,64.000, via@64.000,64.000, B.Cu (53.240,64.000)-(64.000,64.000), B.Cu (66.400,64.000)-(71.620,64.000), B.Cu (53.240,62.000)-(53.240,64.000), B.Cu (71.620,64.000)-(71.620,76.000).

## Pad-edge

Remeasured F.Cu effective-shape clearance U1.30↔J18.7: **36.658325 mm** (reported 36.658 mm). Census chord length between [39.378, 27.147] and [52.993, 61.187] is 36.662 mm. U1.30 is F.Cu only, so there is no inner-layer pad-edge.

## Straight chord (not used)

0.18 mm F.Cu chord (39.378, 27.147) → (52.993, 61.187), length 36.662 mm. Crosses the SiP fab body (x 28.0–44.0, y 26.75–37.25): **True**. VDD1 F.Cu (50.52, 38.00)–(43.25, 38.00) w=0.40: the chord centerline intersects that track, so the signed edge clearance is **−0.29 mm** (−(0.09+0.20)). Not used.

Foreign items under 0.15 mm on that chord: 12. POWER/VIN under 0.20 mm: 7.

## Layers checked

Existing via (39.25, 23.10) drill 0.3 mm, pad 0.6 mm, F.Cu to B.Cu. On layers: {'F.Cu': True, 'In1.Cu': True, 'In2.Cu': True, 'B.Cu': True}. Through-via, so the route starts on a layer it already hits. No second via.

- F.Cu: {'cells': 254, 'bbox': [37.75, 40.5, 16.0, 26.5], 'ymax': 26.5, 'xmax': 40.5, 'reaches_j18': False}
- B.Cu: {'cells': 652, 'bbox': [32.75, 46.25, 16.0, 26.5], 'ymax': 26.5, 'xmax': 46.25, 'reaches_j18': False}
- In1.Cu: {'cells': 35483, 'bbox': [24.5, 72.0, 16.0, 70.0], 'ymax': 70.0, 'xmax': 72.0, 'reaches_j18': True}
- In2.Cu: {'cells': 35450, 'bbox': [24.5, 72.0, 16.0, 70.0], 'ymax': 70.0, 'xmax': 72.0, 'reaches_j18': True}

F.Cu and B.Cu free space from the via both die at ymax 26.5, short of J18.7, same wall as the P0.16/P0.17 vias. A second via was not added. In1.Cu and In2.Cu both flood-fill to J18.7. Both inner layers already carry a locked skirt at x=44.60 (P0.16 on In1, P0.17 on In2). The P0.06 via (45.150, 36.000) r=0.25 still closes the strip immediately east of x=44.60 (clearance at x=44.93 is -0.12 mm). The west offset x=44.25 clears that via (0.56 mm) and sits 0.35 mm from the skirt. A second P0.06 via at (44.000, 39.900) blocks x=44.25 at y≈39.9, so the route dodges west of it south of the fab body, then returns. In1 was the one attempt (GND plane; extra islands waived). The eastbound was drawn at y=60.00 on the belief the P0.16 vertical ended before it; that vertical runs to y=60.40, so the segment crosses it. In2 was not used (VDD_nRF zone clearance 0.5 mm, and the P0.17 end cap runs to x=48.16). No sealed B.Cu pocket. x>24.2.

P0.06 via check: {'net': 'P0.06', 'at': [45.15, 36.0], 'radius_mm': 0.25, 'need_dx_mm': 0.49, 'skirt_x': 44.6, 'east_of_skirt_x': 44.93, 'clearance_at_x_44_93_mm': -0.12, 'clearance_at_x_44_25_mm': 0.56, 'east_strip_closed': True, 'west_x_44_25_clears_this_via': True}.

## Attempt

One In1.Cu jog, 0.18 mm, no new via. Added, then removed. Corners:

- (39.25, 23.10) → (39.25, 26.50)
- (39.25, 26.50) → (44.25, 26.50)
- (44.25, 26.50) → (44.25, 39.10)
- (44.25, 39.10) → (42.80, 39.90)
- (42.80, 39.90) → (44.25, 40.70)
- (44.25, 40.70) → (44.25, 60.00)
- (44.25, 60.00) → (53.24, 60.00)
- (53.24, 60.00) → (53.24, 61.40)

x=44.25 is 0.35 mm center-to-center from the locked x=44.60 skirts. The two diagonals dodge P0.06 via (44.000, 39.900). The eastbound segment (44.25, 60.00)–(53.24, 60.00) crosses the locked P0.16 In1 skirt (44.60, 27.40)–(44.60, 60.40) at (44.60, 60.00). Endpoint clearance to that skirt was 0.17 mm and missed the interior intersection. DRC `tracks_crossing` = 1 on that pair. P0.19 opens went 1→0 on the mid board. Full restore from `.mcp-backups/pass30ba/pre-edit.kicad_pcb`. No second path.

## Gate

NO-ROUTE. Mid short/clearance/crossing/hole 0/0/1/0. hole_to_hole 1→1. Other non-GND gained: none. Foreign pre-add 0.17 mm vs P0.16 skirt (44.60, 27.40)–(44.60, 60.40) is the endpoint figure; the real fail is the crossing of that skirt. POWER pre-add 0.2736 mm vs VDD2 via (44.722, 25.900). Post-revert DRC matches pre-edit: unconnected 58, P0.19 1, short/clearance/crossing/hole 0/0/0/0, hole_to_hole 1, GND islands 12.

## DRC

| | unconnected | P0.19 | short | clearance | crossing | hole | hole_to_hole | GND islands |
| --- | --- | --- | --- | --- | --- | --- | --- | --- |
| before | 58 | 1 | 0 | 0 | 0 | 0 | 1 | 12 |
| mid (reverted) | 57 | 0 | 0 | 0 | 1 | 0 | 1 | 12 |
| after restore | 58 | 1 | 0 | 0 | 0 | 0 | 1 | 12 |

No other non-GND net gained an open.
Locked copper not ripped. P0.17 not retried. No other net. No Gerbers. No git commit.

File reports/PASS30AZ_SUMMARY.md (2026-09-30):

# PASS30AZ_SUMMARY — P0.17

**Timestamp:** 2026-09-30 13:09 IST
**KiCad:** 9.0.2
**Decision:** **NO-ROUTE**
**Net:** P0.17
**Git HEAD:** `8942891b2a70c7fe722dc95417f2936f390dfc6d`
**PCB blob:** `e1adfbd7a38989b42abaef3557368955484cd560`
**Routed:** no
**Copper changed:** no
**New via:** no
**New segments:** 0
**Stopping rule:** length (pad-edge 61.510 mm > 36 mm). South U1 pad: no. East fence J10/J11: no.

## Preconditions

Live `kicad-cli` DRC: unconnected **58** (required 58), P0.17 opens **1** (required 1). short/clearance/crossing/hole 0/0/0/0. hole_to_hole 1. GND islands 12. Counts matched, so the gap was measured. No copper was added.

## Endpoints

1. **J17.1** net P0.17, center (108.000, 26.000), rectangle 1.7×1.7 mm PTH. Copper on F.Cu, In1.Cu, In2.Cu, B.Cu. This pad is its own island.
2. **In2.Cu track** net P0.17, (45.550, 21.500)–(45.550, 27.400), width 0.18 mm. DRC anchors the open on this track (length 5.900 mm). It is the pass30ay skirt, not a pad. Pads on the same island:

   - J18.5 center (48.160, 62.000), copper on F.Cu, In1.Cu, In2.Cu, B.Cu
   - J13.2 center (66.540, 76.000), copper on F.Cu, In1.Cu, In2.Cu, B.Cu
   - U1.28 center (40.250, 26.750), copper on F.Cu

Neither endpoint is a south U1 pad (U1 south means center y ≥ 37.0; U1.88 and U1.89 are the south pins). U1.28 is on the skirt island at y=26.750, north of that line, and it is not the open end. Neither endpoint is J10 or J11.

## Pad-edge

Pad-edge length of a 0.18 mm join: **61.510 mm** (exact 61.510000 mm) on In2.Cu. `GetClearance` between J17.1 and the In2 track (45.550, 21.500)–(45.550, 27.400). The west face of J17.1 (y 25.150–26.850) is equally far from the east edge of that track, so every nearest pair has this length. Over the 36 mm cap.

## Straight chord (not used)

0.18 mm In2.Cu chord (45.640, 26.000) → (107.150, 26.000), length 61.510 mm. Nearest copper: east edge of the In2 track at y=26.000, and the west edge of J17.1. Crosses the SiP fab body (x 28.0–44.0, y 26.75–37.25): **False**. The chord is east of x=44 and north of y=26.75.

Foreign items closer than 0.15 mm (5):

- VDD_nRF -0.988 mm (In2.Cu zone fill VDD_nRF (local clearance 0.5 mm); worst at x=92.070, centerline signed depth -0.898 mm)
- VDD_GPIO -0.490 mm (via@87.810,26.000 r=0.400 on In2.Cu)
- P0.08 -0.390 mm (via@79.675,26.000 r=0.300 on In2.Cu)
- ENABLE -0.190 mm (via@90.375,26.200 r=0.300 on In2.Cu)
- VDD1 -0.090 mm (via@49.200,25.600 r=0.400 on In2.Cu)

POWER/VIN items closer than 0.20 mm (3):

- VDD_nRF -0.988 mm (In2.Cu zone fill VDD_nRF (local clearance 0.5 mm); worst at x=92.070, centerline signed depth -0.898 mm)
- VDD_GPIO -0.490 mm (via@87.810,26.000 r=0.400 on In2.Cu)
- VDD1 -0.090 mm (via@49.200,25.600 r=0.400 on In2.Cu)

POWER/VIN nets checked: VDD1, VDD2, VDD2_MID, VDD_GPIO, VDD_nRF, VIN, VIN_F, VIN_FILT, VIN_IN. Negative clearance is overlap. The VDD_nRF entry is the In2 pour the chord runs through, not a track. The chord was not used. No route was attempted.

## Why no route

Rule that stopped the pass: **length**. Pad-edge 61.510 mm is over 36 mm. South-pad and east-fence rules were checked and do not apply. No copper added. The pass30ay In2 skirt was not ripped. P0.19 and P0.20 were not started. No other net was touched. No backup (no edit). No Gerbers. No git commit.

## DRC (unchanged board)

| | unconnected | P0.17 | short | clearance | crossing | hole | hole_to_hole | GND islands |
| --- | --- | --- | --- | --- | --- | --- | --- | --- |
| measured | 58 | 1 | 0 | 0 | 0 | 0 | 1 | 12 |

No before/after pair: copper was not edited.

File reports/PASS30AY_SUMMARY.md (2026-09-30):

# PASS30AY_SUMMARY — P0.17

**Timestamp:** 2026-09-30 12:57 IST
**KiCad:** 9.0.2
**Decision:** **KEEP**
**Net:** P0.17
**Git HEAD:** `c801f86437d7f588994839176f6be98a41a85d5b`
**PCB blob at start:** `b17e5794de90387894b0a45376d750cae33bde73`
**Side of package:** east skirt on In2.Cu
**New via:** no
**New segments:** 7 (limit 8)
**Min foreign clearance:** 0.21 mm vs {'net': 'P0.06', 'item': 'via@45.150,36.000'}
**Min POWER/VIN clearance:** 0.3378 mm vs {'net': 'VDD2', 'item': 'via@44.722,25.900'}
**Min hole clearance (pre-add):** 0.31 mm vs via P0.06 @45.150,36.000
**P0.17 opens:** 2 → 1
**Unconnected:** 59 → 58
**GND islands:** 12 → 12 (waived)
**Backup:** `/workspace/kicad-projects/nRF9161-DEV-BOARD/.mcp-backups/pass30ay/pre-edit.kicad_pcb`

## Remeasured gap

Pad-edge **34.860476 mm** (reported 34.86 mm) on F.Cu effective shapes, U1.28 [40.25, 26.75] to J18.5 [48.16, 62.0]. The stated copper points [40.378, 27.147] → [47.913, 61.187] are 34.864 mm apart (J18.5 center is (48.16, 62.0); (47.913, 61.187) is on the pad edge). Other island is J18.5, already on F.Cu and B.Cu. U1 island is the existing stub F.Cu (40.25, 26.75)–(40.25, 23.10) plus through-via (40.25, 23.10). The second via (40.25, 23.95) was not ripped. Stub not ripped.

## Straight line (not used)

0.18 mm F.Cu chord [40.378, 27.147] → [47.913, 61.187] (34.864 mm). Crosses the SiP body. GND via (42.0, 35.0) clearance **-0.276 mm** (via@42.000,35.000, pad radius 0.3 mm). Foreign nets under 0.15 mm: <no-net>, ENABLE, GND, P0.04 (13 items). Not used.

## Layers checked

Existing via (40.25, 23.10) drill 0.3 mm, pad 0.6 mm, F.Cu to B.Cu. On layers: {'F.Cu': True, 'In1.Cu': True, 'In2.Cu': True, 'B.Cu': True}. It is a through via, so the new copper starts on a layer it already hits. No second via.

Free space (0.18 mm centerline, foreign ≥ 0.15, POWER ≥ 0.20, hole ≥ 0.25, off the fab body, x > 24.2, zones ignored because refill pulls them back) from that via:

- F.Cu: {'cells': 250, 'bbox': [37.75, 40.75, 16.0, 26.5], 'ymax': 26.5, 'reaches_j18': False}
- B.Cu: {'cells': 667, 'bbox': [32.75, 46.25, 16.0, 26.5], 'ymax': 26.5, 'reaches_j18': False}
- In1.Cu: {'cells': 30894, 'bbox': [24.5, 72.0, 16.0, 64.0], 'ymax': 64.0, 'reaches_j18': True}
- In2.Cu: {'cells': 31299, 'bbox': [24.5, 72.0, 16.0, 64.0], 'ymax': 64.0, 'reaches_j18': True}

F.Cu and B.Cu both die at ymax 26.5, short of the header, same as the P0.16 via. One extra via cannot join a pocket that ends near y≈27 to J18.5. In1.Cu flood-fill does reach J18.5, but the locked pass30ax skirt (40.70, 20.80)→(45.55, 20.80)→(45.55, 27.40)→(44.60, 27.40)→(44.60, 60.40)→(45.62, 60.40)→(45.62, 61.10) owns that east corridor. Same-layer 0.18 mm centerlines need ≥ 0.33 mm. The P0.06 via (45.150, 36.000) closes the strip beside x=44.60, so this attempt does not run on In1. In2.Cu has no tracks in the corridor and the through-via already hits it. In2 is the VDD_nRF plane (zone local clearance 0.5 mm). The sealed B.Cu pocket y≈44.60, x≈81.8–97.3 was not used. x > 24.2. No west skirt.

## Route

In2.Cu 0.18 mm, east of the body (long run x=44.60). No new via. Corners:

- (40.25, 23.10) → (40.25, 21.50)
- (40.25, 21.50) → (45.55, 21.50)
- (45.55, 21.50) → (45.55, 27.40)
- (45.55, 27.40) → (44.60, 27.40)
- (44.60, 27.40) → (44.60, 60.40)
- (44.60, 60.40) → (48.16, 60.40)
- (48.16, 60.40) → (48.16, 61.30)

North of the fab body at y=21.50, drop at x=45.55 (clears VDD2 via (44.722, 25.900)), then x=44.60 from y=27.40 to y=60.40 (clears P0.06 via (45.150, 36.000) by 0.21 mm; copper edge x=44.51, fab body ends at x=44.0). End cap (48.16, 60.40)–(48.16, 61.30) overlaps J18.5. P0.16's matching XY on In1.Cu is a different layer, so the 0.33 mm same-layer rule does not apply. That In1 copper was not ripped.

## Gate

KEEP. East In2 skirt, 7 new segments, no new via. P0.17 opens 2→1. Unconnected 59→58. Foreign 0.21 mm vs {'net': 'P0.06', 'item': 'via@45.150,36.000'}. POWER 0.3378 mm vs {'net': 'VDD2', 'item': 'via@44.722,25.900'}. short/clearance/crossing/hole 0/0/0/0. hole_to_hole 1. GND islands 12→12 (waived). Other non-GND gained: none. Locked copper not ripped.

## DRC

| | unconnected | P0.17 | short | clearance | crossing | hole | hole_to_hole | GND islands |
| --- | --- | --- | --- | --- | --- | --- | --- | --- |
| before | 59 | 2 | 0 | 0 | 0 | 0 | 1 | 12 |
| after | 58 | 1 | 0 | 0 | 0 | 0 | 1 | 12 |

No other non-GND net gained an open.
Locked copper not ripped. No Gerbers. No git commit.

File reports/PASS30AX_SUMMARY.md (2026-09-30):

# PASS30AX_SUMMARY — P0.16

**Timestamp:** 2026-09-30 12:43 IST
**KiCad:** 9.0.2
**Decision:** **KEEP**
**Net:** P0.16
**Side of package:** east skirt on In1.Cu
**New via:** no
**New segments:** 6 (limit 8)
**Min foreign clearance:** 0.21 mm vs {'net': 'P0.06', 'item': 'via@45.150,36.000'}
**Min POWER/VIN clearance:** 0.3378 mm vs {'net': 'VDD2', 'item': 'via@44.722,25.900'}
**Min hole clearance (pre-add):** 0.31 mm vs via P0.06 @45.150,36.000
**P0.16 opens:** 1 → 0
**Unconnected:** 60 → 59
**GND islands:** 12 → 12 (waived)

## Remeasured gap

Pad-edge **34.259 mm** on F.Cu, U1.26 [41.25, 26.75] to J18.4 [45.62, 62.0]. Other island is J18.4 already tied on B.Cu to J13.1. The U1 island is the existing stub F.Cu (41.25, 26.75)–(40.70, 20.80) plus via (40.70, 20.80). Stub not ripped.

## Straight line (not used)

0.18 mm F.Cu chord [41.364, 27.15] → [45.537, 61.154] (34.259 mm). Crosses the SiP body. Worst hit GND -0.349 mm (via@42.000,32.000). Foreign nets under 0.15 mm: <no-net>, ENABLE, GND, P0.04, P0.15 (19 items).

## Why not F.Cu or B.Cu

Free space (0.18 mm centerline, foreign ≥ 0.15, POWER ≥ 0.20, hole ≥ 0.25, off the fab body, x > 24.2, GND pour ignored) from the existing via:

- F.Cu: {'cells': 545, 'bbox': [37.75, 47.0, 16.0, 27.0], 'reaches_j18': False}
- B.Cu: {'cells': 652, 'bbox': [32.75, 46.25, 16.0, 26.5], 'reaches_j18': False}

Neither component reaches J18.4. The start pocket ends near y≈27 and the J18 component starts south of the fanout (y≈41). One via is a point, so it cannot join two components that do not overlap. The sealed B.Cu pocket y≈44.60, x≈81.8–97.3 was not used. No west skirt.

## Route

In1.Cu 0.18 mm, east of the body (long run x=44.60 > 44). No new via. Corners:

- (40.70, 20.80) → (45.55, 20.80)
- (45.55, 20.80) → (45.55, 27.40)
- (45.55, 27.40) → (44.60, 27.40)
- (44.60, 27.40) → (44.60, 60.40)
- (44.60, 60.40) → (45.62, 60.40)
- (45.62, 60.40) → (45.62, 61.10)

The north run is y=20.80, above the fab body. The drop at x=45.55 clears VDD2 via (44.722, 25.900). The south run at x=44.60 clears P0.06 via (45.150, 36.000) by 0.21 mm and stays east of the body (copper edge x=44.51). End cap overlaps J18.4.

## Gate

KEEP. East In1 skirt, 6 new segments, no new via. P0.16 opens 1→0. Unconnected 60→59. Foreign 0.21 mm, POWER 0.3378 mm. short/clearance/crossing/hole 0. hole_to_hole 1. GND islands 12→12 (waived). Other non-GND gained: none.

## DRC

| | unconnected | P0.16 | short | clearance | crossing | hole | hole_to_hole | GND islands |
| --- | --- | --- | --- | --- | --- | --- | --- | --- |
| before | 60 | 1 | 0 | 0 | 0 | 0 | 1 | 12 |
| after | 59 | 0 | 0 | 0 | 0 | 0 | 1 | 12 |

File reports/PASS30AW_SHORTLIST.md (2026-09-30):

# PASS30AW shortlist — U1 pads on non-GND opens

**Timestamp:** 2026-09-30 12:27 IST
**Decision:** **NO-COPPER** (measure only)
**KiCad:** 9.0.2, pcbnew, no save, no refill, no DRC file

Every non-GND net that has a U1 pad on one copper island and at least one other island. GND zone islands are ignored. Connector-to-connector opens with no U1 pad are not ranked. Pad-edge is the copper-edge distance from that U1 pad to the nearest copper on the nearest other island.

## Body

U1 `nRF9161_LGA_16.0x10.5mm`. F.Fab rect is exactly **x 28.0–44.0, y 26.75–37.25**. F.Courtyard is **x 27.75–44.25, y 26.5–37.5** (0.25 mm outside the fab). Pad centers span the fab rect. Exit tests use the fab body, not the courtyard. A pad lip outside the fab rect is not a stub. A stub is an existing track or via of that same island outside the fab rect and not only inside the RF keepout (x≤24.2 and y in 20–64).

Legal exit for a 0.18 mm track at 0.15 mm foreign clearance (need a 0.48 mm copper gap), any one of:

- sideways gap to a neighboring U1 pad ≥ 0.48 mm, or
- via-row gap ≥ 0.48 mm between the flanking fanout vias/tracks within 4.4 mm of the body (F.Cu tracks and vias; a missing flank is an open side if a 0.18 mm track still on the pad clears the remaining flank by ≥ 0.15 mm), or
- a stub of this island already outside the fab body and not only inside the keepout.

Every one of these 37 pads has sideways gaps of **0.200 mm** (0.50 mm pitch, 0.30 mm pad). None exit sideways. West exits that stop in the strip 24.2 < x < 28 are not trapped-by-keepout.

## Census — 37 U1-open pads

| mm | net | U1 pad | center | edge | class | by | nearest other copper |
| --- | --- | --- | --- | --- | --- | --- | --- |
| 34.038 | `P0.14` | U1.24 | (42.250, 26.750) | N | trapped | trapped | pad J18.2 F.Cu+B.Cu (40.623, 61.154) |
| 34.259 | `P0.16` | U1.26 | (41.250, 26.750) | N | exit | stub | pad J18.4 F.Cu+B.Cu (45.537, 61.154) |
| 34.863 | `P0.17` | U1.28 | (40.250, 26.750) | N | exit | stub | pad J18.5 F.Cu+B.Cu (47.913, 61.187) |
| 35.644 | `P0.18` | U1.29 | (39.750, 26.750) | N | trapped | trapped | pad J18.6 F.Cu+B.Cu (50.453, 61.187) |
| 36.661 | `P0.19` | U1.30 | (39.250, 26.750) | N | exit | stub | pad J18.7 F.Cu+B.Cu (52.993, 61.187) |
| 38.595 | `P0.20` | U1.35 | (36.750, 26.750) | N | exit | stub | F.Cu (55.78,62.00)-(55.78,60.90) F.Cu (55.736, 60.821) |
| 40.760 | `P0.01` | U1.96 | (40.250, 37.250) | S | trapped | trapped | B.Cu (27.20,78.50)-(62.00,78.50) B.Cu (40.364, 78.410) |
| 40.990 | `SIM_CLK` | U1.46 | (31.250, 26.750) | N | exit | stub | B.Cu (70.90,45.50)-(68.14,45.50) B.Cu (68.060, 45.460) |
| 42.124 | `SIM_RST` | U1.43 | (32.750, 26.750) | N | exit | via-row | B.Cu (71.68,43.80)-(71.68,48.00) B.Cu (71.597, 43.764) |
| 43.298 | `P0.00` | U1.95 | (39.750, 37.250) | S | exit | stub | F.Cu (79.49,18.00)-(79.49,19.13) F.Cu (79.408, 19.163) |
| 44.118 | `P0.07` | U1.4 | (44.000, 35.500) | E | exit | stub | pad J12.8 F.Cu+B.Cu (24.181, 75.250) |
| 45.733 | `P0.05` | U1.2 | (44.000, 36.500) | E | exit | stub | pad J12.6 F.Cu+B.Cu (19.101, 75.250) |
| 46.031 | `SIM_1V8` | U1.49 | (29.750, 26.750) | N | exit | via-row | F.Cu (72.90,44.10)-(72.90,48.60) F.Cu (72.714, 44.027) |
| 47.797 | `P0.09` | U1.16 | (44.000, 29.500) | E | exit | via-row | pad J12.10 F.Cu+B.Cu (29.107, 75.187) |
| 47.976 | `P0.11` | U1.19 | (44.000, 28.000) | E | exit | stub | pad J12.12 F.Cu+B.Cu (34.187, 75.187) |
| 48.028 | `P0.12` | U1.20 | (44.000, 27.500) | E | exit | stub | pad J12.13 F.Cu+B.Cu (36.563, 75.154) |
| 48.055 | `P0.10` | U1.18 | (44.000, 28.500) | E | exit | stub | pad J12.11 F.Cu+B.Cu (31.647, 75.187) |
| 51.402 | `SIM_IO` | U1.48 | (30.250, 26.750) | N | exit | stub | pad C37.1 F.Cu (75.458, 51.862) |
| 58.267 | `P0.03` | U1.99 | (41.750, 37.250) | S | exit | stub | F.Cu (97.49,18.00)-(97.49,19.13) F.Cu (97.404, 19.153) |
| 62.076 | `P0.22` | U1.38 | (35.250, 26.750) | N | exit | stub | via@79.24,71.5 F.Cu+B.Cu (79.029, 71.287) |
| 62.812 | `P0.21` | U1.37 | (35.750, 26.750) | N | exit | stub | pad J13.6 F.Cu+B.Cu (76.161, 75.343) |
| 65.303 | `P0.30` | U1.88 | (36.250, 37.250) | S | exit | stub | F.Cu (101.20,46.40)-(112.40,46.40) F.Cu (101.111, 46.388) |
| 66.628 | `P0.26` | U1.83 | (33.750, 37.250) | S | exit | stub | pad J13.11 F.Cu+B.Cu (88.743, 75.461) |
| 66.737 | `P0.31` | U1.89 | (36.750, 37.250) | S | exit | via-row | F.Cu (103.05,47.10)-(106.70,47.10) F.Cu (102.961, 47.087) |
| 66.873 | `P0.23` | U1.39 | (34.750, 26.750) | N | exit | stub | pad J13.8 F.Cu+B.Cu (81.241, 75.343) |
| 68.318 | `P0.27` | U1.84 | (34.250, 37.250) | S | exit | via-row | pad J13.12 F.Cu+B.Cu (91.202, 75.583) |
| 69.013 | `P0.24` | U1.40 | (34.250, 26.750) | N | exit | via-row | pad J13.9 F.Cu+B.Cu (83.663, 75.461) |
| 69.603 | `P0.28` | U1.86 | (35.250, 37.250) | S | exit | stub | pad J13.13 F.Cu+B.Cu (93.730, 75.599) |
| 69.936 | `COEX1` | U1.92 | (38.250, 37.250) | S | trapped | trapped | pad J15.2 F.Cu+B.Cu (103.538, 63.079) |
| 71.321 | `P0.29` | U1.87 | (35.750, 37.250) | S | trapped | trapped | pad J13.14 F.Cu+B.Cu (96.270, 75.599) |
| 71.584 | `P0.25` | U1.42 | (33.250, 26.750) | N | exit | stub | pad J13.10 F.Cu+B.Cu (86.203, 75.461) |
| 77.438 | `MAGPIO0` | U1.55 | (28.000, 28.500) | W | exit | via-row | pad J14.1 F.Cu+B.Cu (103.500, 47.500) |
| 78.007 | `MAGPIO1` | U1.54 | (28.000, 28.000) | W | exit | stub | pad J14.2 F.Cu+B.Cu (103.538, 49.079) |
| 78.293 | `MIPI_VIO` | U1.57 | (28.000, 29.500) | W | exit | stub | pad J14.4 F.Cu+B.Cu (103.538, 51.619) |
| 78.501 | `MAGPIO2` | U1.53 | (28.000, 27.500) | W | exit | stub | pad J14.3 F.Cu+B.Cu (103.538, 50.349) |
| 78.512 | `MIPI_SCLK` | U1.58 | (28.000, 30.000) | W | exit | stub | pad J14.5 F.Cu+B.Cu (103.538, 52.889) |
| 78.739 | `MIPI_SDATA` | U1.59 | (28.000, 30.500) | W | trapped | trapped | pad J14.6 F.Cu+B.Cu (103.538, 54.159) |

## Ranked exits — 31

Shortest pad-edge first. All of them, not a top five. The straight 0.18 mm chord is F.Cu between the two copper points. Clearance is to foreign copper (negative means the chord overlaps it). The chord is not a proposed route.

### 1. `P0.16` — 34.259 mm — stub

- **A:** U1.26 on F.Cu, copper (41.364, 27.150), center (41.250, 26.750)
- **B:** pad J18.4 on F.Cu+B.Cu at (45.537, 61.154)
- **Pad-edge:** 34.259 mm
- **Exit:** F.Cu (41.25, 26.75)–(40.70, 20.80) and via (40.70, 20.80) r=0.30 already north of the fab body.
- **Straight 0.18 mm F.Cu hits:** GND -0.349 mm (via@42.0,32.0). 5 foreign nets under 0.15 mm.

### 2. `P0.17` — 34.863 mm — stub

- **A:** U1.28 on F.Cu, copper (40.378, 27.147), center (40.250, 26.750)
- **B:** pad J18.5 on F.Cu+B.Cu at (47.913, 61.187)
- **Pad-edge:** 34.863 mm
- **Exit:** F.Cu to via (40.25, 23.10) r=0.30 already north of the fab body.
- **Straight 0.18 mm F.Cu hits:** GND -0.277 mm (via@42.0,35.0). 4 foreign nets under 0.15 mm.

### 3. `P0.19` — 36.661 mm — stub

- **A:** U1.30 on F.Cu, copper (39.378, 27.147), center (39.250, 26.750)
- **B:** pad J18.7 on F.Cu+B.Cu at (52.993, 61.187)
- **Pad-edge:** 36.661 mm
- **Exit:** F.Cu to via (39.25, 23.10) r=0.30 already north of the fab body.
- **Straight 0.18 mm F.Cu hits:** VDD1 -0.29 mm (F.Cu (50.52,38.00)-(43.25,38.00)). 5 foreign nets under 0.15 mm.

### 4. `P0.20` — 38.595 mm — stub

- **A:** U1.35 on F.Cu, copper (36.878, 27.147), center (36.750, 26.750)
- **B:** F.Cu (55.78,62.00)-(55.78,60.90) on F.Cu at (55.736, 60.821)
- **Pad-edge:** 38.595 mm
- **Exit:** F.Cu (36.75, 26.75)–(36.20, 20.80) and via (36.20, 20.80) r=0.30 already north of the fab body.
- **Straight 0.18 mm F.Cu hits:** P0.06 -0.373 mm (via@44.0,39.9). 8 foreign nets under 0.15 mm.

### 5. `SIM_CLK` — 40.990 mm — stub

- **A:** U1.46 on F.Cu, copper (31.397, 27.128), center (31.250, 26.750)
- **B:** B.Cu (70.90,45.50)-(68.14,45.50) on B.Cu at (68.060, 45.460)
- **Pad-edge:** 40.990 mm
- **Exit:** F.Cu to via (31.25, 23.10) r=0.30 already north of the fab body.
- **Straight 0.18 mm F.Cu hits:** VDD2 -0.419 mm (via@61.3,42.0). 9 foreign nets under 0.15 mm.

### 6. `SIM_RST` — 42.124 mm — via-row

- **A:** U1.43 on F.Cu, copper (32.897, 27.128), center (32.750, 26.750)
- **B:** B.Cu (71.68,43.80)-(71.68,48.00) on B.Cu at (71.597, 43.764)
- **Pad-edge:** 42.124 mm
- **Exit:** West side of the via row is open (no F.Cu flank within 4.4 mm). The only flank is P0.25 via (33.25, 23.10) r=0.30. A 0.18 mm track centered at x=32.71, still on the pad, clears that via by 0.15 mm. Sideways pad gaps are 0.200 mm, so the exit is the open via row, not the pad gap.
- **Straight 0.18 mm F.Cu hits:** VDD1 -0.29 mm (F.Cu (50.68,35.00)-(50.68,31.00)). 7 foreign nets under 0.15 mm.

### 7. `P0.00` — 43.298 mm — stub

- **A:** U1.95 on F.Cu, copper (39.897, 36.872), center (39.750, 37.250)
- **B:** F.Cu (79.49,18.00)-(79.49,19.13) on F.Cu at (79.408, 19.163)
- **Pad-edge:** 43.298 mm
- **Exit:** F.Cu to via (39.75, 41.10) r=0.30 already south of the fab body.
- **Straight 0.18 mm F.Cu hits:** VDD1 -0.29 mm (F.Cu (50.68,35.00)-(50.68,31.00)). 9 foreign nets under 0.15 mm.

### 8. `P0.07` — 44.118 mm — stub

- **A:** U1.4 on F.Cu, copper (43.622, 35.647), center (44.000, 35.500)
- **B:** pad J12.8 on F.Cu+B.Cu at (24.181, 75.250)
- **Pad-edge:** 44.118 mm
- **Exit:** F.Cu to via (47.40, 36.50) r=0.30 already east of the fab body.
- **Straight 0.18 mm F.Cu hits:** P0.02 -0.215 mm (via@40.75,41.1). 6 foreign nets under 0.15 mm.

### 9. `P0.05` — 45.733 mm — stub

- **A:** U1.2 on F.Cu, copper (43.622, 36.647), center (44.000, 36.500)
- **B:** pad J12.6 on F.Cu+B.Cu at (19.101, 75.250)
- **Pad-edge:** 45.733 mm
- **Exit:** F.Cu to via (47.40, 36.50) r=0.30 already east of the fab body.
- **Straight 0.18 mm F.Cu hits:** P0.02 -0.353 mm (via@40.75,41.1). 7 foreign nets under 0.15 mm.

### 10. `SIM_1V8` — 46.031 mm — via-row

- **A:** U1.49 on F.Cu, copper (29.897, 27.128), center (29.750, 26.750)
- **B:** F.Cu (72.90,44.10)-(72.90,48.60) on F.Cu at (72.714, 44.027)
- **Pad-edge:** 46.031 mm
- **Exit:** West side of the y=23.10 via row is open. The only flank is SIM_IO via (30.25, 23.10) r=0.30. A 0.18 mm track centered at x=29.71 clears it by 0.15 mm. COEX0 via (29.81, 22.00) is 4.75 mm north of the body, past this row.
- **Straight 0.18 mm F.Cu hits:** GND -0.301 mm (via@42.0,32.0). 9 foreign nets under 0.15 mm.

### 11. `P0.09` — 47.797 mm — via-row

- **A:** U1.16 on F.Cu, copper (43.622, 29.647), center (44.000, 29.500)
- **B:** pad J12.10 on F.Cu+B.Cu at (29.107, 75.187)
- **Pad-edge:** 47.797 mm
- **Exit:** F.Cu via-row gap 0.900 mm between P0.10 via (47.00, 28.50) r=0.30 (inner edge y=28.80) and P0.08 via (46.20, 30.00) r=0.30 (inner edge y=29.70). A 0.18 mm track centered at y=29.45 clears both by at least 0.15 mm. VDD_GPIO at x=47.55 is beyond this row.
- **Straight 0.18 mm F.Cu hits:** GND -0.31 mm (via@42.0,35.0). 8 foreign nets under 0.15 mm.

### 12. `P0.11` — 47.976 mm — stub

- **A:** U1.19 on F.Cu, copper (43.622, 28.147), center (44.000, 28.000)
- **B:** pad J12.12 on F.Cu+B.Cu at (34.187, 75.187)
- **Pad-edge:** 47.976 mm
- **Exit:** F.Cu (44.00, 28.00)–(46.50, 28.00) and via (48.62, 28.00) r=0.30 already east of the fab body.
- **Straight 0.18 mm F.Cu hits:** P0.06 -0.251 mm (via@40.2,44.5). 9 foreign nets under 0.15 mm.

### 13. `P0.12` — 48.028 mm — stub

- **A:** U1.20 on F.Cu, copper (43.636, 27.650), center (44.000, 27.500)
- **B:** pad J12.13 on F.Cu+B.Cu at (36.563, 75.154)
- **Pad-edge:** 48.028 mm
- **Exit:** F.Cu to via (47.00, 27.50) r=0.30 already east of the fab body.
- **Straight 0.18 mm F.Cu hits:** P0.03 -0.275 mm (via@41.75,41.1). 8 foreign nets under 0.15 mm.

### 14. `P0.10` — 48.055 mm — stub

- **A:** U1.18 on F.Cu, copper (43.622, 28.647), center (44.000, 28.500)
- **B:** pad J12.11 on F.Cu+B.Cu at (31.647, 75.187)
- **Pad-edge:** 48.055 mm
- **Exit:** F.Cu to via (47.00, 28.50) r=0.30 already east of the fab body.
- **Straight 0.18 mm F.Cu hits:** GND -0.378 mm (via@42.0,35.0). 7 foreign nets under 0.15 mm.

### 15. `SIM_IO` — 51.402 mm — stub

- **A:** U1.48 on F.Cu, copper (30.397, 27.128), center (30.250, 26.750)
- **B:** pad C37.1 on F.Cu at (75.458, 51.862)
- **Pad-edge:** 51.402 mm
- **Exit:** F.Cu to via (30.25, 23.10) r=0.30 already north of the fab body.
- **Straight 0.18 mm F.Cu hits:** P0.05 -0.356 mm (via@47.4,36.5). 12 foreign nets under 0.15 mm.

### 16. `P0.03` — 58.267 mm — stub

- **A:** U1.99 on F.Cu, copper (41.897, 36.872), center (41.750, 37.250)
- **B:** F.Cu (97.49,18.00)-(97.49,19.13) on F.Cu at (97.404, 19.153)
- **Pad-edge:** 58.267 mm
- **Exit:** F.Cu (41.75, 37.25)–(41.75, 41.10) already south of the fab body.
- **Straight 0.18 mm F.Cu hits:** VDD1 -0.29 mm (F.Cu (50.68,35.00)-(50.68,31.00)). 10 foreign nets under 0.15 mm.

### 17. `P0.22` — 62.076 mm — stub

- **A:** U1.38 on F.Cu, copper (35.389, 27.140), center (35.250, 26.750)
- **B:** via@79.24,71.5 on F.Cu+B.Cu at (79.029, 71.287)
- **Pad-edge:** 62.076 mm
- **Exit:** F.Cu (35.25, 26.75)–(35.25, 22.00) already north of the fab body.
- **Straight 0.18 mm F.Cu hits:** P0.06 -0.324 mm (via@48.8,40.8). 10 foreign nets under 0.15 mm.

### 18. `P0.21` — 62.812 mm — stub

- **A:** U1.37 on F.Cu, copper (35.889, 27.140), center (35.750, 26.750)
- **B:** pad J13.6 on F.Cu+B.Cu at (76.161, 75.343)
- **Pad-edge:** 62.812 mm
- **Exit:** F.Cu to via (35.75, 23.10) r=0.30 already north of the fab body.
- **Straight 0.18 mm F.Cu hits:** VDD1 -0.29 mm (F.Cu (50.52,38.00)-(43.25,38.00)). 10 foreign nets under 0.15 mm.

### 19. `P0.30` — 65.303 mm — stub

- **A:** U1.88 on F.Cu, copper (36.400, 37.614), center (36.250, 37.250)
- **B:** F.Cu (101.20,46.40)-(112.40,46.40) on F.Cu at (101.111, 46.388)
- **Pad-edge:** 65.303 mm
- **Exit:** F.Cu to via (36.25, 41.10) r=0.30 already south of the fab body. Classified only; not a route to retry.
- **Straight 0.18 mm F.Cu hits:** SIM_VCC -0.377 mm (via@94.76,45.54). 18 foreign nets under 0.15 mm.

### 20. `P0.26` — 66.628 mm — stub

- **A:** U1.83 on F.Cu, copper (33.889, 37.639), center (33.750, 37.250)
- **B:** pad J13.11 on F.Cu+B.Cu at (88.743, 75.461)
- **Pad-edge:** 66.628 mm
- **Exit:** F.Cu to via (33.75, 41.10) r=0.30 already south of the fab body.
- **Straight 0.18 mm F.Cu hits:** COEX0 -0.3 mm (via@38.75,41.1). 12 foreign nets under 0.15 mm.

### 21. `P0.31` — 66.737 mm — via-row

- **A:** U1.89 on F.Cu, copper (36.900, 37.614), center (36.750, 37.250)
- **B:** F.Cu (103.05,47.10)-(106.70,47.10) on F.Cu at (102.961, 47.087)
- **Pad-edge:** 66.737 mm
- **Exit:** F.Cu via-row gap 0.900 mm between P0.30 via (36.25, 41.10) r=0.30 (edge x=36.55) and COEX2 via (37.75, 41.10) r=0.30 (edge x=37.45). A 0.18 mm track centered at x=36.80 clears both by at least 0.15 mm. Right neighbor U1.90 is GND and has no local via, so this is not the 0.40 mm adjacent-via pinch. Classified only; not a route to retry.
- **Straight 0.18 mm F.Cu hits:** SIM_CLK -0.301 mm (via@70.9,42.4). 18 foreign nets under 0.15 mm.

### 22. `P0.23` — 66.873 mm — stub

- **A:** U1.39 on F.Cu, copper (34.889, 27.140), center (34.750, 26.750)
- **B:** pad J13.8 on F.Cu+B.Cu at (81.241, 75.343)
- **Pad-edge:** 66.873 mm
- **Exit:** F.Cu to via (34.75, 23.10) r=0.30 already north of the fab body.
- **Straight 0.18 mm F.Cu hits:** VDD1 -0.29 mm (F.Cu (50.52,38.00)-(43.25,38.00)). 8 foreign nets under 0.15 mm.

### 23. `P0.27` — 68.318 mm — via-row

- **A:** U1.84 on F.Cu, copper (34.389, 37.639), center (34.250, 37.250)
- **B:** pad J13.12 on F.Cu+B.Cu at (91.202, 75.583)
- **Pad-edge:** 68.318 mm
- **Exit:** F.Cu via-row gap 0.900 mm between P0.26 via (33.75, 41.10) r=0.30 and P0.28 via (35.25, 41.10) r=0.30. A 0.18 mm track centered at x=34.30 clears both by at least 0.15 mm. Right neighbor U1.85 is GND and has no local via.
- **Straight 0.18 mm F.Cu hits:** P0.00 -0.291 mm (via@39.75,41.1). 12 foreign nets under 0.15 mm.

### 24. `P0.24` — 69.013 mm — via-row

- **A:** U1.40 on F.Cu, copper (34.389, 27.140), center (34.250, 26.750)
- **B:** pad J13.9 on F.Cu+B.Cu at (83.663, 75.461)
- **Pad-edge:** 69.013 mm
- **Exit:** F.Cu via-row gap 0.900 mm between P0.25 via (33.25, 23.10) r=0.30 and P0.23 via (34.75, 23.10) r=0.30. A 0.18 mm track centered at x=34.21 clears the P0.23 via by 0.15 mm. Left neighbor U1.41 is GND and has no local via. SWDCLK at x=34.20 is B.Cu only.
- **Straight 0.18 mm F.Cu hits:** VDD1 -0.29 mm (F.Cu (50.52,38.00)-(43.25,38.00)). 9 foreign nets under 0.15 mm.

### 25. `P0.28` — 69.603 mm — stub

- **A:** U1.86 on F.Cu, copper (35.397, 37.628), center (35.250, 37.250)
- **B:** pad J13.13 on F.Cu+B.Cu at (93.730, 75.599)
- **Pad-edge:** 69.603 mm
- **Exit:** F.Cu to via (35.25, 41.10) r=0.30 already south of the fab body.
- **Straight 0.18 mm F.Cu hits:** P0.02 -0.38 mm (via@40.75,41.1). 10 foreign nets under 0.15 mm.

### 26. `P0.25` — 71.584 mm — stub

- **A:** U1.42 on F.Cu, copper (33.389, 27.140), center (33.250, 26.750)
- **B:** pad J13.10 on F.Cu+B.Cu at (86.203, 75.461)
- **Pad-edge:** 71.584 mm
- **Exit:** F.Cu to via (33.25, 23.10) r=0.30 already north of the fab body.
- **Straight 0.18 mm F.Cu hits:** GND -0.377 mm (via@42.0,35.0). 9 foreign nets under 0.15 mm.

### 27. `MAGPIO0` — 77.438 mm — via-row

- **A:** U1.55 on F.Cu, copper (28.397, 28.628), center (28.000, 28.500)
- **B:** pad J14.1 on F.Cu+B.Cu at (103.500, 47.500)
- **Pad-edge:** 77.438 mm
- **Exit:** F.Cu gap 1.320 mm between MAGPIO1 track y=28.00 w=0.18 (edge y=28.09) and MIPI_VIO track y=29.50 w=0.18 (edge y=29.41). Outward is west, into the strip 24.2 < x < 28, which is outside the RF keepout. Not trapped-by-keepout.
- **Straight 0.18 mm F.Cu hits:** GND -0.36 mm (via@30.0,29.0). 15 foreign nets under 0.15 mm.

### 28. `MAGPIO1` — 78.007 mm — stub

- **A:** U1.54 on F.Cu, copper (28.397, 28.128), center (28.000, 28.000)
- **B:** pad J14.2 on F.Cu+B.Cu at (103.538, 49.079)
- **Pad-edge:** 78.007 mm
- **Exit:** F.Cu to via (25.60, 23.10) r=0.30. Via copper stays at x≥25.30, outside the keepout x≤24.2.
- **Straight 0.18 mm F.Cu hits:** COEX0 -0.365 mm (via@37.0,30.5). 14 foreign nets under 0.15 mm.

### 29. `MIPI_VIO` — 78.293 mm — stub

- **A:** U1.57 on F.Cu, copper (28.397, 29.628), center (28.000, 29.500)
- **B:** pad J14.4 on F.Cu+B.Cu at (103.538, 51.619)
- **Pad-edge:** 78.293 mm
- **Exit:** F.Cu to via (24.65, 24.40) r=0.30. Via copper west edge is x=24.35, still outside the keepout x≤24.2.
- **Straight 0.18 mm F.Cu hits:** VDD1 -0.29 mm (F.Cu (50.52,37.95)-(50.52,35.00)). 18 foreign nets under 0.15 mm.

### 30. `MAGPIO2` — 78.501 mm — stub

- **A:** U1.53 on F.Cu, copper (28.397, 27.628), center (28.000, 27.500)
- **B:** pad J14.3 on F.Cu+B.Cu at (103.538, 50.349)
- **Pad-edge:** 78.501 mm
- **Exit:** F.Cu to via (26.75, 23.10) r=0.30, outside the keepout.
- **Straight 0.18 mm F.Cu hits:** VDD2 -0.459 mm (via@59.7,37.126). 15 foreign nets under 0.15 mm.

### 31. `MIPI_SCLK` — 78.512 mm — stub

- **A:** U1.58 on F.Cu, copper (28.397, 30.128), center (28.000, 30.000)
- **B:** pad J14.5 on F.Cu+B.Cu at (103.538, 52.889)
- **Pad-edge:** 78.512 mm
- **Exit:** F.Cu to via (26.874, 30.65) r=0.30, outside the keepout.
- **Straight 0.18 mm F.Cu hits:** VDD1 -0.29 mm (F.Cu (50.52,37.95)-(50.52,35.00)). 16 foreign nets under 0.15 mm.

## Trapped — 6

Included: U1.24. None are trapped-by-keepout. Blocking gaps are sideways and via-row. Need 0.48 mm.

### `P0.14` U1.24 F.Cu (42.250, 26.750) (N)

- **Sideways:** 0.200 mm
- **Via-row:** 0.400 mm
- **Why:** Sideways 0.200 mm to U1.25 (P0.15) and to U1.23 (P0.13). North via-row 0.400 mm between P0.15 via (41.75, 23.10) r=0.30 and P0.13 via (42.75, 23.10 and 23.95) r=0.30. Need 0.48 mm. No stub. Same pinch measured in pass30au; the reverted via (42.25, 25.50) was not placed again.
- **Other island (not ranked):** pad J18.2 F.Cu+B.Cu (40.623, 61.154), pad-edge 34.038 mm

### `P0.18` U1.29 F.Cu (39.750, 26.750) (N)

- **Sideways:** 0.200 mm
- **Via-row:** 0.400 mm
- **Why:** Sideways 0.200 mm to U1.30 (P0.19) and to U1.28 (P0.17). Via-row 0.400 mm between P0.19 via (39.25, 23.10) r=0.30 and P0.17 via (40.25, 23.10) r=0.30. No stub.
- **Other island (not ranked):** pad J18.6 F.Cu+B.Cu (50.453, 61.187), pad-edge 35.644 mm

### `P0.01` U1.96 F.Cu (40.250, 37.250) (S)

- **Sideways:** 0.200 mm
- **Via-row:** 0.400 mm
- **Why:** Sideways 0.200 mm to U1.95 (P0.00) and to U1.97 (P0.02). South via-row 0.400 mm between P0.00 via (39.75, 41.10) r=0.30 and P0.02 via (40.75, 41.10) r=0.30. No stub.
- **Other island (not ranked):** B.Cu (27.20,78.50)-(62.00,78.50) B.Cu (40.364, 78.410), pad-edge 40.760 mm

### `COEX1` U1.92 F.Cu (38.250, 37.250) (S)

- **Sideways:** 0.200 mm
- **Via-row:** 0.400 mm
- **Why:** Sideways 0.200 mm to U1.91 (COEX2) and to U1.93 (COEX0). South via-row 0.400 mm between COEX2 via (37.75, 41.10) r=0.30 and COEX0 via (38.75, 41.10) r=0.30. No stub.
- **Other island (not ranked):** pad J15.2 F.Cu+B.Cu (103.538, 63.079), pad-edge 69.936 mm

### `P0.29` U1.87 F.Cu (35.750, 37.250) (S)

- **Sideways:** 0.200 mm
- **Via-row:** 0.400 mm
- **Why:** Sideways 0.200 mm to U1.86 (P0.28) and to U1.88 (P0.30). South via-row 0.400 mm between vias (35.25, 41.10) and (36.25, 41.10), both r=0.30. No stub.
- **Other island (not ranked):** pad J13.14 F.Cu+B.Cu (96.270, 75.599), pad-edge 71.321 mm

### `MIPI_SDATA` U1.59 F.Cu (28.000, 30.500) (W)

- **Sideways:** 0.200 mm
- **Via-row:** 0.000 mm
- **Why:** Sideways 0.200 mm to U1.58 (MIPI_SCLK) and to U1.60 (GND). MIPI_SCLK via (26.874, 30.650) r=0.30 covers y 30.35–30.95 and straddles the pad axis y=30.50, so the via-row gap on the axis is 0. The pad's track-center window (±0.06 mm) cannot clear that via by 0.15 mm. The via is at x=26.87, outside the RF keepout, so this is a via block, not trapped-by-keepout. No stub.
- **Other island (not ranked):** pad J14.6 F.Cu+B.Cu (103.538, 54.159), pad-edge 78.739 mm

## Not done

No track, via, zone, or footprint move. No refill. The reverted P0.14 via at (42.25, 25.50) was not placed. P0.13 and P0.15 vias were not moved. U1.88 and U1.89 were classified and not routed. The y=44.60 pocket was not used. No header or U1 move. No Gerbers. No git commit. No one was pinged.

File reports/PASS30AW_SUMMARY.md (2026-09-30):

# PASS30AW_SUMMARY — U1 open census

**Timestamp:** 2026-09-30 12:27 IST
**KiCad:** 9.0.2
**Decision:** **NO-COPPER**

| | count |
| --- | --- |
| U1 pads on a non-GND open | **37** |
| Can exit the fab body | **31** |
| Trapped | **6** |
| Trapped-by-keepout | **0** |

**Shortest exitable:** `P0.16` **34.259 mm**, U1.26 F.Cu copper (41.364, 27.150) to pad J18.4 (45.537, 61.154). Exit is an existing stub (via 40.70, 20.80), not a new route.
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

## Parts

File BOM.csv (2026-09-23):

Reference | Quantity | Value | Description | Manufacturer | MPN | Package | DNP/Optional | Function
U1 | 1 | nRF9161-LACA-R7 | LTE-M/NB-IoT/DECT NR+/GNSS SiP (PS v1.0) | Nordic Semiconductor | nRF9161-LACA-R7 | LGA 16.0x10.5mm |  | LTE-M/NB-IoT/DECT NR+/GNSS SiP (PS v1.0)
U2 | 1 | TLV73333PDBV | 3.3 V VDD_GPIO LDO; EN tied to ENABLE | Texas Instruments | TLV73333PDBVR | SOT-23-5 |  | 3.3 V VDD_GPIO LDO; EN tied to ENABLE
U3 | 1 | TPS22919DCKR | GNSS VBIAS high-side load switch; ON=COEX0 | Texas Instruments | TPS22919DCKR | SC-70-6 / SOT-363 |  | GNSS active-antenna bias gate (LOCKED)
U4 | 1 | TPD3F303DPV | SIM ESD/EMI filter per nRF91 HDG | Texas Instruments | TPD3F303DPVR | USON-8 1.45x1.45mm |  | SIM ESD/EMI filter per nRF91 HDG
C1 | 1 | 10uF/16V X5R | VIN bulk after input filter | Murata | GRM21BR61C106ME15 | 0805 |  | VIN bulk after input filter
C2 | 1 | 100nF 10V X5R | VIN HF decoupling | Murata | GRM155R61A104KA01 | 0402 |  | VIN HF decoupling
C3 | 1 | 47uF 10V X5R | VDD1 bulk (nRF91 HDG Table 2 C3) | Murata | GRM21BR61A476ME15 | 0805 |  | VDD1 bulk (nRF91 HDG Table 2 C3)
C4 | 1 | 4.7uF 10V X5R | VDD1 mid decoupling (HDG Table 2) | Murata | GRM155R61A475MEAA | 0402 |  | VDD1 mid decoupling (HDG Table 2)
C5 | 1 | 100nF 10V X5R | VDD1 HF decoupling (HDG Table 2) | Murata | GRM033R61A104KE15 | 0201 |  | VDD1 HF decoupling (HDG Table 2)
C6 | 1 | 15pF 25V C0G | VDD1 RF decoupling (HDG Table 2) | Murata | GJM0335C1E150JB01 | 0201 |  | VDD1 RF decoupling (HDG Table 2)
C7 | 1 | 47uF 10V X5R | VDD2 bulk (HDG Table 2 C10) | Murata | GRM21BR61A476ME15 | 0805 |  | VDD2 bulk (HDG Table 2 C10)
C8 | 1 | 4.7uF 10V X5R | VDD2 mid decoupling | Murata | GRM155R61A475MEAA | 0402 |  | VDD2 mid decoupling
C9 | 1 | 100nF 10V X5R | VDD2 HF decoupling | Murata | GRM033R61A104KE15 | 0201 |  | VDD2 HF decoupling
C10 | 1 | 15pF 25V C0G | VDD2 RF decoupling | Murata | GJM0335C1E150JB01 | 0201 |  | VDD2 RF decoupling
C11 | 1 | 4.7uF 10V X5R | VDD_GPIO bulk | Murata | GRM155R61A475MEAA | 0402 |  | VDD_GPIO bulk
C12 | 1 | 100nF 10V X5R | VDD_GPIO HF | Murata | GRM033R61A104KE15 | 0201 |  | VDD_GPIO HF
C13 | 1 | 4.7uF 10V X5R | DEC0 (nRF91x1 / PCN134 4.7uF not 47uF) | Murata | GRM155R61A475MEAA | 0402 |  | DEC0 (nRF91x1 / PCN134 4.7uF not 47uF)
C14 | 1 | 100nF 10V X5R | ENABLE decoupling (HDG 4.3) | Murata | GRM033R61A104KE15 | 0201 |  | ENABLE decoupling (HDG 4.3)
C21 | 1 | DNP High-Q | LTE pi-match shunt (unpopulated until antenna tune) | Murata | GJM1555C1H100JB01 | 0402 | DNP | LTE pi-match shunt (unpopulated until antenna tune)
C22 | 1 | DNP High-Q | LTE pi-match shunt (DNP) | Murata | GJM1555C1H100JB01 | 0402 | DNP | LTE pi-match shunt (DNP)
C23 | 1 | DNP High-Q | AUX pi-match shunt (DNP) | Murata | GJM1555C1H100JB01 | 0402 | DNP | AUX pi-match shunt (DNP)
C24 | 1 | DNP High-Q | AUX pi-match shunt (DNP) | Murata | GJM1555C1H100JB01 | 0402 | DNP | AUX pi-match shunt (DNP)
C27 | 1 | 100pF C0G | GNSS DC block (nWP033 active-antenna bias-T) | Murata | GJM0335C1E101JB01 | 0201 |  | GNSS DC block (nWP033 active-antenna bias-T)
C28 | 1 | 100pF | GNSS Vbias HF filter | Murata | GRM155R71H101KA01 | 0402 |  | GNSS Vbias HF filter
C29 | 1 | 10nF | GNSS Vbias mid filter | Murata | GRM155R71H103KA01 | 0402 |  | GNSS Vbias mid filter
C30 | 1 | 100nF | GNSS Vbias bulk filter | Murata | GRM155R61A104KA01 | 0402 |  | GNSS Vbias bulk filter
C31 | 1 | DNP | GNSS match shunt (DNP) | Murata | GJM1555C1H100JB01 | 0402 | DNP | GNSS match shunt (DNP)
C32 | 1 | DNP | GNSS match shunt (DNP) | Murata | GJM1555C1H100JB01 | 0402 | DNP | GNSS match shunt (DNP)
C33 | 1 | 100nF | SIM_1V8 decoupling | Murata | GRM155R61A104KA01 | 0402 |  | SIM_1V8 decoupling
C34 | 1 | 220nF | SIM VCC decoupling (ISO 7816 / HDG) | Murata | GRM155R61A224KE01 | 0402 |  | SIM VCC decoupling (ISO 7816 / HDG)
C35 | 1 | 22pF C0G | SIM_CLK filter | Murata | GRM0335C1E220JA01 | 0201 |  | SIM_CLK filter
C36 | 1 | 22pF C0G | SIM_RST filter | Murata | GRM0335C1E220JA01 | 0201 |  | SIM_RST filter
C37 | 1 | 22pF C0G | SIM_IO filter | Murata | GRM0335C1E220JA01 | 0201 |  | SIM_IO filter
C38 | 1 | 22pF C0G | SIM_1V8 HF | Murata | GRM0335C1E220JA01 | 0201 |  | SIM_1V8 HF
C39 | 1 | DNP | Optional nRESET cap (not fitted; HDG forbids extra PU) | Murata | GRM033R61A104KE15 | 0201 | DNP | Optional nRESET cap (not fitted; HDG forbids extra PU)
D1 | 1 | PMEG4030ER | Reverse-polarity Schottky | Nexperia | PMEG4030ER | SOD-123W |  | Reverse-polarity Schottky
D2 | 1 | SMAJ5.0A | VIN TVS 5.0 V | Littelfuse | SMAJ5.0A | DO-214AC |  | VIN TVS 5.0 V
D3 | 1 | Green LED | Power LED on VIN | Kingbright | KP-2012SGC | 0603 |  | Power LED on VIN
D4 | 1 | Green LED | User LED1 on P0.00 | Kingbright | KP-2012SGC | 0603 |  | User LED1 on P0.00
D5 | 1 | Green LED | User LED2 on P0.01 | Kingbright | KP-2012SGC | 0603 |  | User LED2 on P0.01
D6 | 1 | Green LED | User LED3 on P0.02 | Kingbright | KP-2012SGC | 0603 |  | User LED3 on P0.02
D7 | 1 | Green LED | User LED4 on P0.03 | Kingbright | KP-2012SGC | 0603 | Optional | User LED4 on P0.03
F1 | 1 | 2A fuse | VIN fuse | Littelfuse | 0468002.NR | 1206 |  | VIN fuse
FB1 | 1 | BLM18KG221SN1 | VDD1 ferrite (nRF91 HDG) | Murata | BLM18KG221SN1D | 0603 |  | VDD1 ferrite (nRF91 HDG)
FB2 | 1 | BLM18KG221SN1 | VDD2 ferrite 1 | Murata | BLM18KG221SN1D | 0603 |  | VDD2 ferrite 1
FB3 | 1 | BLM18KG221SN1 | VDD2 ferrite 2 (nRF9161 DK extra FB3) | Murata | BLM18KG221SN1D | 0603 |  | VDD2 ferrite 2 (nRF9161 DK extra FB3)
FB4 | 1 | BLM18PG221SN1 | VIN input ferrite | Murata | BLM18PG221SN1D | 0805 |  | VIN input ferrite
FB5 | 1 | BLM15HG102SN1 | GNSS bias ferrite (land L_0402_1005Metric) | Murata | BLM15HG102SN1D | 0402 |  | GNSS bias ferrite; schematic footprint fixed 0603→0402
L1 | 1 | 0R / DNP match | LTE series match placeholder (0R until tune; LQW15AN family per HDG) | Murata | LQW15AN10NG00 | 0402 | Fit 0R until VNA; then LQW15AN | LTE series match placeholder (0R until tune; LQW15AN family per HDG)
L2 | 1 | 0R / DNP match | AUX series match placeholder | Murata | LQW15AN10NG00 | 0402 | Fit 0R until VNA; then LQW15AN | AUX series match placeholder
L4 | 1 | 100nH | GNSS bias-T RF choke (nWP033) | Murata | LQW15ANR10J00 | 0402 |  | GNSS bias-T RF choke (nWP033)
R1 | 1 | 10k | ENABLE series to VDD1 (HDG 4.3) | Yageo | RC0201FR-0710KL | 0201 |  | ENABLE series to VDD1 (HDG 4.3)
R2 | 1 | 0.05 ohm 1% | Current-sense (bypass with JP1) | Yageo | PE1206FRF070R05L | 1206 |  | Current-sense (bypass with JP1)
R3 | 1 | 1k | Power LED resistor | Yageo | RC0402FR-071KL | 0402 |  | Power LED resistor
R4 | 1 | 0R | COEX0 to GNSS_LNA_EN (active-antenna enable) | Yageo | RC0402JR-070RL | 0402 |  | COEX0 to GNSS_LNA_EN (active-antenna enable)
R5 | 1 | 1k | nRESET series (HDG 4.8; no external pull-up) | Yageo | RC0201FR-071KL | 0201 |  | nRESET series (HDG 4.8; no external pull-up)
R10 | 1 | 1k | LED1 series | Yageo | RC0402FR-071KL | 0402 |  | LED1 series
R11 | 1 | 1k | LED2 series | Yageo | RC0402FR-071KL | 0402 |  | LED2 series
R12 | 1 | 1k | LED3 series | Yageo | RC0402FR-071KL | 0402 |  | LED3 series
R13 | 1 | 1k | LED4 series | Yageo | RC0402FR-071KL | 0402 |  | LED4 series
R14 | 1 | 10k | USER button pull-up to VDD_GPIO | Yageo | RC0402FR-0710KL | 0402 |  | USER button pull-up to VDD_GPIO
JP1 | 1 | I_MEAS jumper | Close to bypass R2; open for current measurement | Keystone | solder jumper | SJ-2 open |  | Close to bypass R2; open for current measurement
JP2 | 1 | SIM_VCC jumper | Connect SIM_1V8 to card VCC; close for operation | Keystone | solder jumper | SJ-2 open |  | Connect SIM_1V8 to card VCC; close for operation
J1 | 1 | VIN 3.0-5.5V header | Main power input | Wurth | 61300211121 | 1x02 2.54mm |  | Main power input
J2 | 1 | U.FL LTE/NR+ | External LTE/DECT NR+ antenna | Hirose | U.FL-R-SMT-1(10) | U.FL |  | External LTE/DECT NR+ antenna
J3 | 1 | SWF LTE | LTE RF test connector (Nordic-style) | Murata | MM8130-2600 | SWF | Optional | LTE RF test connector (Nordic-style)
J5 | 1 | U.FL GNSS | External active GNSS antenna | Hirose | U.FL-R-SMT-1(10) | U.FL |  | External active GNSS antenna
J6 | 1 | SWF GNSS | GNSS RF test connector | Murata | MM8130-2600 | SWF | Optional | GNSS RF test connector
J7 | 1 | nano-SIM 4FF | nano-SIM connector | JAE | SF72S006V4BR | SF72S006 |  | nano-SIM connector
J8 | 1 | SWD 10-pin | ARM Cortex 10-pin (J-Link compatible) | Samtec | FTSH-105-01-L-DV | 2x05 1.27mm |  | ARM Cortex 10-pin (J-Link compatible)
J9 | 1 | UART0 header | UART TX/RX/RTS/CTS + power | Wurth | 61300611121 | 1x06 2.54mm |  | UART TX/RX/RTS/CTS + power
J10 | 1 | SPI0 header | SPI SCK/MOSI/MISO/CS + power | Wurth | 61300611121 | 1x06 2.54mm |  | SPI SCK/MOSI/MISO/CS + power
J11 | 1 | I2C0 header | I2C SDA/SCL + power | Wurth | 61300411121 | 1x04 2.54mm |  | I2C SDA/SCL + power
J12 | 1 | GPIO P0.00-15 | GPIO expansion 0-15 | Wurth | 61302011121 | 1x20 2.54mm |  | GPIO expansion 0-15
J13 | 1 | GPIO P0.16-31 | GPIO expansion 16-31 | Wurth | 61302011121 | 1x20 2.54mm |  | GPIO expansion 16-31
J14 | 1 | MAGPIO/MIPI RFFE | MAGPIO0-2 MIPI VIO/SCLK/SDATA | Wurth | 61300611121 | 1x06 1.27mm |  | MAGPIO0-2 MIPI VIO/SCLK/SDATA
J15 | 1 | COEX header | COEX0-2 + power | Wurth | 61300611121 | 1x06 1.27mm |  | COEX0-2 + power
J16 | 1 | I2S header | I2S SCK/LRCK/SDOUT/SDIN | Wurth | 61300611121 | 1x06 2.54mm |  | I2S SCK/LRCK/SDOUT/SDIN
J17 | 1 | PDM header | PDM CLK/DIN | Wurth | 61300411121 | 1x04 2.54mm |  | PDM CLK/DIN
J18 | 1 | ADC AIN0-7 | SAADC AIN0-7 | Wurth | 61301011121 | 1x10 2.54mm |  | SAADC AIN0-7
SW1 | 1 | DISABLE | Grounds ENABLE (system disable) | C&K | KXT311LHS | KXT3 |  | Grounds ENABLE (system disable)
SW2 | 1 | RESET | nRESET button | C&K | KXT311LHS | KXT3 |  | nRESET button
SW3 | 1 | USER | User button on P0.08 | C&K | KXT311LHS | KXT3 |  | User button on P0.08
TP1-TP20 | 20 | Test points | Power/RF/SIM/SWD/I_MEAS test access | Keystone | 5015 | D1.0/1.5mm pad |  | Power/RF/SIM/SWD/I_MEAS test access

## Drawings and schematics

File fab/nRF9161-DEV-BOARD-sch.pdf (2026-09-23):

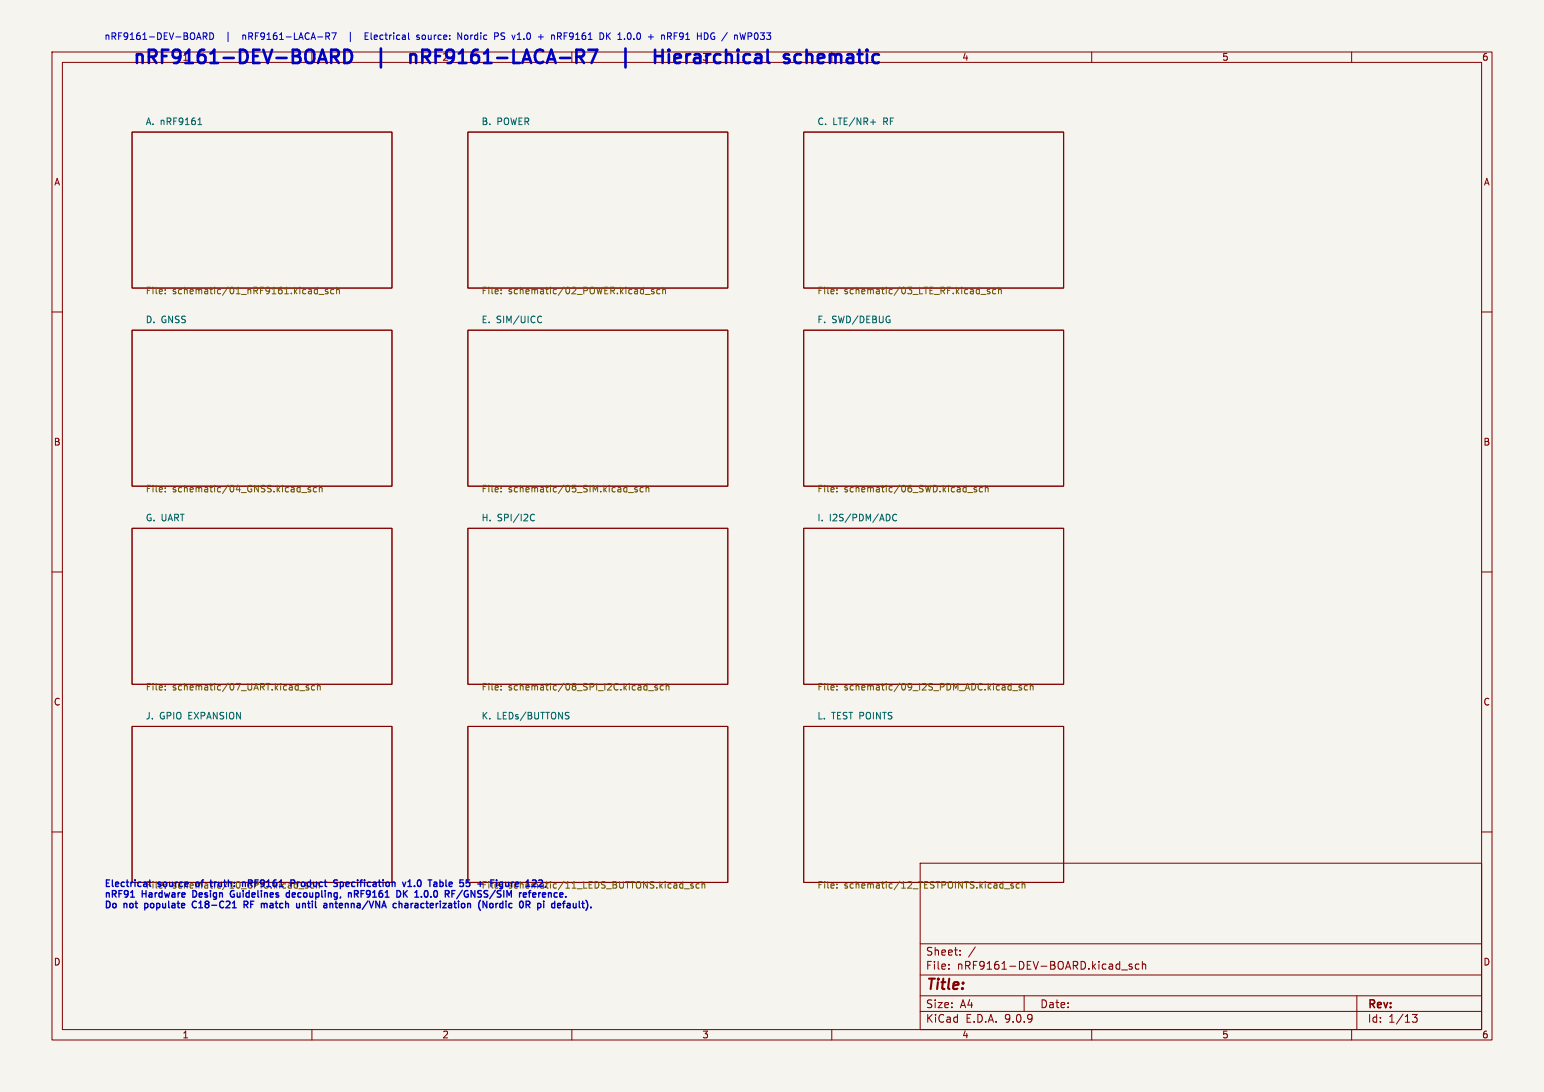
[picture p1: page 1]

File: schematic/03_LTE_RF.kicad_sch E. SIM/UICC

Id: 1/13 Title: File: nRF9161-DEV-BOARD.kicad_sch Sheet: /

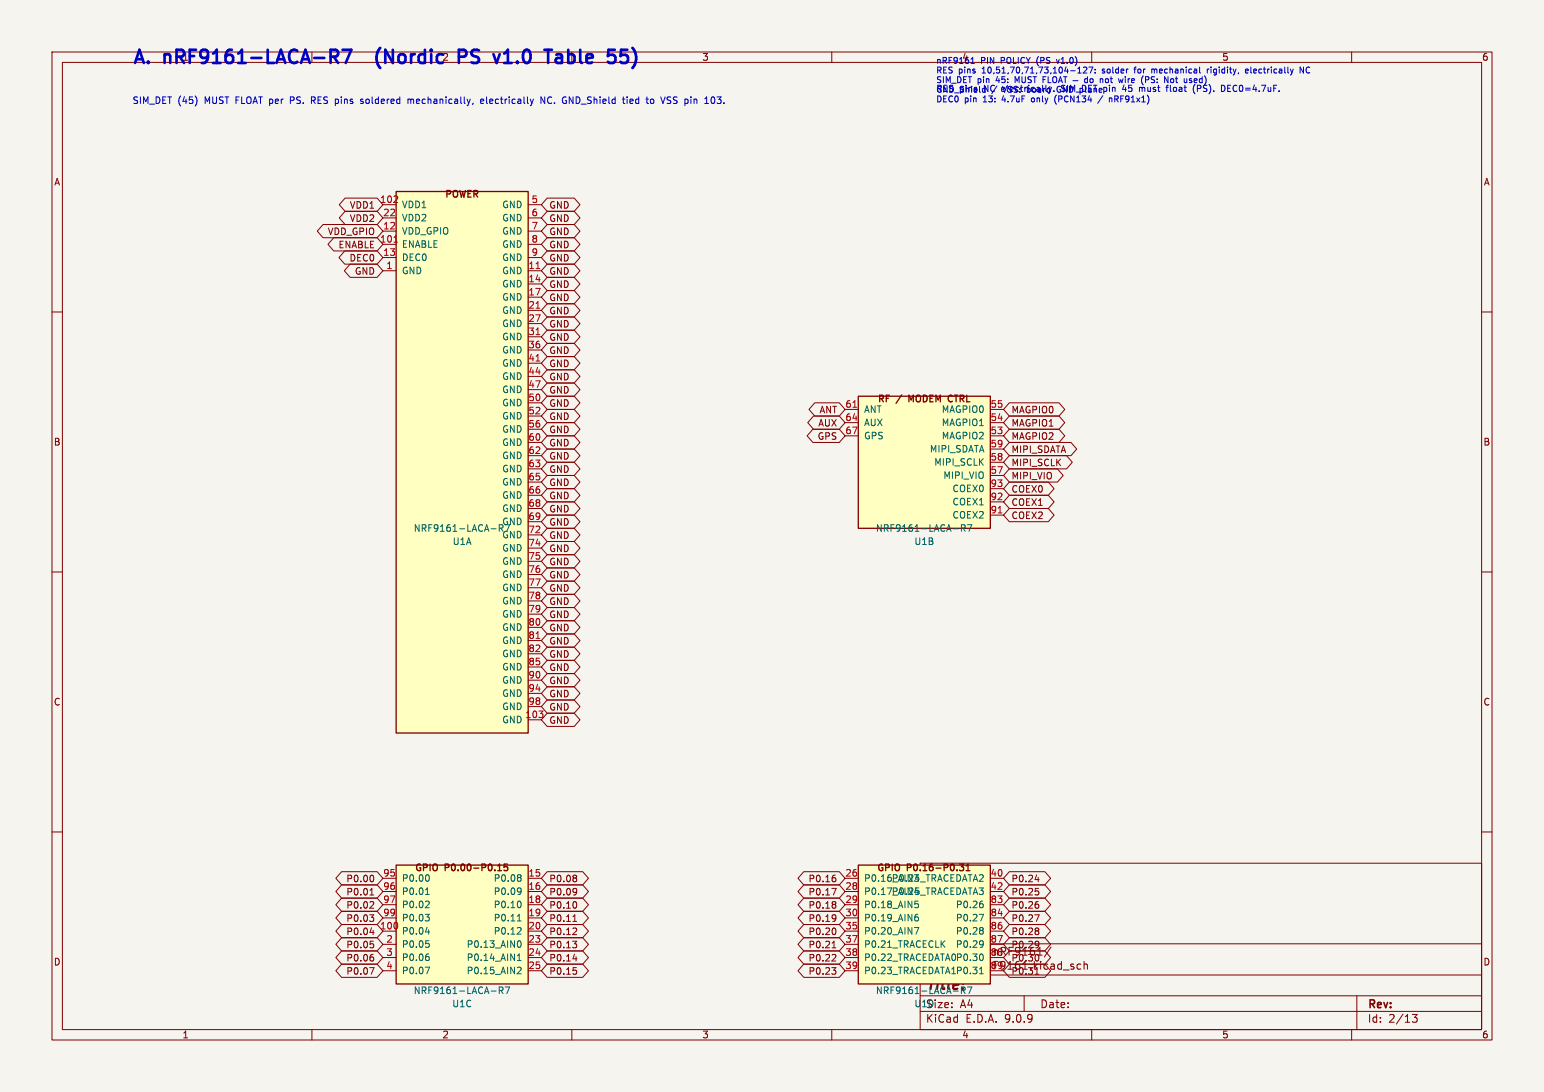
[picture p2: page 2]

SIM_DET pin 45: MUST FLOAT þÿ do not wire (PS: Not used) GND_Shield / VSS: board GND plane DEC0 pin 13: 4.7uF only (PCN134 / nRF91x1)

GND GND GND GND GND

GND GND GND GND GND GND GND GND

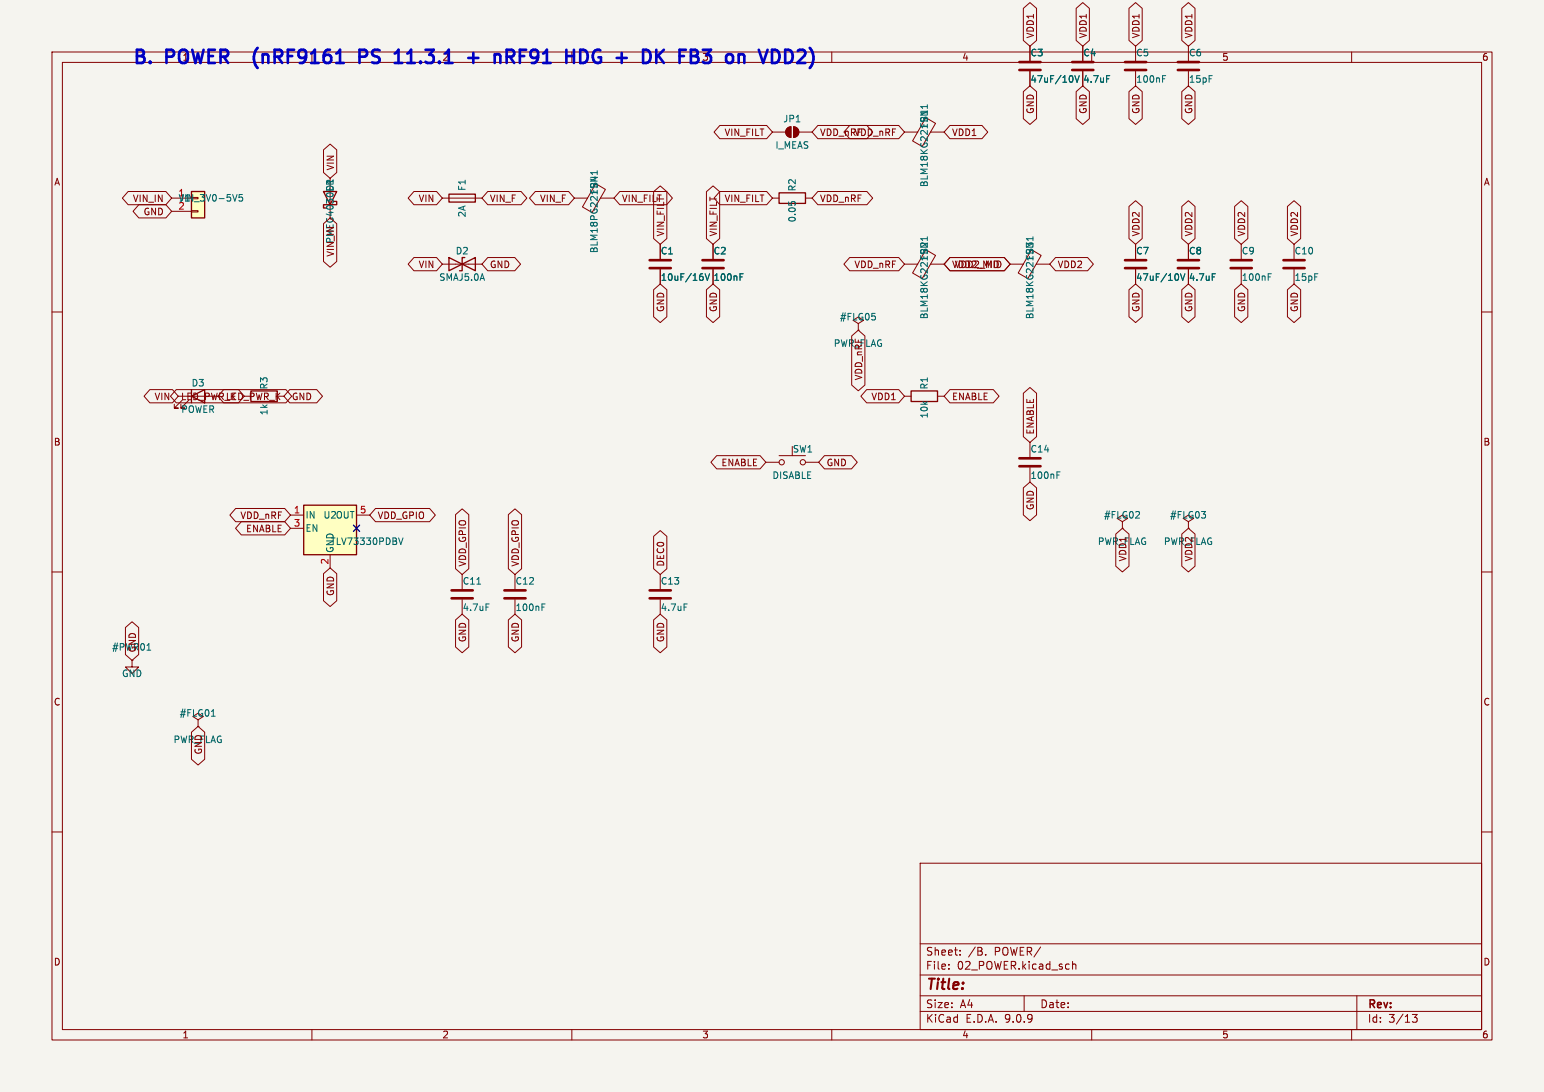
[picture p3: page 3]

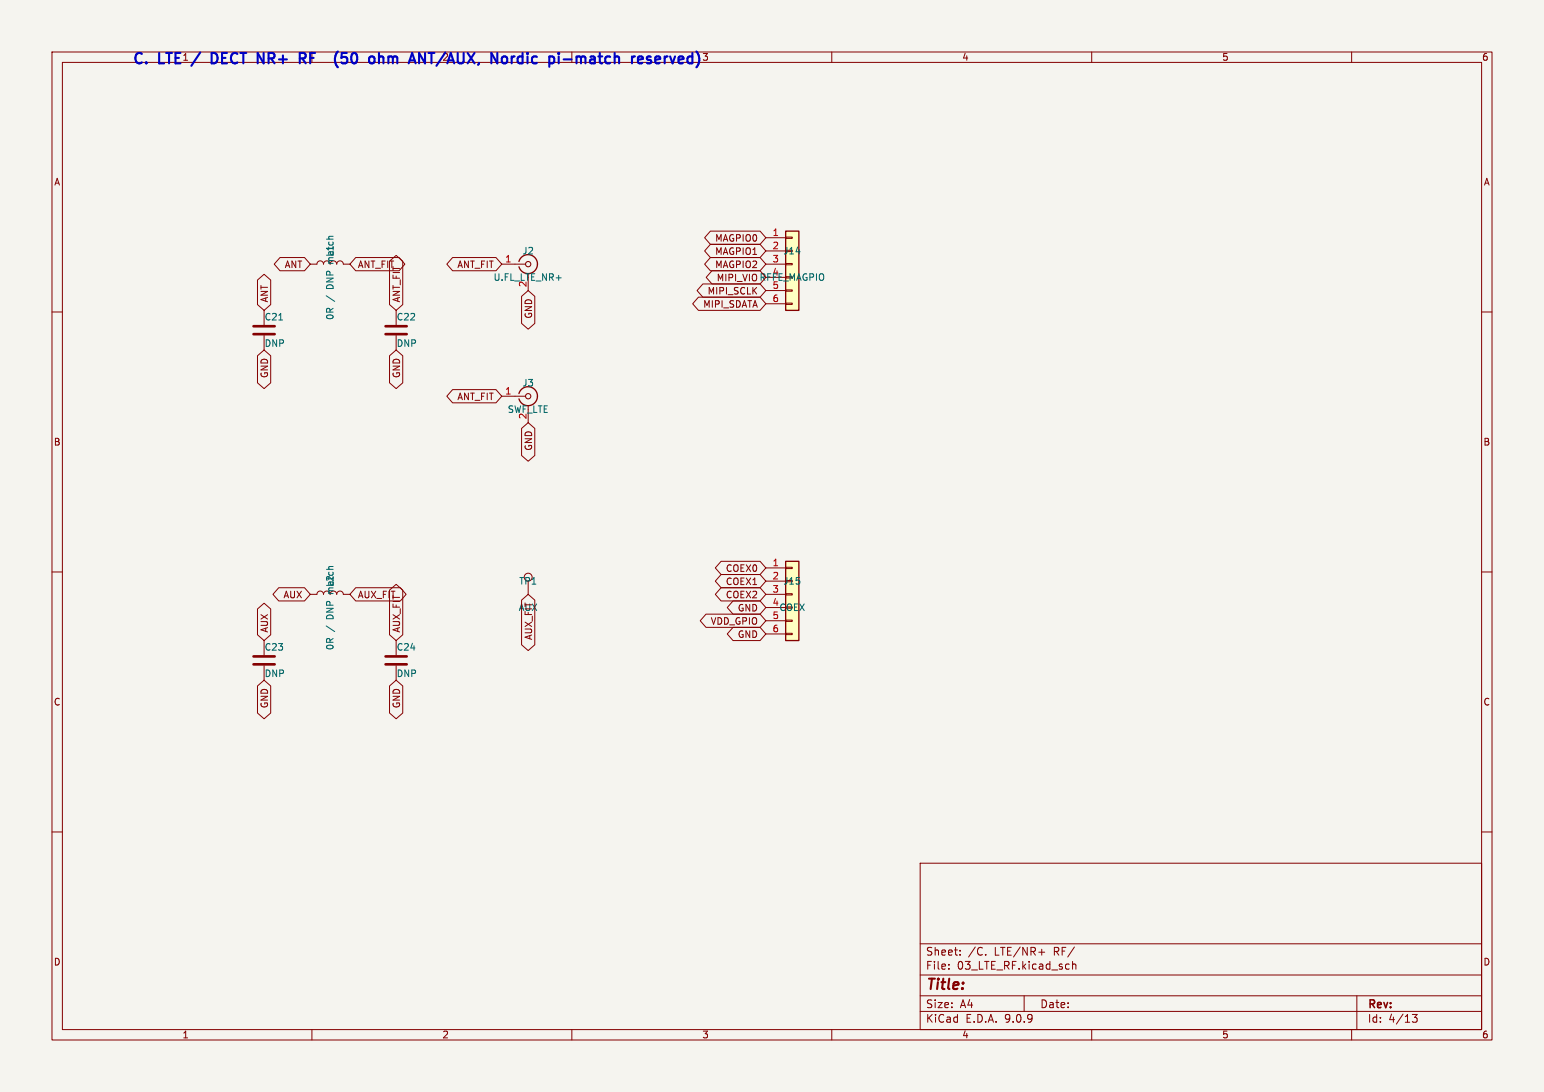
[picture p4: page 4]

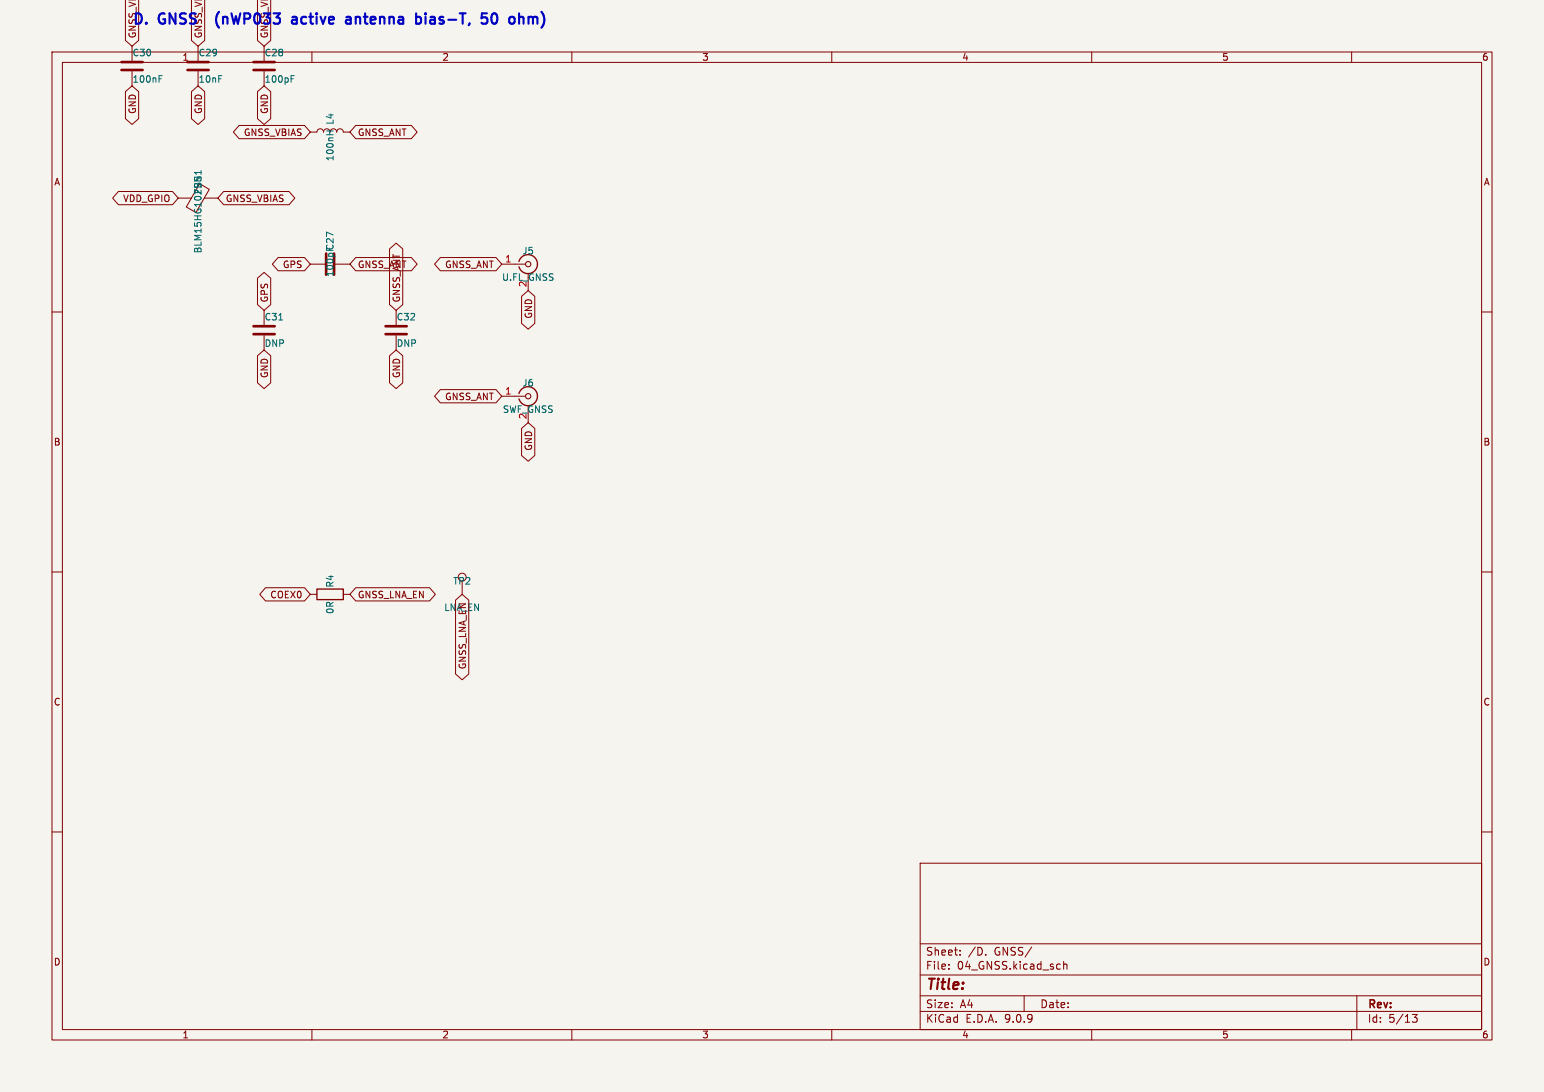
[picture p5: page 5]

Id: 5/13 Title: File: 04_GNSS.kicad_sch Sheet: /D. GNSS/

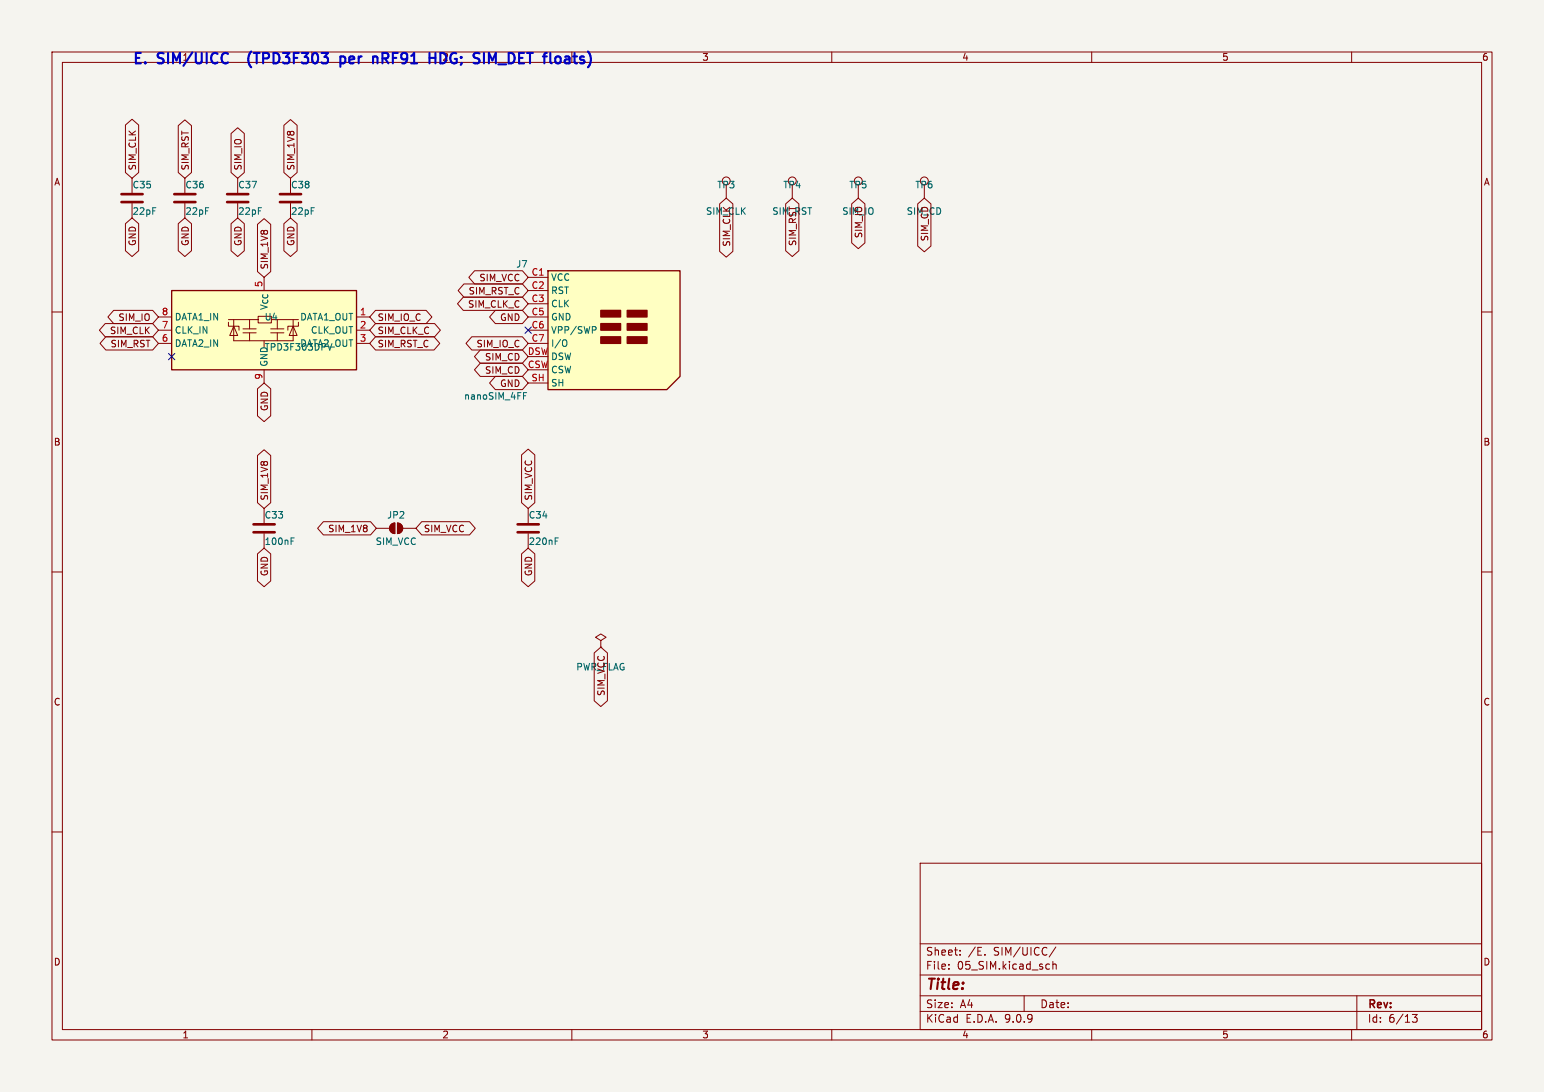
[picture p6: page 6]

Id: 6/13 Title: File: 05_SIM.kicad_sch Sheet: /E. SIM/UICC/

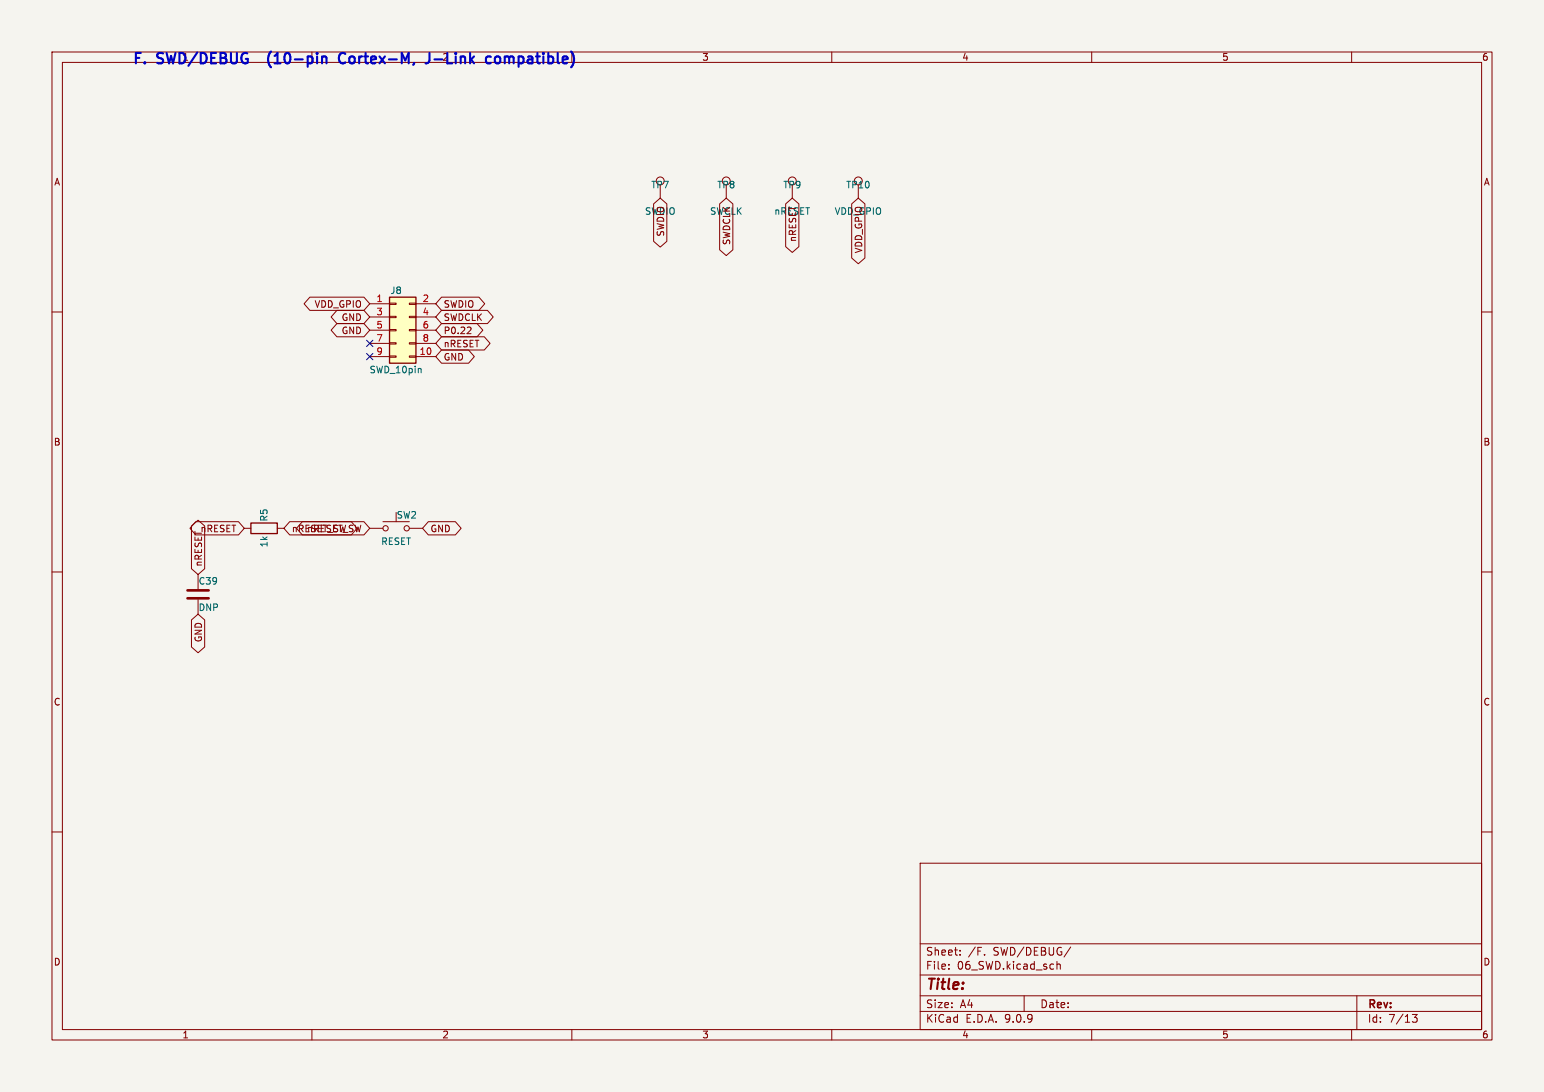
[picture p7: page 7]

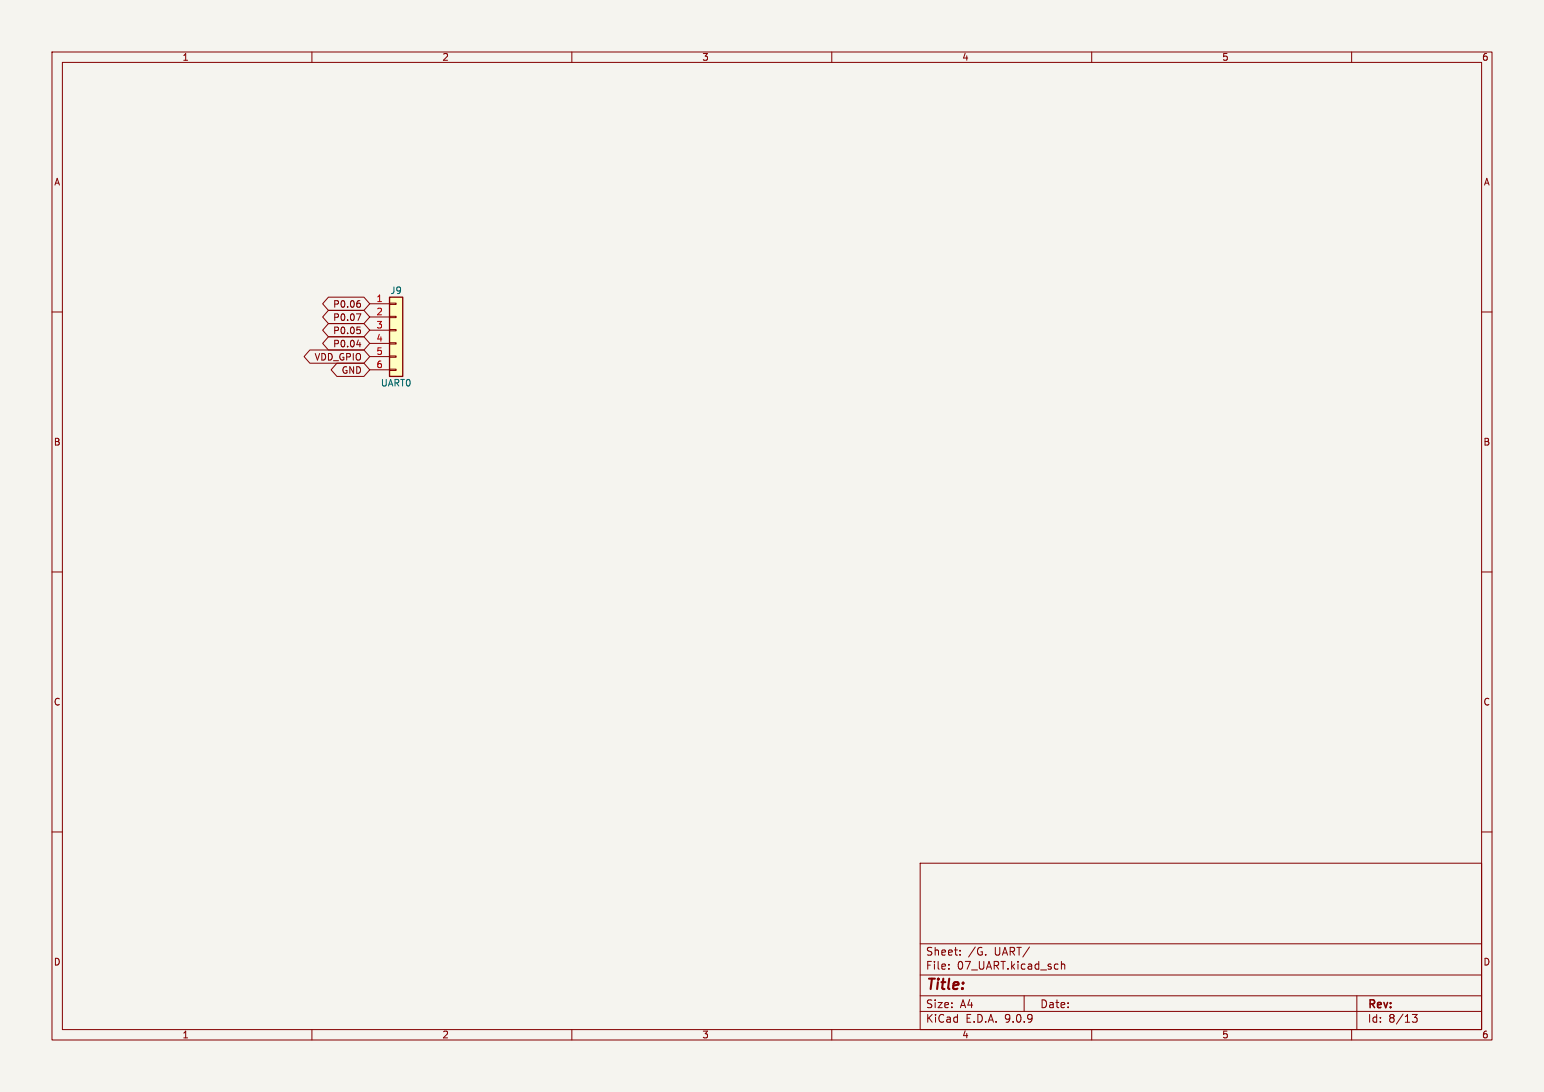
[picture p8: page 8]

Id: 8/13 Title: File: 07_UART.kicad_sch Sheet: /G. UART/

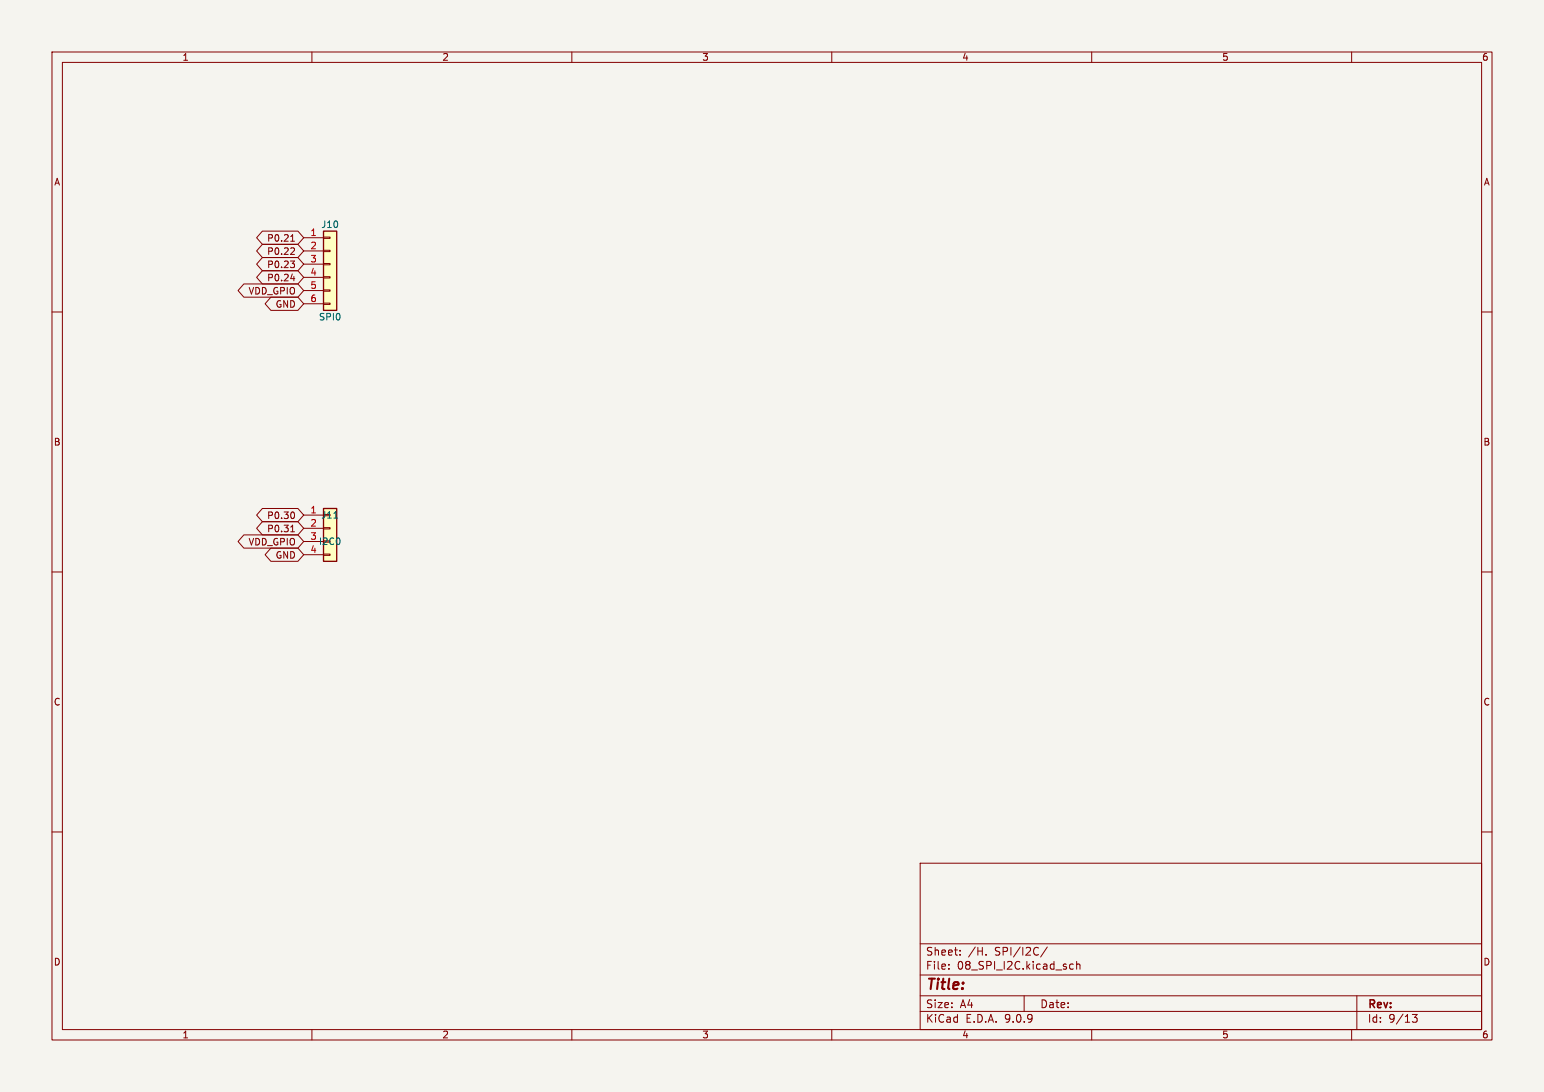
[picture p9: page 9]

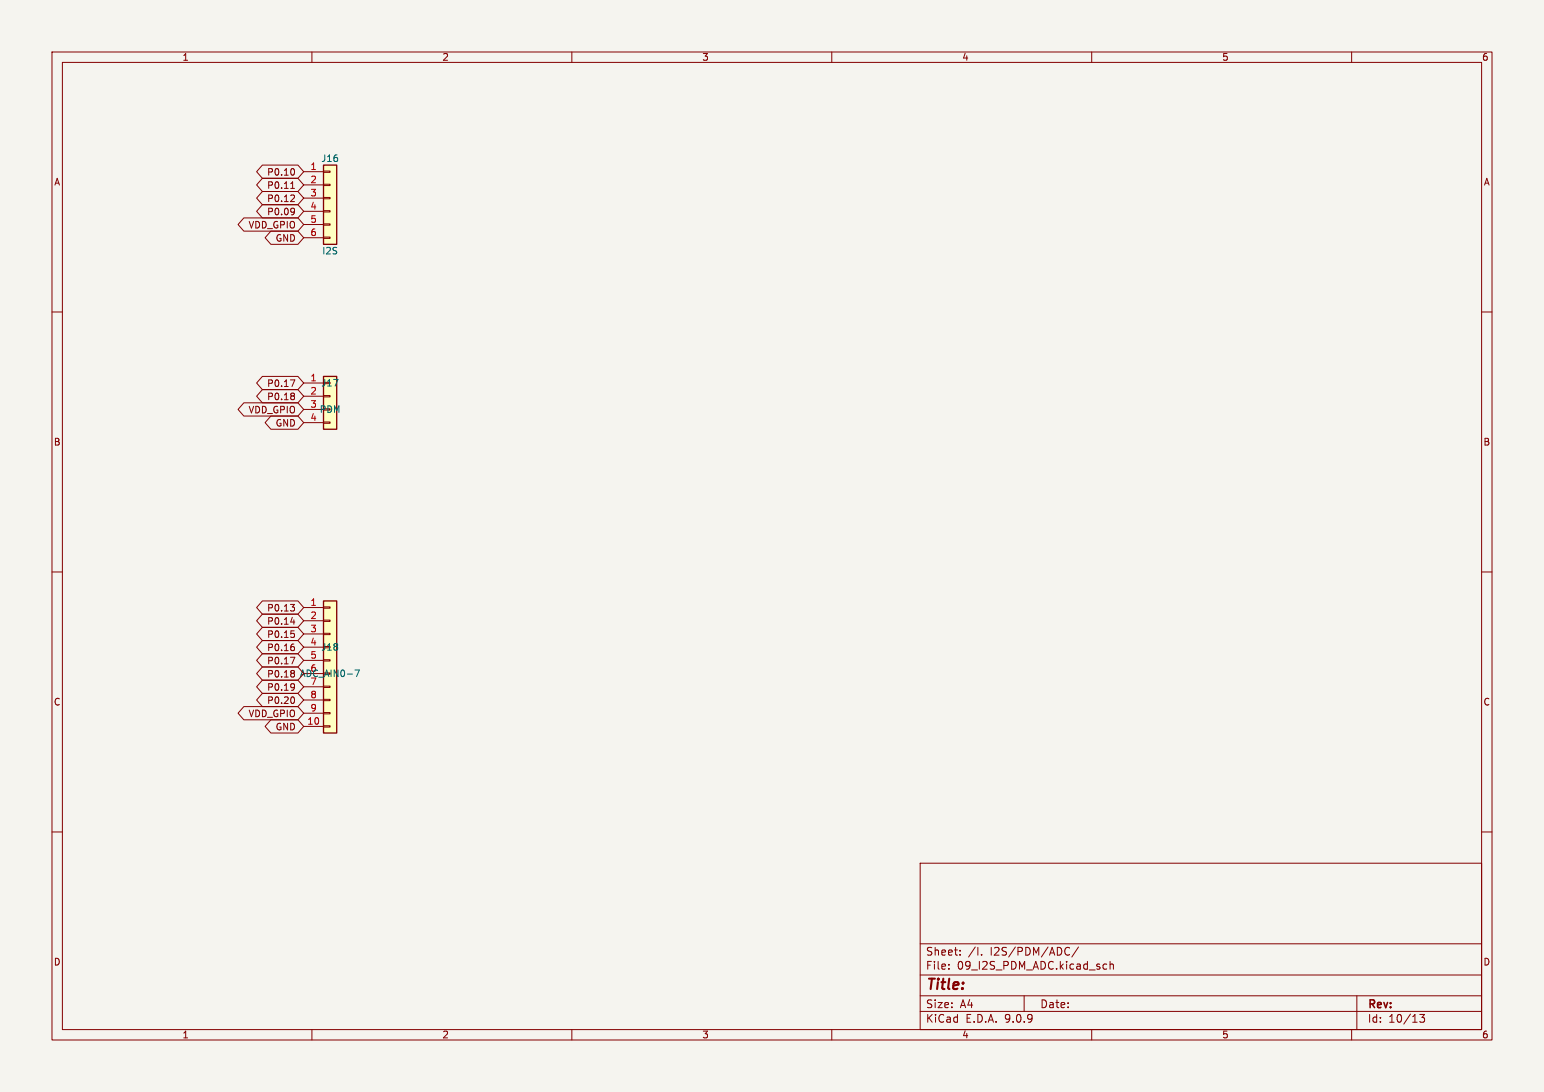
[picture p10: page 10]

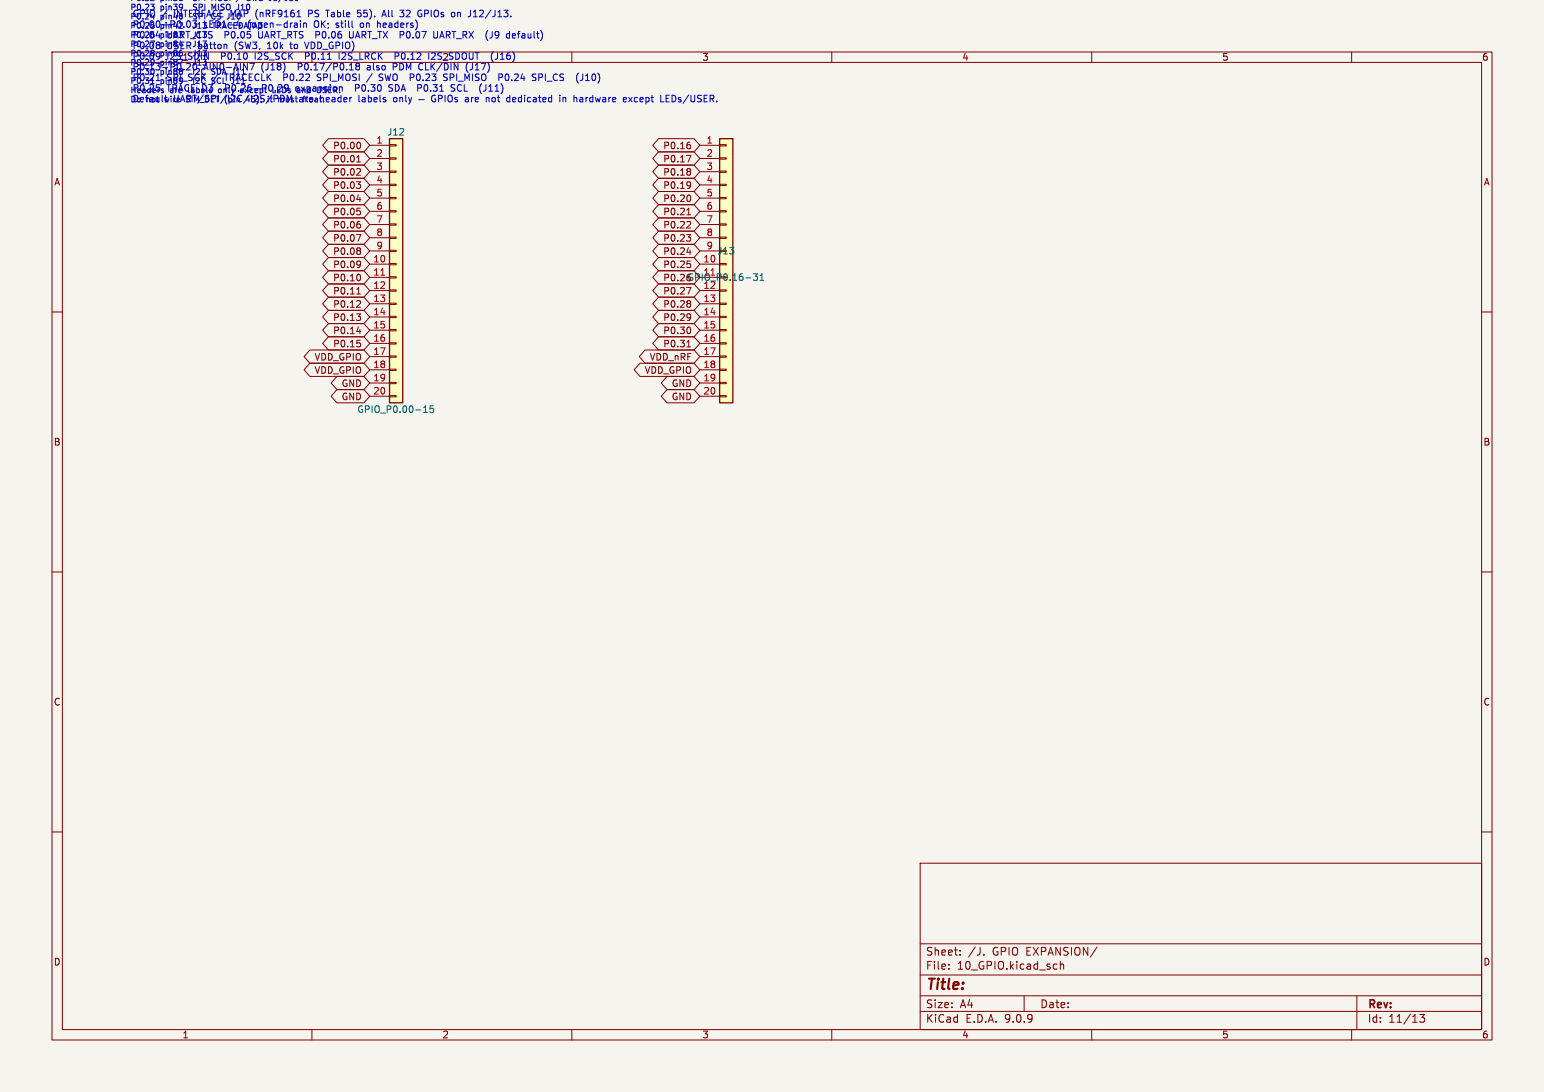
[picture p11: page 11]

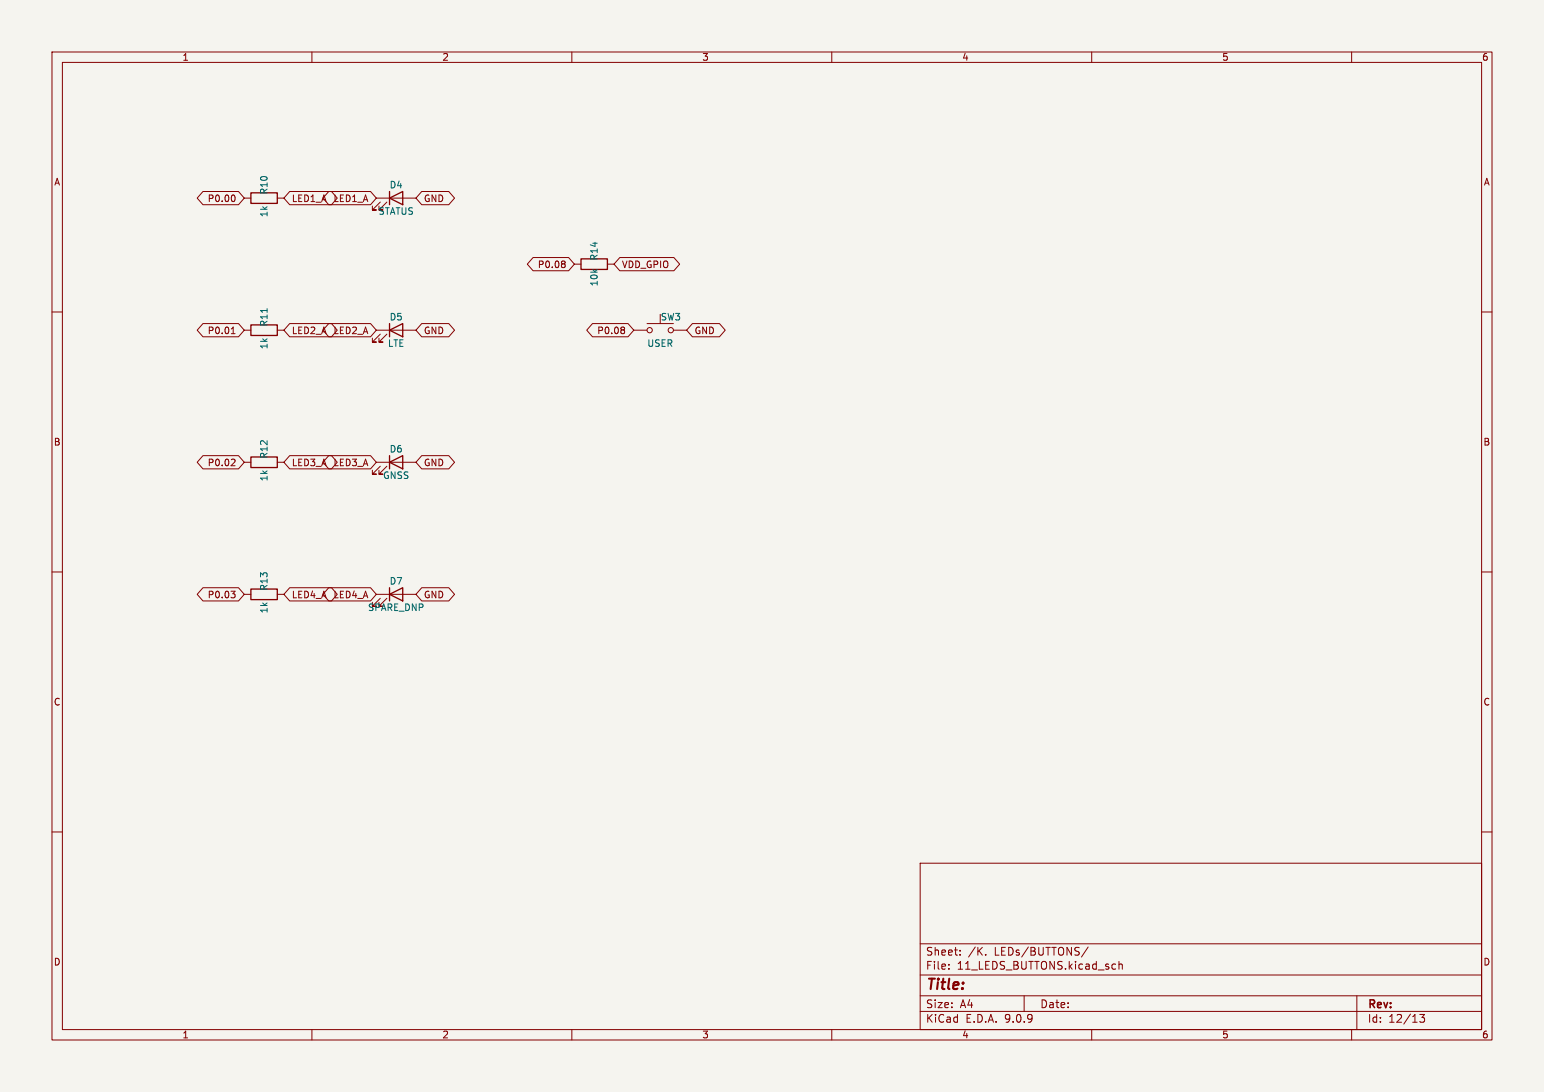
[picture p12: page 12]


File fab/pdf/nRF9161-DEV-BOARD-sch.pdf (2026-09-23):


File: schematic/03_LTE_RF.kicad_sch E. SIM/UICC

Id: 1/13 Title: File: nRF9161-DEV-BOARD.kicad_sch Sheet: /

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

GND GND GND GND GND

GND GND GND GND GND GND GND GND




Id: 5/13 Title: File: 04_GNSS.kicad_sch Sheet: /D. GNSS/


Id: 6/13 Title: File: 05_SIM.kicad_sch Sheet: /E. SIM/UICC/



Id: 8/13 Title: File: 07_UART.kicad_sch Sheet: /G. UART/


















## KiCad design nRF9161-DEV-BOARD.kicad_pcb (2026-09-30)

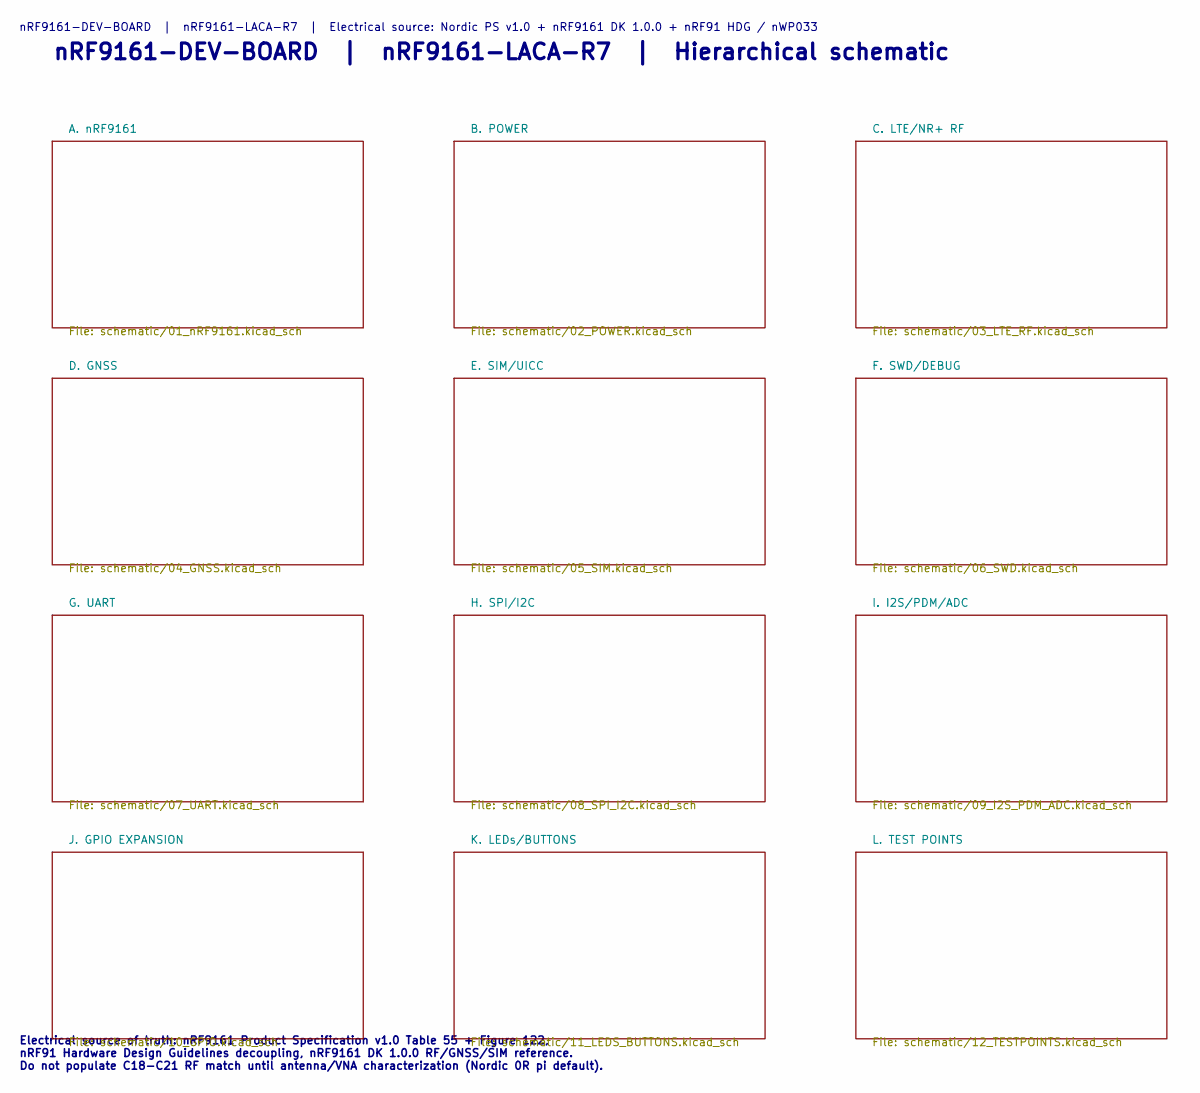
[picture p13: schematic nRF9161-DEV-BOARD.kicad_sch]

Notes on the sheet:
nRF9161-DEV-BOARD | nRF9161-LACA-R7 | Electrical source: Nordic PS v1.0 + nRF9161 DK 1.0.0 + nRF91 HDG / nWP033
nRF9161-DEV-BOARD | nRF9161-LACA-R7 | Hierarchical schematic
Electrical source of truth: nRF9161 Product Specification v1.0 Table 55 + Figure 122, nRF91 Hardware Design Guidelines decoupling, nRF9161 DK 1.0.0 RF/GNSS/SIM reference. Do not populate C18-C21 RF match until antenna/VNA characterization (Nordic 0R pi default).

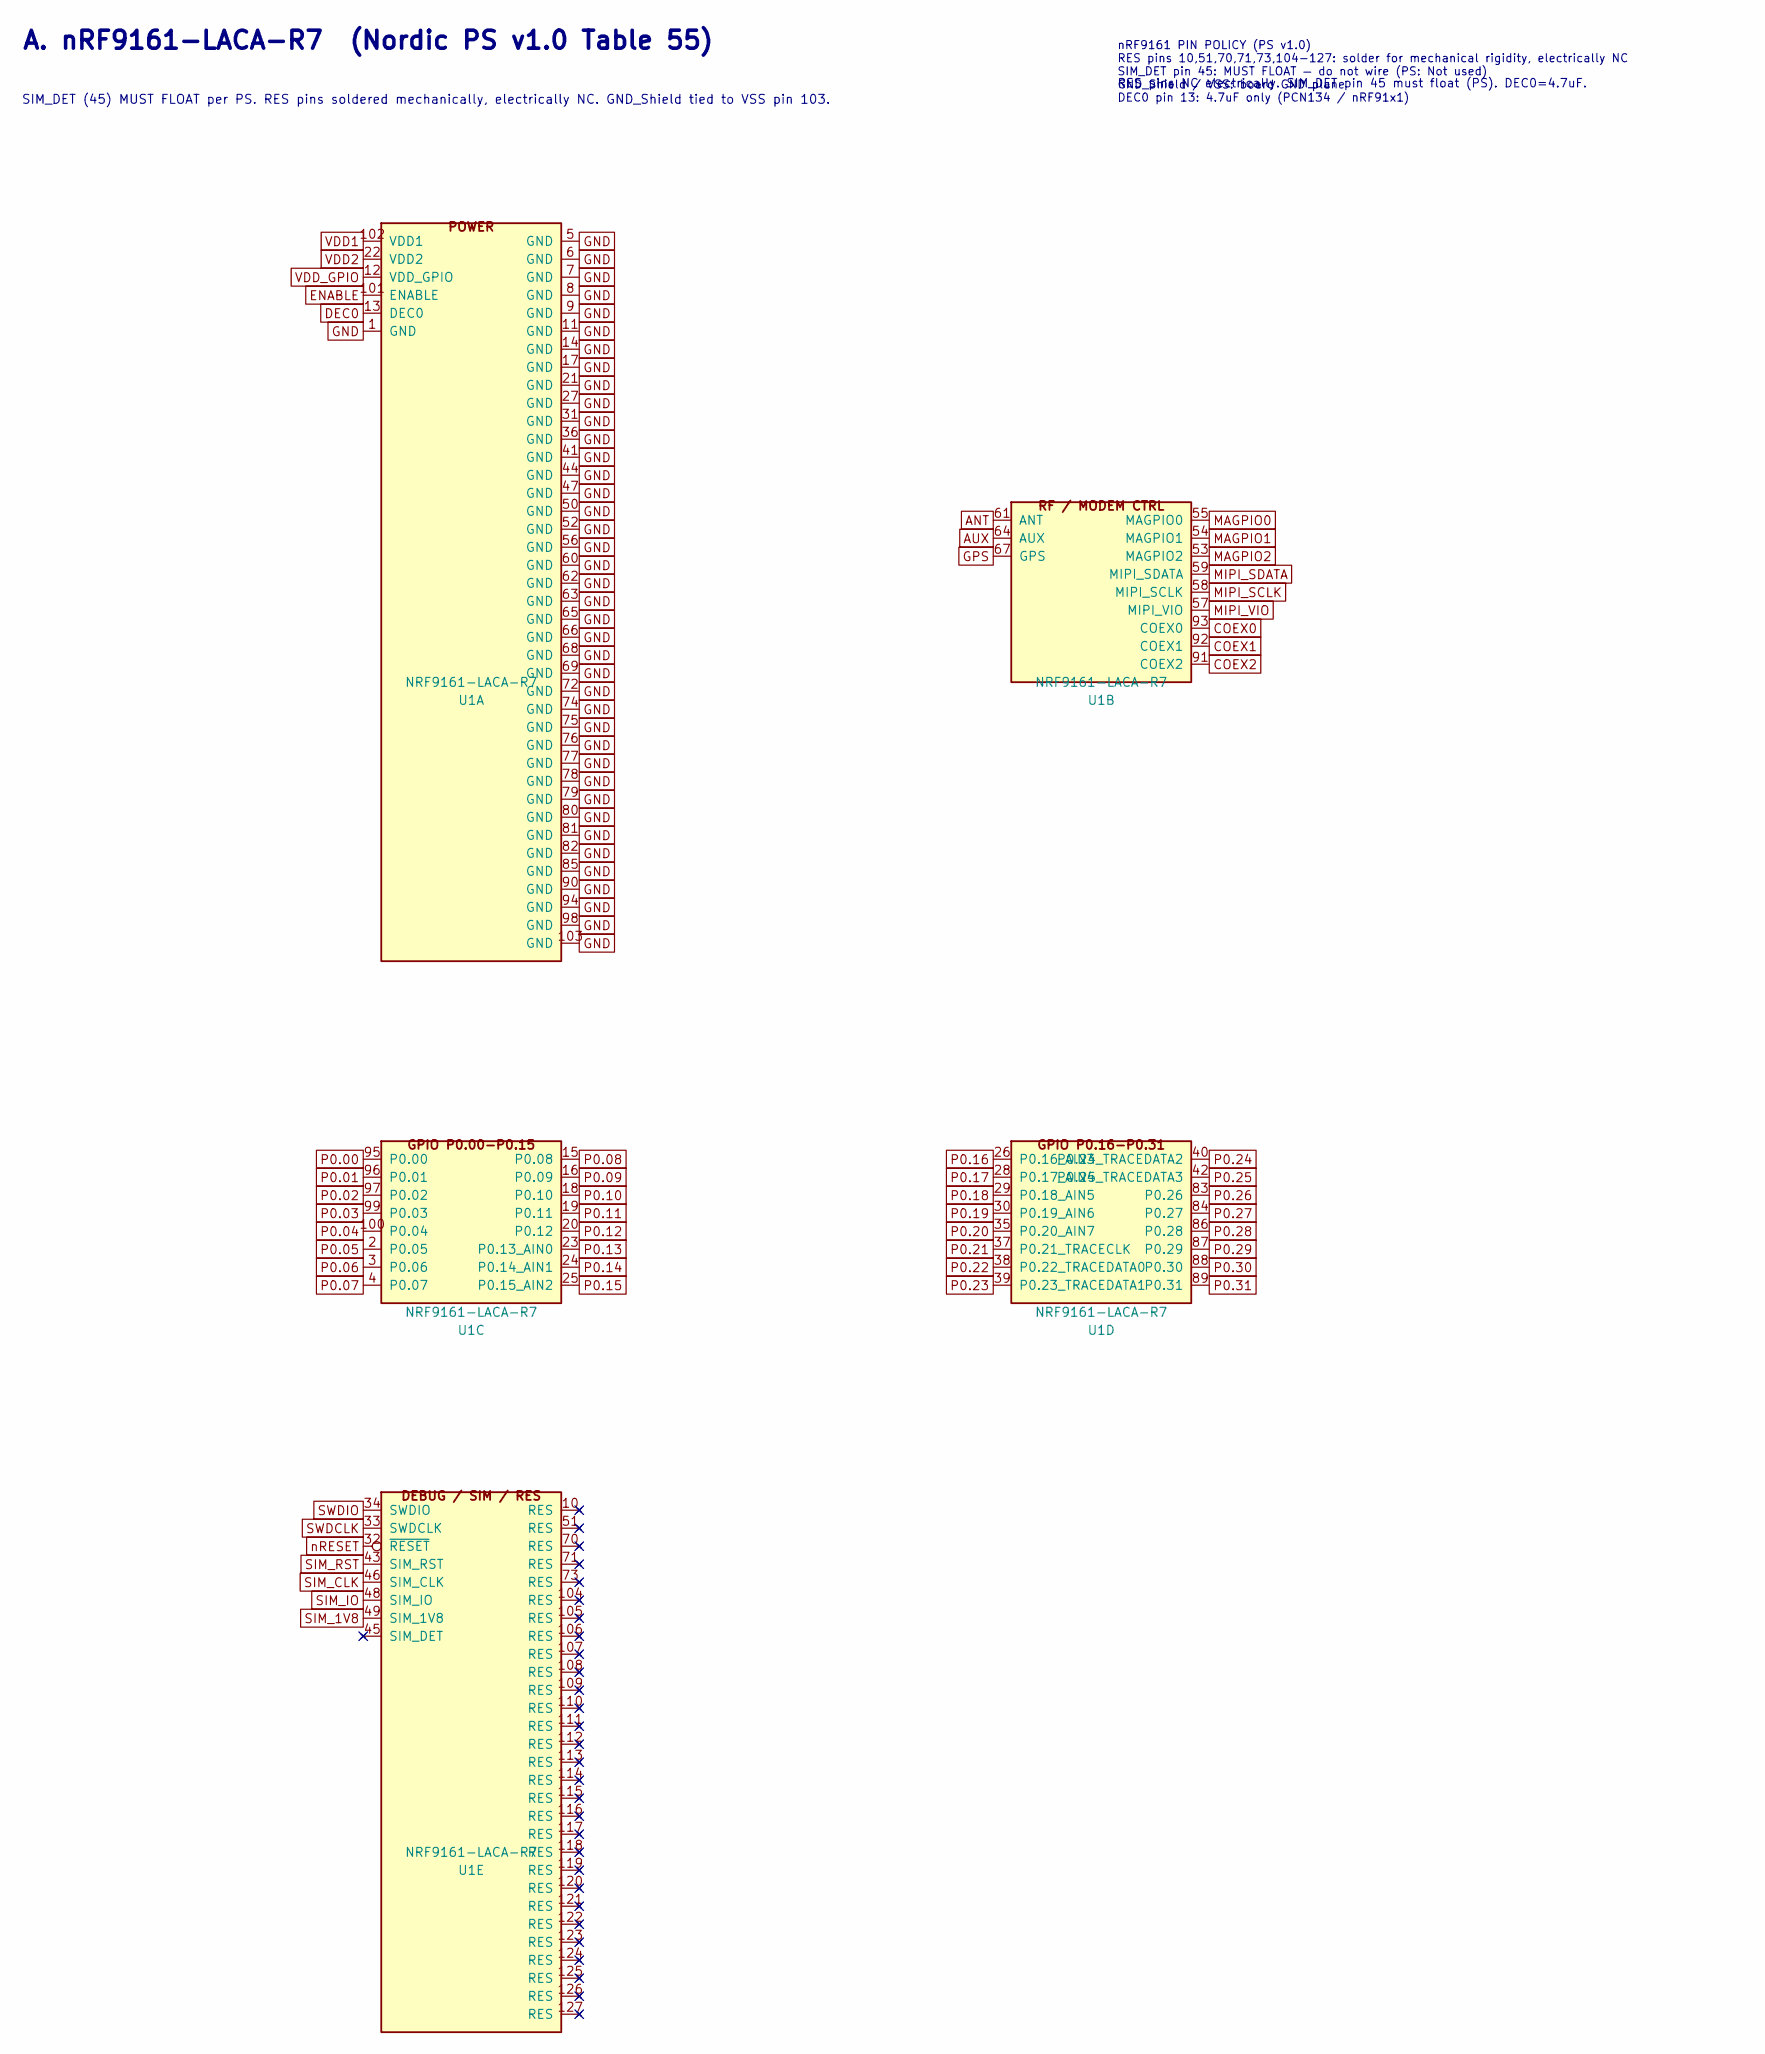
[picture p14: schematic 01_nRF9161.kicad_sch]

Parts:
U1: NRF9161-LACA-R7; nRF9161_LGA_16.0x10.5mm

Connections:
ANT: U1.61 (ANT); also elsewhere on the board
AUX: U1.64 (AUX); also elsewhere on the board
COEX0: U1.93 (COEX0); also elsewhere on the board
COEX1: U1.92 (COEX1); also elsewhere on the board
COEX2: U1.91 (COEX2); also elsewhere on the board
DEC0: U1.13 (DEC0); also elsewhere on the board
ENABLE: U1.101 (ENABLE); also elsewhere on the board
GND: U1.1 (GND), U1.5 (GND), U1.6 (GND), U1.7 (GND), U1.8 (GND), U1.9 (GND), U1.11 (GND), U1.14 (GND), U1.17 (GND), U1.21 (GND), U1.27 (GND), U1.31 (GND), U1.36 (GND), U1.41 (GND), U1.44 (GND), U1.47 (GND), U1.50 (GND), U1.52 (GND), U1.56 (GND), U1.60 (GND), U1.62 (GND), U1.63 (GND), U1.65 (GND), U1.66 (GND), U1.68 (GND), U1.69 (GND), U1.72 (GND), U1.74 (GND), U1.75 (GND), U1.76 (GND), U1.77 (GND), U1.78 (GND), U1.79 (GND), U1.80 (GND), U1.81 (GND), U1.82 (GND), U1.85 (GND), U1.90 (GND), U1.94 (GND), U1.98 (GND), U1.103 (GND); also elsewhere on the board
GPS: U1.67 (GPS); also elsewhere on the board
MAGPIO0: U1.55 (MAGPIO0); also elsewhere on the board
MAGPIO1: U1.54 (MAGPIO1); also elsewhere on the board
MAGPIO2: U1.53 (MAGPIO2); also elsewhere on the board
MIPI_SCLK: U1.58 (MIPI_SCLK); also elsewhere on the board
MIPI_SDATA: U1.59 (MIPI_SDATA); also elsewhere on the board
MIPI_VIO: U1.57 (MIPI_VIO); also elsewhere on the board
P0.00: U1.95 (P0.00); also elsewhere on the board
P0.01: U1.96 (P0.01); also elsewhere on the board
P0.02: U1.97 (P0.02); also elsewhere on the board
P0.03: U1.99 (P0.03); also elsewhere on the board
P0.04: U1.100 (P0.04); also elsewhere on the board
P0.05: U1.2 (P0.05); also elsewhere on the board
P0.06: U1.3 (P0.06); also elsewhere on the board
P0.07: U1.4 (P0.07); also elsewhere on the board
P0.08: U1.15 (P0.08); also elsewhere on the board
P0.09: U1.16 (P0.09); also elsewhere on the board
P0.10: U1.18 (P0.10); also elsewhere on the board
P0.11: U1.19 (P0.11); also elsewhere on the board
P0.12: U1.20 (P0.12); also elsewhere on the board
P0.13: U1.23 (P0.13_AIN0); also elsewhere on the board
P0.14: U1.24 (P0.14_AIN1); also elsewhere on the board
P0.15: U1.25 (P0.15_AIN2); also elsewhere on the board
P0.16: U1.26 (P0.16_AIN3); also elsewhere on the board
P0.17: U1.28 (P0.17_AIN4); also elsewhere on the board
P0.18: U1.29 (P0.18_AIN5); also elsewhere on the board
P0.19: U1.30 (P0.19_AIN6); also elsewhere on the board
P0.20: U1.35 (P0.20_AIN7); also elsewhere on the board
P0.21: U1.37 (P0.21_TRACECLK); also elsewhere on the board
P0.22: U1.38 (P0.22_TRACEDATA0); also elsewhere on the board
P0.23: U1.39 (P0.23_TRACEDATA1); also elsewhere on the board
P0.24: U1.40 (P0.24_TRACEDATA2); also elsewhere on the board
P0.25: U1.42 (P0.25_TRACEDATA3); also elsewhere on the board
P0.26: U1.83 (P0.26); also elsewhere on the board
P0.27: U1.84 (P0.27); also elsewhere on the board
P0.28: U1.86 (P0.28); also elsewhere on the board
P0.29: U1.87 (P0.29); also elsewhere on the board
P0.30: U1.88 (P0.30); also elsewhere on the board
P0.31: U1.89 (P0.31); also elsewhere on the board
SIM_1V8: U1.49 (SIM_1V8); also elsewhere on the board
SIM_CLK: U1.46 (SIM_CLK); also elsewhere on the board
SIM_IO: U1.48 (SIM_IO); also elsewhere on the board
SIM_RST: U1.43 (SIM_RST); also elsewhere on the board
SWDCLK: U1.33 (SWDCLK); also elsewhere on the board
SWDIO: U1.34 (SWDIO); also elsewhere on the board
VDD1: U1.102 (VDD1); also elsewhere on the board
VDD2: U1.22 (VDD2); also elsewhere on the board
nRESET: U1.32 (~RESET); also elsewhere on the board

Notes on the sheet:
A. nRF9161-LACA-R7 (Nordic PS v1.0 Table 55)
SIM_DET (45) MUST FLOAT per PS. RES pins soldered mechanically, electrically NC. GND_Shield tied to VSS pin 103.
nRF9161 PIN POLICY (PS v1.0) RES pins 10,51,70,71,73,104-127: solder for mechanical rigidity, electrically NC SIM_DET pin 45: MUST FLOAT — do not wire (PS: Not used) GND_Shield / VSS: board GND plane DEC0 pin 13: 4.7uF only (PCN134 / nRF91x1)
RES pins NC electrically. SIM_DET pin 45 must float (PS). DEC0=4.7uF.

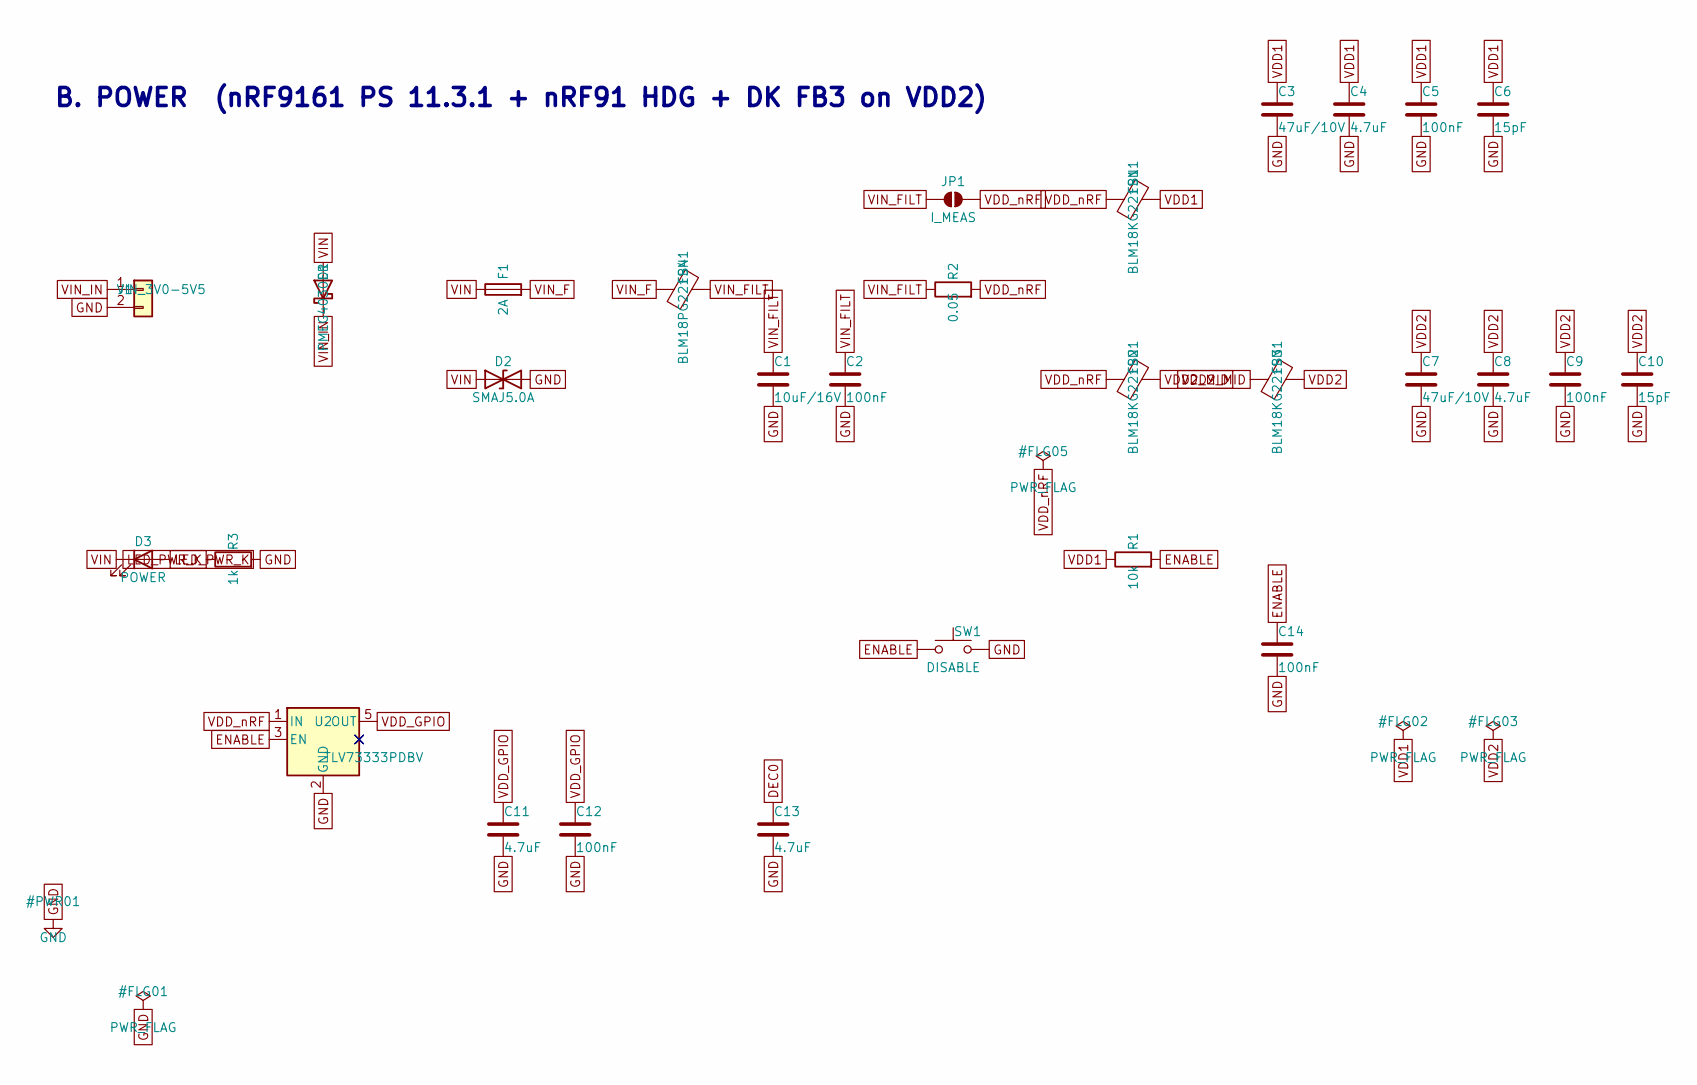
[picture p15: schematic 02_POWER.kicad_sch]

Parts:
C1: 10uF/16V; C_0805_2012Metric
C2: 100nF; C_0402_1005Metric
C3, C7: 47uF/10V; C_0805_2012Metric
C4, C8, C11, C13: 4.7uF; C_0402_1005Metric
C5, C9, C12, C14: 100nF; C_0201_0603Metric
C6, C10: 15pF; C_0201_0603Metric
D1: PMEG4030ER; D_SMA
D2: SMAJ5.0A; D_SMA
D3: POWER; LED_0603_1608Metric
F1: 2A; Fuse_1206_3216Metric
FB1, FB2, FB3: BLM18KG221SN1; L_0603_1608Metric
FB4: BLM18PG221SN1; L_0805_2012Metric
J1: VIN_3V0-5V5; PinHeader_1x02_P2.54mm_Vertical
JP1: I_MEAS; SolderJumper-2_P1.3mm_Open_RoundedPad1.0x1.5mm
R1: 10k; R_0201_0603Metric
R2: 0.05; R_1206_3216Metric
R3: 1k; R_0402_1005Metric
SW1: DISABLE; SW_SPST_CK_KXT3
U2: TLV73333PDBV; SOT-23-5

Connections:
DEC0: C13.1; also elsewhere on the board
ENABLE: C14.1, R1.2, SW1.1, U2.3 (EN); also elsewhere on the board
GND: C1.2, C2.2, C3.2, C4.2, C5.2, C6.2, C7.2, C8.2, C9.2, C10.2, C11.2, C12.2, C13.2, C14.2, D2.2 (A2), J1.2, R3.2, SW1.2, U2.2 (GND); also elsewhere on the board
LED_PWR_K: D3.2 (A), R3.1
VDD1: C3.1, C4.1, C5.1, C6.1, FB1.2, R1.1; also elsewhere on the board
VDD2: C7.1, C8.1, C9.1, C10.1, FB3.2; also elsewhere on the board
VDD2_MID: FB2.2, FB3.1
VIN: D1.2 (A), D2.1 (A1), D3.1 (K), F1.1; also elsewhere on the board
VIN_F: F1.2, FB4.1
VIN_FILT: C1.1, C2.1, FB4.2, JP1.1 (A), R2.1; also elsewhere on the board
VIN_IN: D1.1 (K), J1.1

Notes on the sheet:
B. POWER (nRF9161 PS 11.3.1 + nRF91 HDG + DK FB3 on VDD2)

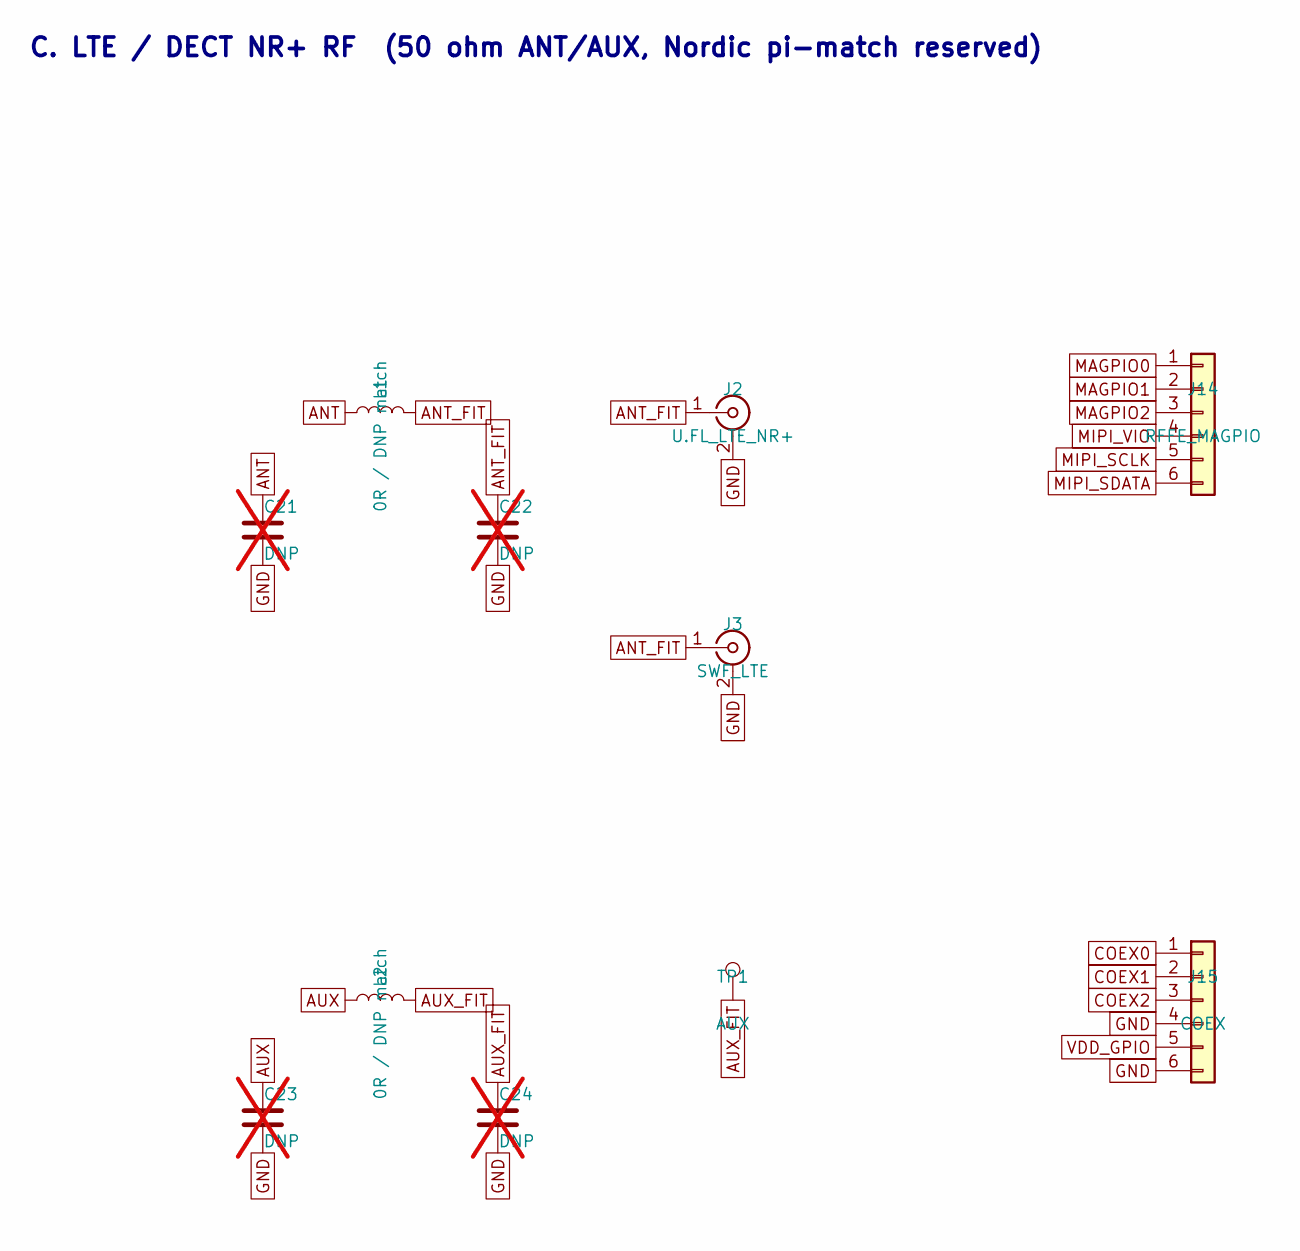
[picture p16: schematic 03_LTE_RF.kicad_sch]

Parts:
C21, C22, C23, C24: DNP; C_0402_1005Metric; not fitted
J2: U.FL_LTE_NR+; U.FL_Hirose_U.FL-R-SMT-1_Vertical
J3: SWF_LTE; Murata_MM8130-2600_SWF
J14: RFFE_MAGPIO; PinHeader_1x06_P1.27mm_Vertical
J15: COEX; PinHeader_1x06_P1.27mm_Vertical
L1, L2: 0R / DNP match; L_0402_1005Metric
TP1: AUX; TestPoint_Pad_D1.5mm

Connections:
ANT: C21.1, L1.1; also elsewhere on the board
ANT_FIT: C22.1, J2.1 (In), J3.1 (In), L1.2
AUX: C23.1, L2.1; also elsewhere on the board
AUX_FIT: C24.1, L2.2, TP1.1
COEX0: J15.1; also elsewhere on the board
COEX1: J15.2; also elsewhere on the board
COEX2: J15.3; also elsewhere on the board
GND: C21.2, C22.2, C23.2, C24.2, J2.2 (Ext), J3.2 (Ext), J15.4, J15.6; also elsewhere on the board
MAGPIO0: J14.1; also elsewhere on the board
MAGPIO1: J14.2; also elsewhere on the board
MAGPIO2: J14.3; also elsewhere on the board
MIPI_SCLK: J14.5; also elsewhere on the board
MIPI_SDATA: J14.6; also elsewhere on the board
MIPI_VIO: J14.4; also elsewhere on the board

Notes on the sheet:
C. LTE / DECT NR+ RF (50 ohm ANT/AUX, Nordic pi-match reserved)

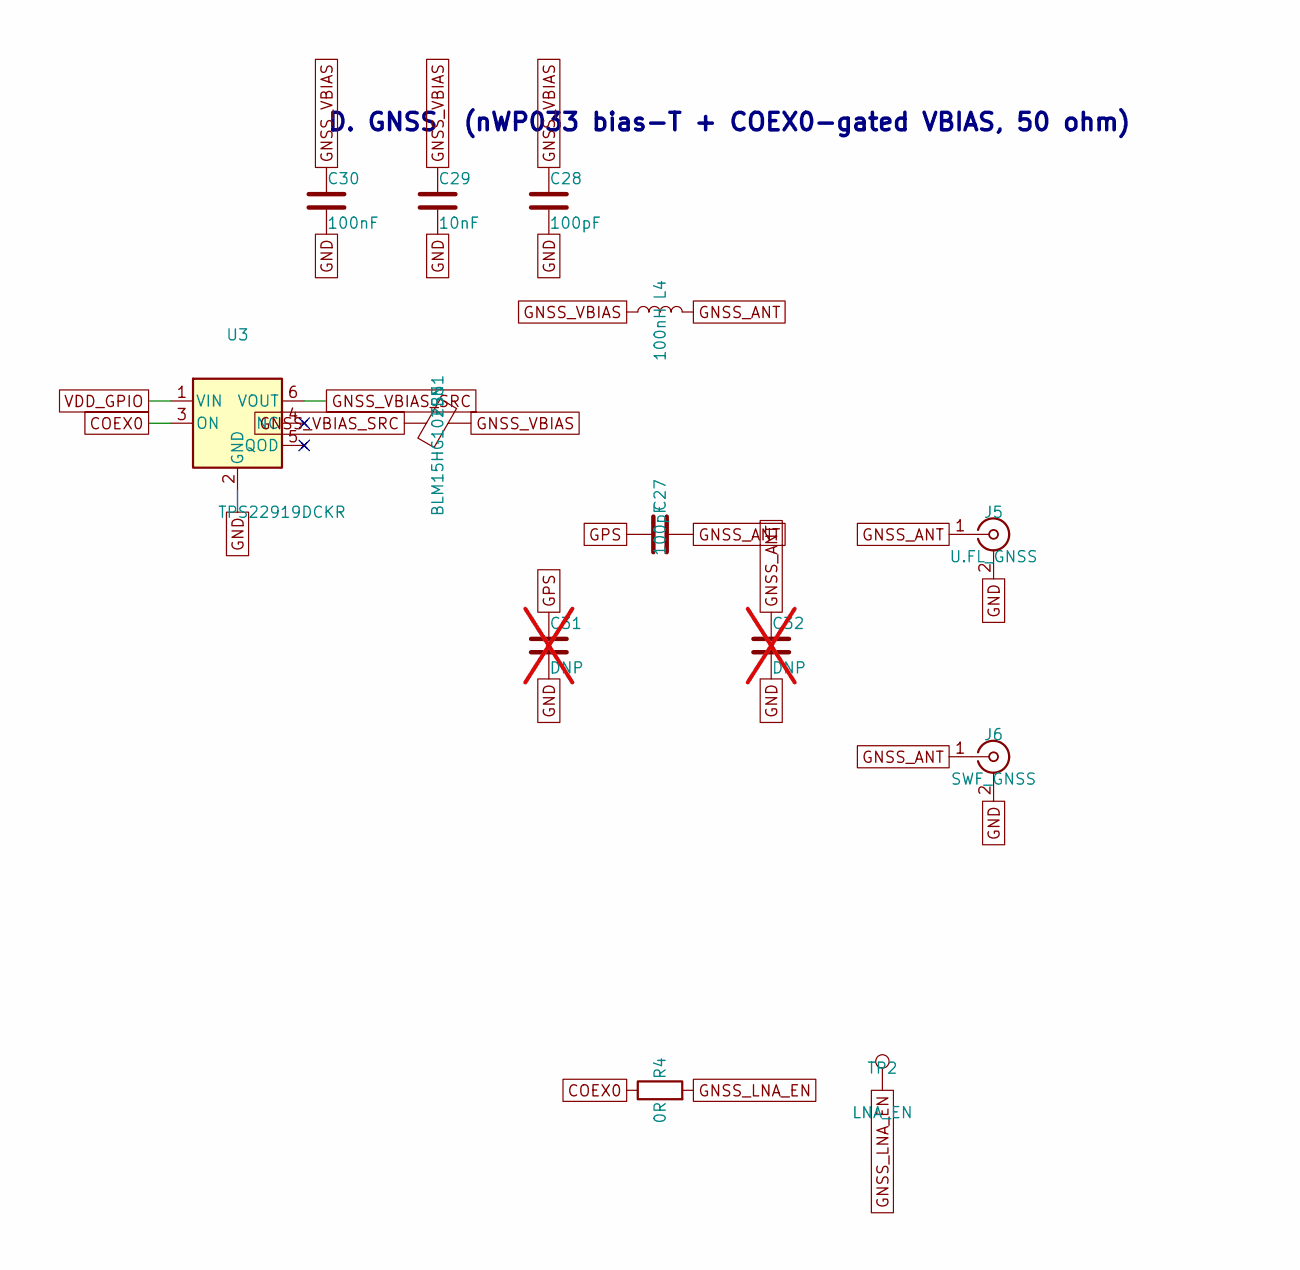
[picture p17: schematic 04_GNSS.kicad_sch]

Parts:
C27: 100pF; C_0201_0603Metric
C28: 100pF; C_0402_1005Metric
C29: 10nF; C_0402_1005Metric
C30: 100nF; C_0402_1005Metric
C31, C32: DNP; C_0402_1005Metric; not fitted
FB5: BLM15HG102SN1; L_0402_1005Metric
J5: U.FL_GNSS; U.FL_Hirose_U.FL-R-SMT-1_Vertical
J6: SWF_GNSS; Murata_MM8130-2600_SWF
L4: 100nH; L_0402_1005Metric
R4: 0R; R_0402_1005Metric
TP2: LNA_EN; TestPoint_Pad_D1.5mm
U3: TPS22919DCKR; SOT-363_SC-70-6

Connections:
COEX0: R4.1, U3.3 (ON); also elsewhere on the board
GND: C28.2, C29.2, C30.2, C31.2, C32.2, J5.2 (Ext), J6.2 (Ext), U3.2 (GND); also elsewhere on the board
GNSS_ANT: C27.2, C32.1, J5.1 (In), J6.1 (In), L4.2
GNSS_LNA_EN: R4.2, TP2.1
GNSS_VBIAS: C28.1, C29.1, C30.1, FB5.2, L4.1
GNSS_VBIAS_SRC: FB5.1, U3.6 (VOUT)
GPS: C27.1, C31.1; also elsewhere on the board

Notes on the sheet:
D. GNSS (nWP033 bias-T + COEX0-gated VBIAS, 50 ohm)

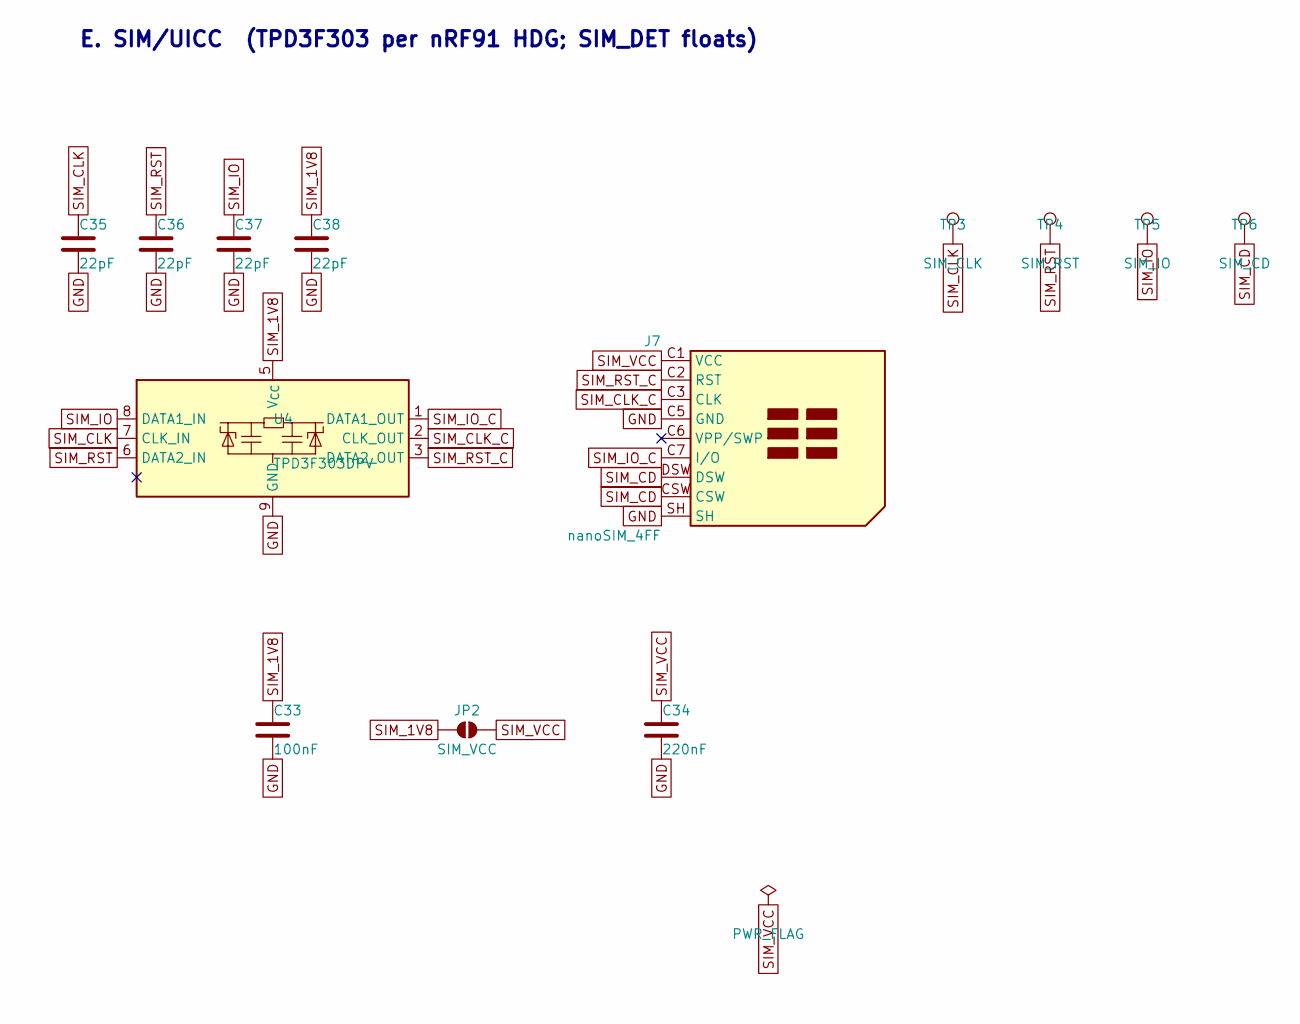
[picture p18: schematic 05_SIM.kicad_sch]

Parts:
C33: 100nF; C_0402_1005Metric
C34: 220nF; C_0402_1005Metric
C35, C36, C37, C38: 22pF; C_0201_0603Metric
J7: nanoSIM_4FF; JAE_SIM_Card_SF72S006
JP2: SIM_VCC; SolderJumper-2_P1.3mm_Open_RoundedPad1.0x1.5mm
TP3: SIM_CLK; TestPoint_Pad_D1.0mm
TP4: SIM_RST; TestPoint_Pad_D1.0mm
TP5: SIM_IO; TestPoint_Pad_D1.0mm
TP6: SIM_CD; TestPoint_Pad_D1.0mm
U4: TPD3F303DPV; TI_TPD3F303_USON-8_1.45x1.45mm_P0.4mm

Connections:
GND: C33.2, C34.2, C35.2, C36.2, C37.2, C38.2, J7.C5 (GND), J7.SH, U4.9 (GND); also elsewhere on the board
SIM_1V8: C33.1, C38.1, JP2.1 (A), U4.5 (V_{CC}); also elsewhere on the board
SIM_CD: J7.CSW, J7.DSW, TP6.1
SIM_CLK: C35.1, TP3.1, U4.7 (CLK_IN); also elsewhere on the board
SIM_CLK_C: J7.C3 (CLK), U4.2 (CLK_OUT)
SIM_IO: C37.1, TP5.1, U4.8 (DATA1_IN); also elsewhere on the board
SIM_IO_C: J7.C7 (I/O), U4.1 (DATA1_OUT)
SIM_RST: C36.1, TP4.1, U4.6 (DATA2_IN); also elsewhere on the board
SIM_RST_C: J7.C2 (RST), U4.3 (DATA2_OUT)
SIM_VCC: C34.1, J7.C1 (VCC), JP2.2 (B)

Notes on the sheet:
E. SIM/UICC (TPD3F303 per nRF91 HDG; SIM_DET floats)

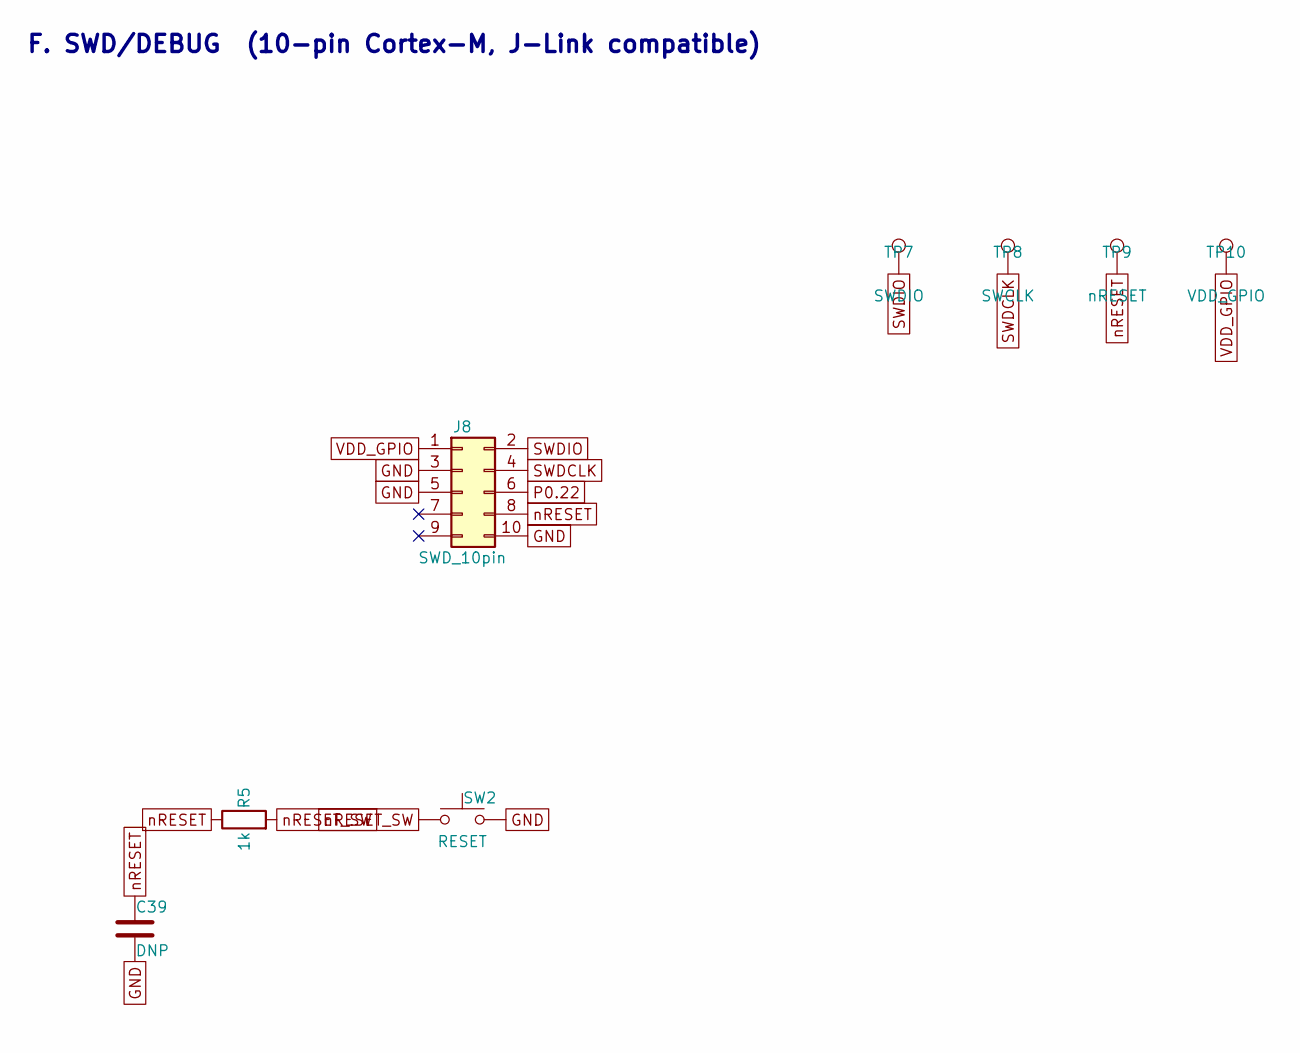
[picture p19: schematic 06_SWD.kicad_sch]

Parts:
C39: DNP; C_0201_0603Metric
J8: SWD_10pin; PinHeader_2x05_P1.27mm_Vertical_SMD
R5: 1k; R_0201_0603Metric
SW2: RESET; SW_SPST_CK_KXT3
TP7: SWDIO; TestPoint_Pad_D1.5mm
TP8: SWCLK; TestPoint_Pad_D1.5mm
TP9: nRESET; TestPoint_Pad_D1.5mm
TP10: VDD_GPIO; TestPoint_Pad_D1.5mm

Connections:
GND: C39.2, J8.3, J8.5, J8.10, SW2.2; also elsewhere on the board
P0.22: J8.6; also elsewhere on the board
SWDCLK: J8.4, TP8.1; also elsewhere on the board
SWDIO: J8.2, TP7.1; also elsewhere on the board
nRESET: C39.1, J8.8, R5.1, TP9.1; also elsewhere on the board
nRESET_SW: R5.2, SW2.1

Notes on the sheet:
F. SWD/DEBUG (10-pin Cortex-M, J-Link compatible)

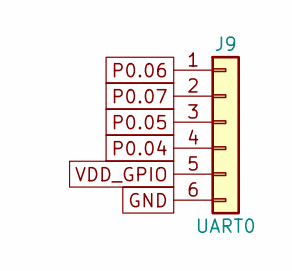
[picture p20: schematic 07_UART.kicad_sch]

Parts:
J9: UART0; PinHeader_1x06_P2.54mm_Vertical

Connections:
GND: J9.6; also elsewhere on the board
P0.04: J9.4; also elsewhere on the board
P0.05: J9.3; also elsewhere on the board
P0.06: J9.1; also elsewhere on the board
P0.07: J9.2; also elsewhere on the board

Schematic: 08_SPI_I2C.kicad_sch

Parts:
J10: SPI0; PinHeader_1x06_P2.54mm_Vertical
J11: I2C0; PinHeader_1x04_P2.54mm_Vertical

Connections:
GND: J10.6, J11.4; also elsewhere on the board
P0.21: J10.1; also elsewhere on the board
P0.22: J10.2; also elsewhere on the board
P0.23: J10.3; also elsewhere on the board
P0.24: J10.4; also elsewhere on the board
P0.30: J11.1; also elsewhere on the board
P0.31: J11.2; also elsewhere on the board

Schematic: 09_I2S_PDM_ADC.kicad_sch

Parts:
J16: I2S; PinHeader_1x06_P2.54mm_Vertical
J17: PDM; PinHeader_1x04_P2.54mm_Vertical
J18: ADC_AIN0-7; PinHeader_1x10_P2.54mm_Vertical

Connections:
GND: J16.6, J17.4, J18.10; also elsewhere on the board
P0.09: J16.4; also elsewhere on the board
P0.10: J16.1; also elsewhere on the board
P0.11: J16.2; also elsewhere on the board
P0.12: J16.3; also elsewhere on the board
P0.13: J18.1; also elsewhere on the board
P0.14: J18.2; also elsewhere on the board
P0.15: J18.3; also elsewhere on the board
P0.16: J18.4; also elsewhere on the board
P0.17: J17.1, J18.5; also elsewhere on the board
P0.18: J17.2, J18.6; also elsewhere on the board
P0.19: J18.7; also elsewhere on the board
P0.20: J18.8; also elsewhere on the board

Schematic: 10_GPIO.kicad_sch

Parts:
J12: GPIO_P0.00-15; PinHeader_1x20_P2.54mm_Vertical
J13: GPIO_P0.16-31; PinHeader_1x20_P2.54mm_Vertical

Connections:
GND: J12.19, J12.20, J13.19, J13.20; also elsewhere on the board
P0.00: J12.1; also elsewhere on the board
P0.01: J12.2; also elsewhere on the board
P0.02: J12.3; also elsewhere on the board
P0.03: J12.4; also elsewhere on the board
P0.04: J12.5; also elsewhere on the board
P0.05: J12.6; also elsewhere on the board
P0.06: J12.7; also elsewhere on the board
P0.07: J12.8; also elsewhere on the board
P0.08: J12.9; also elsewhere on the board
P0.09: J12.10; also elsewhere on the board
P0.10: J12.11; also elsewhere on the board
P0.11: J12.12; also elsewhere on the board
P0.12: J12.13; also elsewhere on the board
P0.13: J12.14; also elsewhere on the board
P0.14: J12.15; also elsewhere on the board
P0.15: J12.16; also elsewhere on the board
P0.16: J13.1; also elsewhere on the board
P0.17: J13.2; also elsewhere on the board
P0.18: J13.3; also elsewhere on the board
P0.19: J13.4; also elsewhere on the board
P0.20: J13.5; also elsewhere on the board
P0.21: J13.6; also elsewhere on the board
P0.22: J13.7; also elsewhere on the board
P0.23: J13.8; also elsewhere on the board
P0.24: J13.9; also elsewhere on the board
P0.25: J13.10; also elsewhere on the board
P0.26: J13.11; also elsewhere on the board
P0.27: J13.12; also elsewhere on the board
P0.28: J13.13; also elsewhere on the board
P0.29: J13.14; also elsewhere on the board
P0.30: J13.15; also elsewhere on the board
P0.31: J13.16; also elsewhere on the board

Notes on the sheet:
GPIO / INTERFACE MAP (nRF9161 PS Table 55). All 32 GPIOs on J12/J13. P0.00-P0.03 LED1-4 (open-drain OK; still on headers) P0.04 UART_CTS P0.05 UART_RTS P0.06 UART_TX P0.07 UART_RX (J9 default) P0.08 USER button (SW3, 10k to VDD_GPIO) P0.09 I2S_SDIN P0.10 I2S_SCK P0.11 I2S_LRCK P0.12 I2S_SDOUT (J16)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
GPIO / INTERFACE MAP (nRF9161 PS Table 55) P0.00 pin95 J12 LED1 D4 P0.01 pin96 J12 LED2 D5 P0.02 pin97 J12 LED3 D6 P0.03 pin99 J12 LED4 D7 P0.04 pin100 UART CTS J9 P0.05 pin2 UART RTS J9 P0.06 pin3 UART TX J9 P0.07 pin4 UART RX J9 P0.08 pin15 J12 USER SW3 P0.09 pin16 I2S SDIN J16 P0.10 pin18 I2S SC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

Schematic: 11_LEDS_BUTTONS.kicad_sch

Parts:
D4: STATUS; LED_0603_1608Metric
D5: LTE; LED_0603_1608Metric
D6: GNSS; LED_0603_1608Metric
D7: SPARE_DNP; LED_0603_1608Metric
R10, R11, R12, R13: 1k; R_0402_1005Metric
R14: 10k; R_0402_1005Metric
SW3: USER; SW_SPST_CK_KXT3

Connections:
GND: D4.2 (A), D5.2 (A), D6.2 (A), D7.2 (A), SW3.2; also elsewhere on the board
LED1_A: D4.1 (K), R10.2
LED2_A: D5.1 (K), R11.2
LED3_A: D6.1 (K), R12.2
LED4_A: D7.1 (K), R13.2
P0.00: R10.1; also elsewhere on the board
P0.01: R11.1; also elsewhere on the board
P0.02: R12.1; also elsewhere on the board
P0.03: R13.1; also elsewhere on the board
P0.08: R14.1, SW3.1; also elsewhere on the board

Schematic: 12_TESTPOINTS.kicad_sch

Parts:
TP11: VDD1; TestPoint_Pad_D1.5mm
TP12: VDD2; TestPoint_Pad_D1.5mm
TP13: VDD_GPIO; TestPoint_Pad_D1.5mm
TP14: VDD_nRF; TestPoint_Pad_D1.5mm
TP15: VIN; TestPoint_Pad_D1.5mm
TP16: GND; TestPoint_Pad_D1.5mm
TP17: ENABLE; TestPoint_Pad_D1.5mm
TP18: DEC0; TestPoint_Pad_D1.5mm
TP19: I_MEAS+; TestPoint_Pad_D1.5mm
TP20: I_MEAS-; TestPoint_Pad_D1.5mm

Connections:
DEC0: TP18.1; also elsewhere on the board
ENABLE: TP17.1; also elsewhere on the board
GND: TP16.1; also elsewhere on the board
VDD1: TP11.1; also elsewhere on the board
VDD2: TP12.1; also elsewhere on the board
VIN: TP15.1; also elsewhere on the board
VIN_FILT: TP19.1; also elsewhere on the board

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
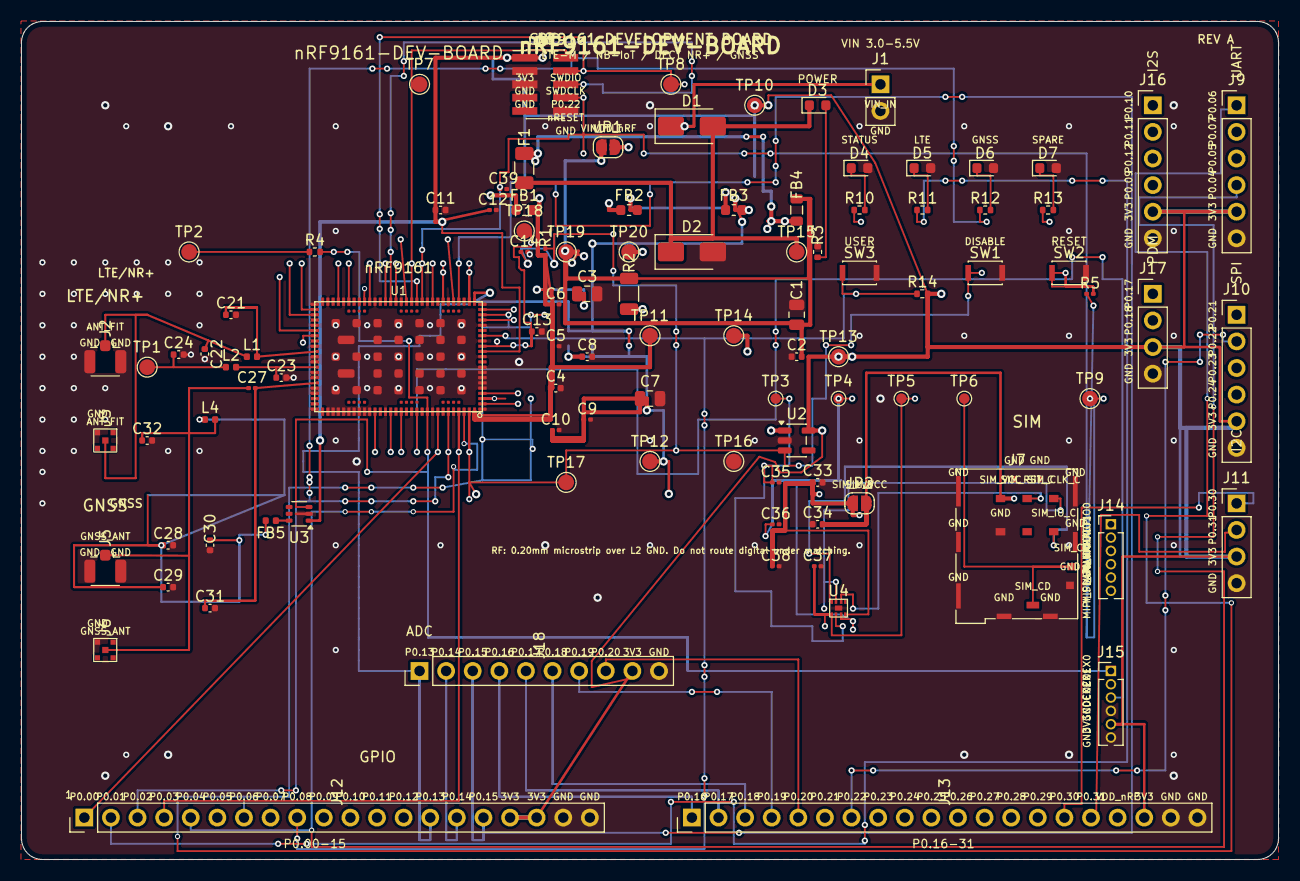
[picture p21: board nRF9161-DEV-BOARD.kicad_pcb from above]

Board: 4 copper layers, 120.0 x 80.0 mm, 103 parts (0 on the bottom side), 80 nets.

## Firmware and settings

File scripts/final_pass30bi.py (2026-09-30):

#!/usr/bin/env python3
"""pass30bi — ONE attempt: P0.05 U1.2 to J12.6 only.

Named through-via (47.40, 36.50) is on the U1.2 island (net P0.05).
J12.6 is a PTH pad, copper on F/In1/In2/B. No new via.

In1.Cu, 7 segments. South of the P0.07 y=37.90 run, through the J18.8/J18.9
gap, west north of the J12 row (y=74.70, north of the P0.07 x=25.20 wall),
south through the J12.7/J12.8 gap (west of that wall), then west and north
onto J12.6 from the south. Does not use the P0.07 centerline, the skirt
slot, the sealed pocket, or the RF keepout. Straight F.Cu chord is not used.
"""
from __future__ import annotations

import hashlib
import importlib.util
import json
import math
import shutil
from pathlib import Path

import pcbnew

ROOT = Path("/workspace/kicad-projects/nRF9161-DEV-BOARD")
spec = importlib.util.spec_from_file_location("p30ba", ROOT / "scripts" / "final_pass30ba.py")
m = importlib.util.module_from_spec(spec)
spec.loader.exec_module(m)
spec2 = importlib.util.spec_from_file_location("p30be", ROOT / "scripts" / "final_pass30be.py")
be = importlib.util.module_from_spec(spec2)
spec2.loader.exec_module(be)

BOARD = m.BOARD
BACKUP = ROOT / ".mcp-backups/pass30bi/pre-edit.kicad_pcb"
REPORTS = m.REPORTS
REVIEW = m.REVIEW
F, B, IN1, IN2 = m.F, m.B, m.IN1, m.IN2
W = m.W
CF = m.CF
CP = m.CP
LAYERS = m.LAYERS
NET = "P0.05"
be.NET = NET
EXPECTED_HEAD = "99ff66c"
EXPECTED_BLOB = "953e98bc52f2b39ffec50928389f4492eff69ce7"
EXPECTED_UNC = 52
CENSUS_PAD_EDGE = 45.733

START_VIA_NM = (47400000, 36500000)
PAD_NM = (18700000, 76000000)

POLY = [
    (47.40, 36.50),
    (47.40, 38.40),
    (57.05, 38.40),
    (57.05, 74.70),
    (22.51, 74.70),
    (22.51, 79.40),
    (18.70, 79.40),
    (18.70, 76.00),
]

P007 = [
    (47.40, 35.50), (48.05, 35.50), (48.05, 37.90), (63.10, 37.90),
    (63.10, 70.00), (62.70, 70.00), (62.70, 79.20), (25.20, 79.20),
    (25.20, 76.00), (23.78, 76.00),
]
P000 = [
    (39.75, 41.10), (39.75, 37.40), (25.20, 37.40), (25.20, 23.50),
    (25.00, 23.50), (25.00, 15.20), (68.70, 15.20), (68.70, 16.40),
    (80.14, 16.40), (80.14, 19.125833),
]
SIM_RST = [
    (32.71, 26.40), (32.75, 25.50), (26.20, 25.50), (26.20, 17.60),
    (55.30, 17.60), (55.30, 18.50), (68.00, 18.50), (68.00, 35.40),
    (78.00, 35.40), (78.00, 36.00),
]
be.LOCKED = list(be.LOCKED) + [
    ("P0.07", "In2.Cu", P007),
    ("P0.00", "In1.Cu", P000),
    ("SIM_RST", "In1.Cu", SIM_RST),
]


def poly_xy():
    return [(p[0], p[1]) for p in POLY]


def crossing_test(pts):
    skirt = be.whole_segment_crossing_test(pts)
    skirt["method"] = (
        "segment-vs-segment interior intersection plus 0.05 mm samples, "
        "against P0.16, P0.17, P0.19, P0.20, the SIM_CLK In1 run, the "
        "SIM_RST run (F.Cu neck plus In1), the P0.00 In1 run, and the "
        "P0.07 In2 run. Layers are not exempt. A same-centerline stack on "
        "x=44.25, x=44.60, the y=63.20 eastbounds, or any locked P0.07 "
        "centerline is a fail. Endpoint-only touches are not crossings."
    )
    return skirt


def route_box(x1, y1, x2, y2):
    """RF keepout is the box x<=24.2 and y in [20, 64], not every x<=24.2.
    Also the SiP body and the sealed B.Cu pocket. Board-edge copper clearance
    is 0.50 mm to the Edge.Cuts line at y=80.0."""
    length = math.hypot(x2 - x1, y2 - y1)
    n = max(2, int(length / 0.02))
    for i in range(n + 1):
        t = i / n
        x = x1 + (x2 - x1) * t
        y = y1 + (y2 - y1) * t
        if x <= 24.2 + 1e-9 and 20.0 <= y <= 64.0:
            return "rf_keepout"
        if 28.0 <= x <= 44.0 and 26.75 <= y <= 37.25:
            return "sip_body"
        if 81.8 <= x <= 97.3 and abs(y - 44.60) <= (W / 2 + 0.15):
            return "sealed_pocket"
        if y + (W / 2) > 80.0 - 0.5 + 1e-9:
            return "board_edge"
        if x - (W / 2) < 0.0 + 0.5 - 1e-9:
            return "board_edge"
    return None


def seg_clearance(board, x1, y1, x2, y2):
    row = be.shape_clearance(board, IN1, x1, y1, x2, y2)
    box = route_box(x1, y1, x2, y2)
    foreign_ok = row["foreign"] is None or row["foreign_exact"] >= CF - 1e-9
    power_ok = row["power"] is None or row["power_exact"] >= CP - 1e-9
    hole_ok = row["hole"] is None or row["hole"] >= m.HOLE - 1e-9
    row["body"] = box is not None
    row["why"] = box
    row["ok"] = foreign_ok and power_ok and hole_ok and box is None
    row["start"] = [x1, y1]
    row["end"] = [x2, y2]
    row["layer"] = "In1.Cu"
    return row


def shp_of(it, lid):
    if it["kind"] == "pad":
        return it["obj"].GetEffectiveShape(lid)
    if it["kind"] == "via":
        return pcbnew.SHAPE_CIRCLE(
            m.xy(it["x"], it["y"]),
            pcbnew.FromMM(m.mm(it["obj"].GetWidth(lid)) / 2),
        )
    return pcbnew.SHAPE_SEGMENT(it["obj"].GetStart(), it["obj"].GetEnd(), it["obj"].GetWidth())


def islands(board) -> dict:
    items = []
    for fp in board.GetFootprints():
        for p in fp.Pads():
            if p.GetNetname() != NET:
                continue
            layers = [lid for _, lid in LAYERS if p.IsOnLayer(lid)]
            items.append({
                "kind": "pad",
                "name": f"{fp.GetReference()}.{p.GetNumber()}",
                "x": m.mm(p.GetPosition().x),
                "y": m.mm(p.GetPosition().y),
                "layers": layers,
                "obj": p,
                "nm": (p.GetPosition().x, p.GetPosition().y),
                "size": [m.mm(p.GetSize().x), m.mm(p.GetSize().y)],
                "drill": m.mm(p.GetDrillSize().x),
            })
    for t in board.GetTracks():
        if t.GetNetname() != NET:
            continue
        if t.GetClass() == "PCB_VIA":
            layers = [lid for _, lid in LAYERS if t.IsOnLayer(lid)]
            items.append({
                "kind": "via",
                "name": f"via@{m.mm(t.GetPosition().x):.3f},{m.mm(t.GetPosition().y):.3f}",
                "x": m.mm(t.GetPosition().x),
                "y": m.mm(t.GetPosition().y),
                "layers": layers,
                "obj": t,
                "drill": m.mm(t.GetDrillValue()),
                "width": m.mm(t.GetWidth(F)),
                "through": (
                    board.GetLayerName(t.TopLayer()) == "F.Cu"
                    and board.GetLayerName(t.BottomLayer()) == "B.Cu"
                ),
                "nm": (t.GetPosition().x, t.GetPosition().y),
            })
        else:
            items.append({
                "kind": "trk",
                "name": (
                    f"{board.GetLayerName(t.GetLayer())} "
                    f"({m.mm(t.GetStart().x):.3f},{m.mm(t.GetStart().y):.3f})-"
                    f"({m.mm(t.GetEnd().x):.3f},{m.mm(t.GetEnd().y):.3f})"
                ),
                "x": (m.mm(t.GetStart().x) + m.mm(t.GetEnd().x)) / 2,
                "y": (m.mm(t.GetStart().y) + m.mm(t.GetEnd().y)) / 2,
                "layers": [t.GetLayer()],
                "obj": t,
            })

    def touches(i, j) -> bool:
        for lid in set(items[i]["layers"]) & set(items[j]["layers"]):
            if m.mm(shp_of(items[i], lid).GetClearance(shp_of(items[j], lid))) <= 0.001:
                return True
        return False

    parent = list(range(len(items)))

    def find(a):
        while parent[a] != a:
            parent[a] = parent[parent[a]]
            a = parent[a]
        return a

    def union(a, c):
        ra, rb = find(a), find(c)
        if ra != rb:
            parent[rb] = ra

    for i in range(len(items)):
        for j in range(i + 1, len(items)):
            if touches(i, j):
                union(i, j)

    u1 = next(i for i, it in enumerate(items) if it["name"] == "U1.2")
    far_i = next(i for i, it in enumerate(items) if it["name"] == "J12.6")
    start_i = next(i for i, it in enumerate(items) if it.get("nm") == START_VIA_NM)

    def names(root_idx):
        return [items[i]["name"] for i in range(len(items)) if find(i) == find(root_idx)]

    def layer_names(root_idx):
        lids = set()
        for i in range(len(items)):
            if find(i) == find(root_idx):
                lids.update(items[i]["layers"])
        return [name for name, lid in LAYERS if lid in lids]

    other = []
    for i, it in enumerate(items):
        if it["kind"] != "pad":
            continue
        if it["name"] in ("U1.2", "J12.6"):
            continue
        other.append({
            "name": it["name"],
            "xy": [it["x"], it["y"]],
            "island": names(i),
            "same_as_u1": find(i) == find(u1),
            "same_as_j12": find(i) == find(far_i),
        })

    u = items[u1]["obj"]
    far = items[far_i]["obj"]
    gap = m.mm(u.GetEffectiveShape(F).GetClearance(far.GetEffectiveShape(F)))
    sv = items[start_i]
    far_layers = [name for name, lid in LAYERS if far.IsOnLayer(lid)]
    return {
        "same_island": find(u1) == find(far_i),
        "pad_edge_mm": round(gap, 3),
        "pad_edge_exact_mm": gap,
        "u1_island": names(u1),
        "u1_island_layers": layer_names(u1),
        "far_island": names(far_i),
        "far_island_layers": layer_names(far_i),
        "far_pad_layers_all_copper": far_layers,
        "far_pad_xy": [items[far_i]["x"], items[far_i]["y"]],
        "far_pad_nm": list(items[far_i]["nm"]),
        "far_pad_size_mm": items[far_i]["size"],
        "far_pad_drill_mm": items[far_i]["drill"],
        "far_fcu_only": far_layers == ["F.Cu"],
        "j12_has_in1": far.IsOnLayer(IN1),
        "start_via_on_u1": find(start_i) == find(u1),
        "start_via": {
            "xy": [sv["x"], sv["y"]],
            "width_mm": sv["width"],
            "radius_mm": sv["width"] / 2,
            "drill_mm": sv["drill"],
            "through": sv["through"],
            "nm": list(sv["nm"]),
            "net": NET,
        },
        "other_p005_pads": other,
    }


def straight_chord(board) -> dict:
    ax, ay = 43.622, 36.647
    bx, by = 19.101, 75.250
    via = None
    for t in board.GetTracks():
        if t.GetClass() != "PCB_VIA" or t.GetNetname() != "P0.02":
            continue
        x, y = m.mm(t.GetPosition().x), m.mm(t.GetPosition().y)
        if abs(x - 40.75) > 0.02 or abs(y - 41.1) > 0.02:
            continue
        dist = m.dps(x, y, ax, ay, bx, by)
        edge = dist - m.mm(t.GetWidth(F)) / 2 - (W / 2)
        via = {
            "xy": [x, y],
            "width_mm": m.mm(t.GetWidth(F)),
            "center_distance_mm": dist,
            "edge_clearance_mm": edge,
        }
        break
    return {
        "from_existing_copper": [ax, ay],
        "to_pad_edge_point": [bx, by],
        "width_mm": W,
        "layer": "F.Cu",
        "length_mm": round(math.hypot(bx - ax, by - ay), 6),
        "crosses_sip_body": m.crosses_body(ax, ay, bx, by),
        "p002": via,
        "used": False,
        "note": "Straight F.Cu chord hits P0.02 via (40.75, 41.10). Not used.",
    }


def measure(board):
    rows = []
    mf = mp = mh = None
    for i in range(len(POLY) - 1):
        x1, y1 = POLY[i]
        x2, y2 = POLY[i + 1]
        row = seg_clearance(board, x1, y1, x2, y2)
        rows.append(row)
        if row.get("foreign_exact") is not None and (mf is None or row["foreign_exact"] < mf[0]):
            mf = (row["foreign_exact"], row["foreign_item"])
        if row.get("power_exact") is not None and (mp is None or row["power_exact"] < mp[0]):
            mp = (row["power_exact"], row["power_item"])
        if row.get("hole") is not None and (mh is None or row["hole"] < mh[0]):
            mh = (row["hole"], row["hole_item"])
    pad = None
    for fp in board.GetFootprints():
        if fp.GetReference() != "J12":
            continue
        for p in fp.Pads():
            if p.GetNumber() == "6":
                pad = p
    land = pcbnew.SHAPE_SEGMENT(m.xy(*POLY[-2]), m.xy(*POLY[-1]), pcbnew.FromMM(W))
    hits = bool(pad is not None and land.Collide(pad.GetEffectiveShape(IN1)))
    nseg = len(POLY) - 1
    ok = (
        all(r["ok"] for r in rows)
        and hits
        and nseg <= 10
        and (mf is None or mf[0] >= CF - 1e-9)
        and (mp is None or mp[0] >= CP - 1e-9)
        and (mh is None or mh[0] >= m.HOLE - 1e-9)
    )
    return {
        "segments": rows,
        "segment_count": nseg,
        "min_clearance_mm": None if mf is None else round(mf[0], 4),
        "min_clearance_exact": None if mf is None else mf[0],
        "min_clearance_item": None if mf is None else mf[1],
        "min_power_vin_mm": None if mp is None else round(mp[0], 4),
        "min_power_exact": None if mp is None else mp[0],
        "min_power_vin_item": None if mp is None else mp[1],
        "min_hole_mm": None if mh is None else mh[0],
        "min_hole_item": None if mh is None else mh[1],
        "lands_on_j12_6": hits,
        "new_via": None,
        "ok": ok,
        "meets_foreign_0_15": mf is None or mf[0] >= CF - 1e-9,
        "meets_power_0_20": mp is None or mp[0] >= CP - 1e-9,
        "width_mm": W,
    }


def add_route(board):
    net = board.FindNet(NET)
    if net is None:
        raise SystemExit("P0.05 missing")
    for i in range(len(POLY) - 1):
        x1, y1 = POLY[i]
        x2, y2 = POLY[i + 1]
        tr = pcbnew.PCB_TRACK(board)
        if i == 0:
            tr.SetStart(pcbnew.VECTOR2I(START_VIA_NM[0], START_VIA_NM[1]))
        else:
            tr.SetStart(m.xy(x1, y1))
        if i == len(POLY) - 2:
            tr.SetEnd(pcbnew.VECTOR2I(PAD_NM[0], PAD_NM[1]))
        else:
            tr.SetEnd(m.xy(x2, y2))
        tr.SetWidth(pcbnew.FromMM(W))
        tr.SetLayer(IN1)
        tr.SetNet(net)
        board.Add(tr)


def protect_ok(board) -> dict:
    return {
        "p016": m.poly_ok(board, be.P16, "P0.16", IN1),
        "p017": m.poly_ok(board, be.P17, "P0.17", IN2),
        "p019": m.poly_ok(board, be.P19, "P0.19", IN1),
        "p020": m.poly_ok(board, be.P20, "P0.20", IN2),
        "sim_clk": m.poly_ok(board, be.SIM, "SIM_CLK", IN1),
        "sim_rst_in1": m.poly_ok(board, SIM_RST[1:], "SIM_RST", IN1),
        "sim_rst_neck": m.poly_ok(board, SIM_RST[:2], "SIM_RST", F),
        "sim_rst_via": m.via_at(board, "SIM_RST", 32.75, 25.50),
        "p000": m.poly_ok(board, P000, "P0.00", IN1),
        "p007": m.poly_ok(board, P007, "P0.07", IN2),
        "p007_via": m.via_at(board, "P0.07", 47.40, 35.50),
    }


def j9_2_state(board) -> dict:
    for fp in board.GetFootprints():
        if fp.GetReference() != "J9":
            continue
        for p in fp.Pads():
            if p.GetNumber() == "2":
                return {
                    "xy": [m.mm(p.GetPosition().x), m.mm(p.GetPosition().y)],
                    "net": p.GetNetname(),
                    "fp_xy": [m.mm(fp.GetPosition().x), m.mm(fp.GetPosition().y)],
                }
    return {"missing": True}


def counts_locked(before_counts, board):
    after = m.track_counts(board)
    bad = []
    for net, n in before_counts["tracks"].items():
        if net == NET:
            continue
        if after["tracks"].get(net, 0) != n:
            bad.append(f"track {net} {n}->{after['tracks'].get(net, 0)}")
    for net, n in before_counts["vias"].items():
        if after["vias"].get(net, 0) != n:
            bad.append(f"via {net} {n}->{after['vias'].get(net, 0)}")
    if after["vias"].get(NET, 0) != before_counts["vias"].get(NET, 0):
        bad.append(f"P0.05 vias changed {before_counts['vias'].get(NET, 0)}->{after['vias'].get(NET, 0)}")
    expect = before_counts["tracks"].get(NET, 0) + (len(POLY) - 1)
    if after["tracks"].get(NET, 0) != expect:
        bad.append(f"P0.05 tracks {before_counts['tracks'].get(NET, 0)}->{after['tracks'].get(NET, 0)} expected {expect}")
    return bad


def gained(before: dict, after: dict) -> dict:
    out = {}
    for k in set(before) | set(after):
        if k == NET:
            continue
        if after.get(k, 0) > before.get(k, 0):
            out[k] = [before.get(k, 0), after.get(k, 0)]
    return out


def enrich(res):
    res["stats"]["p005_unconnected"] = res["stats"]["nongnd"].get(NET, 0)
    return res


def restore():
    shutil.copy2(BACKUP, BOARD)
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

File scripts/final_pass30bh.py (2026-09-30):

#!/usr/bin/env python3
"""pass30bh — ONE attempt: leftover P0.07 only.

The closed island already joins U1.4 and J12.8 on the locked In2 run.
This pass names the leftover pad and measures pad-edge clearance to that
island with the same GetClearance method as the P0.17 leftover (pass30az).
If the gap is over 36 mm it does not route, does not add a via, and does
not write copper. DRC is kicad-cli JSON via final_pass30ba.run_drc, the
same gate as pass30bg. P0.05 is not routed.
"""
from __future__ import annotations

import importlib.util
import json
import math
import shutil
from pathlib import Path

import pcbnew

ROOT = Path("/workspace/kicad-projects/nRF9161-DEV-BOARD")
spec = importlib.util.spec_from_file_location("p30bg", ROOT / "scripts" / "final_pass30bg.py")
bg = importlib.util.module_from_spec(spec)
spec.loader.exec_module(bg)
m = bg.m

BOARD = m.BOARD
REPORTS = m.REPORTS
REVIEW = m.REVIEW
NET = "P0.07"
LIMIT = 36.0
EXPECTED_HEAD = "bed9dc7"
EXPECTED_BLOB = "953e98bc52f2b39ffec50928389f4492eff69ce7"
EXPECTED_UNC = 52
EXPECTED_OPENS = 1
W = m.W

# Locked In2 corner of the closed U1.4/J12.8 run. Not a route.
CORNER = (63.10, 37.90)


def r6(v: float) -> float:
    return round(v, 6)


def collect(board):
    items = []
    for fp in board.GetFootprints():
        for p in fp.Pads():
            if p.GetNetname() != NET:
                continue
            layers = [lid for _, lid in m.LAYERS if p.IsOnLayer(lid)]
            items.append({
                "kind": "pad",
                "name": f"{fp.GetReference()}.{p.GetNumber()}",
                "ref": fp.GetReference(),
                "num": p.GetNumber(),
                "x": m.mm(p.GetPosition().x),
                "y": m.mm(p.GetPosition().y),
                "sx": m.mm(p.GetSize().x),
                "sy": m.mm(p.GetSize().y),
                "drill": m.mm(p.GetDrillSizeX()),
                "shape": int(p.GetShape()),
                "layers": layers,
                "layer_names": [board.GetLayerName(lid) for lid in layers],
                "obj": p,
            })
    for t in board.GetTracks():
        if t.GetNetname() != NET:
            continue
        if t.GetClass() == "PCB_VIA":
            layers = [lid for _, lid in m.LAYERS if t.IsOnLayer(lid)]
            items.append({
                "kind": "via",
                "name": f"via@{m.mm(t.GetPosition().x):.3f},{m.mm(t.GetPosition().y):.3f}",
                "x": m.mm(t.GetPosition().x),
                "y": m.mm(t.GetPosition().y),
                "layers": layers,
                "layer_names": [board.GetLayerName(lid) for lid in layers],
                "obj": t,
                "w": m.mm(t.GetWidth(m.F)),
            })
        else:
            items.append({
                "kind": "trk",
                "name": (
                    f"{board.GetLayerName(t.GetLayer())} "
                    f"({m.mm(t.GetStart().x):.3f},{m.mm(t.GetStart().y):.3f})-"
                    f"({m.mm(t.GetEnd().x):.3f},{m.mm(t.GetEnd().y):.3f})"
                ),
                "x": (m.mm(t.GetStart().x) + m.mm(t.GetEnd().x)) / 2,
                "y": (m.mm(t.GetStart().y) + m.mm(t.GetEnd().y)) / 2,
                "layers": [t.GetLayer()],
                "layer_names": [board.GetLayerName(t.GetLayer())],
                "obj": t,
                "a": (m.mm(t.GetStart().x), m.mm(t.GetStart().y)),
                "b": (m.mm(t.GetEnd().x), m.mm(t.GetEnd().y)),
                "w": m.mm(t.GetWidth()),
            })
    return items


def shp(it, lid):
    if it["kind"] == "pad":
        return it["obj"].GetEffectiveShape(lid)
    if it["kind"] == "via":
        return pcbnew.SHAPE_CIRCLE(
            m.xy(it["x"], it["y"]),
            pcbnew.FromMM(m.mm(it["obj"].GetWidth(lid)) / 2),
        )
    return pcbnew.SHAPE_SEGMENT(it["obj"].GetStart(), it["obj"].GetEnd(), it["obj"].GetWidth())


def touches(items, i, j) -> bool:
    for lid in set(items[i]["layers"]) & set(items[j]["layers"]):
        if m.mm(shp(items[i], lid).GetClearance(shp(items[j], lid))) <= 0.001:
            return True
    return False


def measure_gap(board) -> dict:
    items = collect(board)
    parent = list(range(len(items)))

    def find(a):
        while parent[a] != a:
            parent[a] = parent[parent[a]]
            a = parent[a]
        return a

    def union(a, c):
        ra, rb = find(a), find(c)
        if ra != rb:
            parent[rb] = ra

    for i in range(len(items)):
        for j in range(i + 1, len(items)):
            if touches(items, i, j):
                union(i, j)

    u1 = next(i for i, it in enumerate(items) if it["name"] == "U1.4")
    j12 = next(i for i, it in enumerate(items) if it["name"] == "J12.8")
    if find(u1) != find(j12):
        raise SystemExit("STOP: U1.4 and J12.8 are not one island")
    pads_off = [
        i for i, it in enumerate(items)
        if it["kind"] == "pad" and find(i) != find(u1)
    ]
    if len(pads_off) != 1:
        raise SystemExit(f"STOP: expected one leftover P0.07 pad, found {len(pads_off)}")
    left = pads_off[0]
    best = None
    ties = []
    for name, lid in m.LAYERS:
        jsh = shp(items[left], lid)
        for i, it in enumerate(items):
            if find(i) != find(u1) or lid not in it["layers"]:
                continue
            c = m.mm(jsh.GetClearance(shp(it, lid)))
            rec = {"clearance_mm": c, "layer": name, "item": it["name"], "kind": it["kind"]}
            if best is None or c < best["clearance_mm"] - 1e-9:
                best = rec
                ties = [rec]
            elif abs(c - best["clearance_mm"]) <= 1e-9:
                ties.append(rec)
    pad = items[left]
    # Circular PTH: nearest copper is along the line from the pad center to
    # the locked In2 corner (63.10, 37.90), which is the shared round cap of
    # the two winning segments.
    dx = pad["x"] - CORNER[0]
    dy = pad["y"] - CORNER[1]
    length_c = math.hypot(dx, dy)
    ux, uy = dx / length_c, dy / length_c
    pr = pad["sx"] / 2
    tr = W / 2
    p_pad = (pad["x"] - ux * pr, pad["y"] - uy * pr)
    p_trk = (CORNER[0] + ux * tr, CORNER[1] + uy * tr)
    chord = math.hypot(p_pad[0] - p_trk[0], p_pad[1] - p_trk[1])
    if abs(chord - best["clearance_mm"]) > 0.002:
        raise SystemExit(
            f"nearest-point chord {chord} != GetClearance {best['clearance_mm']}"
        )
    island_names = [items[i]["name"] for i in range(len(items)) if find(i) == find(u1)]
    return {
        "pad": pad,
        "gap_mm": best["clearance_mm"],
        "gap_layer": best["layer"],
        "near_item": best["item"],
        "ties": ties,
        "p_pad": p_pad,
        "p_track": p_trk,
        "center_distance_mm": length_c,
        "island_names": island_names,
        "same_closed_island": True,
    }
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

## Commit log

2026-09-23 Initial commit: nRF9161 development board
    [01_nRF9161.kicad_sch, 02_POWER.kicad_sch, 03_LTE_RF.kicad_sch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]
2026-09-23 Schematic: GNSS COEX0 bias switch, 3.3V VDD_GPIO, DNP RF shunts
    - Add U3 TPS22919DCKR on 04_GNSS (COEX0-gated bias); FB5 0402
    - Swap U2 to TLV73333 (3.3 V VDD_GPIO); DNP Class-C shunt caps
    - Quarantine leftover schematics/; remove stale ERC rpt
    - Add PM/DFM/RF/schematic/layout review docs under docs/
    [02_POWER.kicad_sch, 03_LTE_RF.kicad_sch, 04_GNSS.kicad_sch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]
2026-09-23 PCB pass30: place U3 GNSS bias switch, close bias nets
    Partial connect pass: U3 TPS22919 east of RF keepout, FB5 0402,
    GNSS bias path closed; U3 VIN/COEX0 and Class F still open.
    Clearance cleaned; unconnected ~80. No Gerbers.
    [nRF9161-DEV-BOARD.kicad_pcb]
2026-09-23 Scripts: point path inserts at workspace; archive U3-before ERC/netlist
    Local script path inserts were still under /home/anand; retarget them to the shared workspace. Add pre-U3 ERC and netlist reports from the bias-switch pass for history.
2026-09-23 Schematic: fix U3 TPS22919 pin labels on GNSS sheet (0 ERC errors)
    Correct Y-flipped label/wire/no_connect placement so VIN/VOUT/GND/ON land on the right nets. Archive post-fix netlist and ERC; update schematic review notes.
    [04_GNSS.kicad_sch]
2026-09-23 PCB pass30c: sync U3 nets, close VDD_GPIO/COEX0; unconnected 80→78
    Commit layout board, review notes, PASS30C summary and after-DRC. Ignore *.kicad_net exports. Exclude .mcp-backups.
    [nRF9161-DEV-BOARD.kicad_pcb]
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2026-09-23 PCB pass30d: Class F blocked by congestion; board restored; unconnected still 78
2026-09-23 PCB pass30e: Class F corridor clear aborted; ENABLE restore blocked; unconnected still 78
2026-09-23 PCB pass30f: close VIN_FILT via ENABLE co-route; unconnected still 78 (GND zone artifact)
    [nRF9161-DEV-BOARD.kicad_pcb]
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2026-09-23 PCB pass30h: VDD2 corridor bridge + VDD_nRF via north; P0.08 restore deferred; unconnected still 78
    [nRF9161-DEV-BOARD.kicad_pcb]
2026-09-23 PCB pass30h: add Stage A / P0.08 / Stage B mid-DRC snapshots
2026-09-23 PCB pass30i: close P0.08 U1–SW3 island; unconnected 78→77
    [nRF9161-DEV-BOARD.kicad_pcb]
2026-09-23 PCB pass30j: finish P0.08 to J12.9; unconnected 77→76
    [nRF9161-DEV-BOARD.kicad_pcb]
2026-09-23 PCB pass30k: close VIN_F; unconnected 76→75
    [nRF9161-DEV-BOARD.kicad_pcb]
2026-09-23 PCB pass30l: close SWDCLK via F/B detour; unconnected 75→74
    [nRF9161-DEV-BOARD.kicad_pcb]
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2026-09-23 PCB pass30m: nRESET probe reverted (COEX2/P0.01/VDD_nRF clearance); unconnected still 74
2026-09-23 PCB pass30n: close nRESET; unconnected 74→73
    [nRF9161-DEV-BOARD.kicad_pcb]
2026-09-23 PCB pass30o: close P0.02; unconnected 73→72
    [nRF9161-DEV-BOARD.kicad_pcb]
2026-09-23 PCB pass30p: close P0.22 U1–J8 and P0.11 fanout; unconnected 72→70
    [nRF9161-DEV-BOARD.kicad_pcb]
2026-09-23 PCB pass30q: P0.22 J13–J10 attach blocked by VDD_GPIO; board restored; unconnected still 70
2026-09-23 PCB pass30r: close P0.22 J13–J10; unconnected 70→69; J13 move deferred
    [nRF9161-DEV-BOARD.kicad_pcb]
2026-09-23 PCB pass30t: close VDD_GPIO J16–J17; unconnected 69→68; P0.31 still deferred
    [nRF9161-DEV-BOARD.kicad_pcb]
2026-09-23 PCB pass30u: close P0.19 J18–J13; unconnected 68→67; COEX0/P0.30 deferred
    [nRF9161-DEV-BOARD.kicad_pcb]
2026-09-23 PCB pass30v: audit only; P0.05/07 dirty revert; unconnected still 67
2026-09-23 PCB pass30w: Option E open matrix; copper frozen at 67; placement next
2026-09-23 DFM: Option E accept review — waive GND islands; RF/GPIO leftovers must-fix
2026-09-23 PCB pass30x: placement proposals A/B/C; board untouched at 67; B queued for pass30y
2026-09-23 PCB pass30y: Package B blocked+revert; J13/J10/J11 untouched; unconnected still 67
2026-09-23 PCB pass30z: close ANT_FIT/AUX/AUX_FIT Class C; unconnected 67→64; B' queued
    [nRF9161-DEV-BOARD.kicad_pcb]
2026-09-23 PCB pass30ab: Package B' blocked+revert; headers untouched; unconnected still 64
    [final_pass30ab.py]
2026-09-23 PCB pass30ac: Package A blocked+revert; SE/east headers frozen; B'' leave column frozen
    [final_pass30ac.py]
2026-09-30 PCB pass30ae: Package C blocked+revert; J14/J15 unmoved; unconnected still 64
    [final_pass30ae.py]
2026-09-30 PCB pass30af: preclear SIM_RST_C B.Cu jog; unconnected still 64
    [nRF9161-DEV-BOARD.kicad_pcb]
2026-09-30 PCB pass30ag: SIM_RST corridor probe reverted; unconnected still 64
    [final_pass30ag.py]
2026-09-30 PCB pass30ah: shortlist only; copper unchanged; unconnected still 64
2026-09-30 PCB pass30ai: VDD_GPIO jog reverted; unconnected still 64
    [final_pass30ai.py]
2026-09-30 PCB pass30aj: VDD_GPIO shove reverted; GND island offset; still 64
    [final_pass30aj.py]
2026-09-30 PCB pass30ak KEEP: VDD_GPIO U1.12; unconnected still 64 (opens 3→2 offset by waived F.Cu GND island 10→11); short/clearance/crossing/hole 0
    [nRF9161-DEV-BOARD.kicad_pcb]
2026-09-30 PCB pass30al KEEP: COEX0 closed; unconnected 64→63; short/clearance/crossing/hole 0; GND islands 11; hole_to_hole 1
    [nRF9161-DEV-BOARD.kicad_pcb]
2026-09-30 PCB pass30am: VDD_GPIO east reverted; POWER clearance miss 0.015 mm vs D3.1; unconnected still 63
    [final_pass30am.py]
2026-09-30 PCB pass30an KEEP: VDD_GPIO opens 2→1; unconnected still 63 (offset by waived GND island 11→12); D3.1 clearance 0.385 mm; short/clearance/crossing/hole 0; hole_to_hole 1
    [nRF9161-DEV-BOARD.kicad_pcb]
2026-09-30 PCB pass30ao: no route; VDD_GPIO open still 27.034 mm; unconnected still 63
2026-09-30 PCB pass30ap KEEP: VDD_GPIO opens 1→0; unconnected 63→62; GND islands 12; short/clearance/crossing/hole 0; hole_to_hole 1; tightest foreign clearance 0.207 mm to SIM_CLK
    [nRF9161-DEV-BOARD.kicad_pcb]
2026-09-30 PCB pass30aq KEEP: P0.31 header-to-header; opens 2→1; unconnected 62→61; GND islands 12; short/clearance/crossing/hole 0; hole_to_hole 1; foreign 0.230 mm; POWER 0.245 mm
    [nRF9161-DEV-BOARD.kicad_pcb]
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2026-09-30 PCB pass30as KEEP: P0.30 header-to-header; opens 2→1; unconnected 61→60; GND islands 12; short/clearance/crossing/hole 0; hole_to_hole 1; foreign 0.29 mm; POWER 0.70 mm
    [nRF9161-DEV-BOARD.kicad_pcb]
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2026-09-30 PCB pass30av: revert; P0.14 still 1; no B.Cu path to J18.2; unconnected still 60
    [final_pass30av.py]
2026-09-30 PCB pass30aw: no copper; 6 trapped U1 pads; shortest exitable P0.16 34.259 mm; unconnected still 60
2026-09-30 PCB pass30ax KEEP: P0.16 closed (In1 skirt via 40.70,20.80 to J18.4); opens 1→0; 60→59; GND islands 12; foreign 0.21 mm; POWER 0.338 mm; short/clr/cross/hole 0; hole_to_hole 1
    [nRF9161-DEV-BOARD.kicad_pcb]
2026-09-30 PCB pass30ay KEEP: P0.17 closed (In2 skirt via 40.25,23.10 to J18.5); opens 2→1; 59→58; GND islands 12; foreign 0.21 mm; POWER 0.338 mm; short/clr/cross/hole 0; hole_to_hole 1
    [nRF9161-DEV-BOARD.kicad_pcb]
2026-09-30 PCB pass30az: no route; P0.17 J17.1 leftover 61.510 mm; unconnected still 58
2026-09-30 PCB pass30ba: no route; P0.19 U1.30 to J18.7 leftover 36.658 mm; crossing revert; unconnected still 58
    [final_pass30ba.py]
2026-09-30 PCB pass30bb KEEP: P0.19 closed (In1 via 39.25,23.10 to J18.7); opens 1→0; 58→57; GND islands 12; foreign 0.17 mm; POWER 0.274 mm; short/clr/cross/hole 0; hole_to_hole 1
    [nRF9161-DEV-BOARD.kicad_pcb]
2026-09-30 PCB pass30bc KEEP: P0.20 closed (In2 via 36.20,20.80 to J18.8); opens 1→0; 57→56; GND islands 12; foreign 0.17 mm; POWER 0.274 mm; short/clr/cross/hole 0; hole_to_hole 1
    [nRF9161-DEV-BOARD.kicad_pcb]
2026-09-30 PCB pass30bd KEEP: SIM_CLK closed (In1 to via 73.30,36.00); opens 1→0; 56→55; GND islands 12; foreign 0.169 mm; POWER 0.2836 mm; short/clr/cross/hole 0; hole_to_hole 1
    [nRF9161-DEV-BOARD.kicad_pcb]
2026-09-30 PCB pass30be KEEP: SIM_RST closed (via 32.75,25.50 to via 78.00,36.00); opens 1→0; 55→54; GND islands 12; foreign 0.16 mm; POWER 0.2358 mm; short/clr/cross/hole 0; hole_to_hole 1
    [nRF9161-DEV-BOARD.kicad_pcb]
2026-09-30 PCB pass30bf KEEP: P0.00 closed (In1 via 39.75,41.10 to via 80.14,19.126); opens 1→0; 54→53; GND islands 12; foreign 0.16 mm; POWER 0.2457 mm; short/clr/cross/hole 0; hole_to_hole 1
    [nRF9161-DEV-BOARD.kicad_pcb]
2026-09-30 PCB pass30bg KEEP: P0.07 partial (In2 via 47.40,35.50 to J12.8); opens 2→1; 53→52; GND islands 12; foreign 0.18 mm; POWER 0.2842 mm; short/clr/cross/hole 0; hole_to_hole 1
    [nRF9161-DEV-BOARD.kicad_pcb]
2026-09-30 PCB pass30bh: no route; P0.07 J9.2 leftover 58.617 mm; unconnected still 52
2026-09-30 PCB pass30bi KEEP: P0.05 partial (In1 via 47.40,36.50 to J12.6); opens 2→1; 52→51; GND islands 12; foreign 0.33 mm; POWER 0.33 mm; short/clr/cross/hole 0; hole_to_hole 1
    [nRF9161-DEV-BOARD.kicad_pcb]
2026-09-30 PCB pass30bj: no route; P0.05 J9.3 leftover 63.218 mm; unconnected still 51
2026-10-12 PCB pass30bk: no route; SIM_1V8 via-row and west slot blocked; unconnected still 51
2026-10-12 PCB pass30bl: reverted; SIM_1V8 route needed via-in-pad on U1.49; unconnected still 51
2026-10-12 PCB pass30bn KEEP: P0.09 U1.16 to J12.10 (exit via 46.90,29.72, In1); opens 2→1; 51→50; foreign 0.195 mm; POWER 0.24 mm; short/clr/cross/hole 0; hole_to_hole 1; J16.4 leftover 64.09 mm
2026-10-12 PCB pass30bo KEEP: P0.11 via 49.92,28.0 to J12.12 (In2, no new via); opens 2→1; 50→49; foreign 0.197 mm; POWER 0.43 mm; short/clr/cross/hole 0; hole_to_hole 1; J16.2 leftover 59.3 mm
2026-10-12 PCB pass30bp reverted (stacked on P0.00/SIM_RST); 30bq/30br no-route (J12.11/J12.13 boxed in); 30bs census: 37 non-GND opens (A6 B2 C17 D12); unconnected 49
2026-10-12 PCB pass30bt KEEP: P0.22 fully closed (In2, 3 segs, no new via, cap waived 51.6 mm); 49→48; foreign 0.18 mm; POWER 0.264 mm; short/clr/cross/hole 0; hole_to_hole 1
2026-10-12 PCB pass30bu KEEP: P0.23 J13.8 to J10.3 (In2, 4 segs, no via, cap waived); opens 2→1; 48→47; foreign 0.226 mm; short/clr/cross/hole 0; hole_to_hole 1
2026-10-12 PCB pass30bv KEEP: P0.18 J13.3 island to J17.2 (In1, 3 segs, no via, cap waived); opens 2→1; 47→46; foreign 0.286 mm; POWER 0.36 mm; short/clr/cross/hole 0; hole_to_hole 1
2026-10-12 PCB pass30bw KEEP: P0.17 fully closed J17.1 to J13.2 (In1, 5 segs, no via, cap waived); 46→45; foreign 0.21 mm; short/clr/cross/hole 0; hole_to_hole 1
2026-10-12 PCB pass30bx KEEP: P0.21 J13.6 to J10.1 (In1, 4 segs, no via, cap waived); opens 2→1; 45→44; foreign 0.21 mm; short/clr/cross/hole 0; hole_to_hole 1
2026-10-12 PCB pass30by KEEP: P0.24 J13.9 to J10.4 (In1, 5 segs, no via, cap waived); opens 2→1; 44→43; foreign 0.231 mm; short/clr/cross/hole 0; hole_to_hole 1
2026-10-12 PCB pass30bz/30ca: no route; P0.23 U1 side splits VDD_nRF In2 neck (x53-60, y12-22, now keepout); unconnected 43
2026-10-12 Pin remap + PCB sync (pass30cb): UART0 2-wire (RX P0.04, J9.2/3 NC), J16 DNF, U2 TLV73333 on PCB; ERC 0 errors; unconnected 43→38 (26 non-GND + 12 GND); short/clr/cross/hole 0
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2026-10-12 pass30cd: restore board to main 8628f07 (blob 0e1d4fa) after RF review reject of pass30cc
2026-10-12 pass30cd: F/B-only Freerouting re-route, opens 26->17, In1 untouched, dangling cleanup, GND stitching
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2026-10-12 pass30cf: silk labels/titles/U1-U4 trim, dangling+duplicate cleanup, edge/hole fixes; opens unchanged (17)
2026-10-12 pass30ch: remove SIM_CLK_C stub via, trim stub to tee; B.Cu GND pieces under U1 verified stitched
2026-10-12 pass30ci: route SIM_1V8 (U1.49 escape + B.Cu); SIM_IO left open (no 0.5mm path)
2026-10-12 Schematic: add C40 100nF X7R on SIM_1V8 at U1; D3-D7 values restored (Function field); D7 DNP; ERC 0 errors
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2026-10-12 pass30ck: C40 at U1.49 (SIM_1V8 decoupling), D3-D7 fields + D7 DNP, SIM_1V8 widened/POWER class, B.Cu sliver removed + block stitched
2026-10-12 pass30cl: J14 to (26.5,14.35) r180; VIPPO 0.2/0.3 in U1 pads 52-60 (+.kicad_dru, VIPPO user layer); MAGPIO0-2/MIPI routed on B.Cu; P0.02 north branch rerouted
2026-10-12 DFM_VIPPO_NOTE: fill+cap scope to 18 (9 GND thermal vias in U1 GND pads); drill-selection finding (286x 0.3mm vias); add C7 OPEN row to FAB_READY_CHECKLIST
2026-10-12 DFM_VIPPO_NOTE/C7: RF accepts JLC standard for proto (plating ~18um, prod target >=20um); caps recess<=50um / protrusion<=+25um with no-proud order note; U1 assembly: 0.12mm stencil per Nordic nWP054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
2026-10-12 DFM_VIPPO_NOTE: stencil 0.10 mm, U1 paste 70-85% (nWP054/nWP056), 0.12 superseded; fix §1.5/§1.6 order; add §1.7 U1 footprint vs nRF9161 DK 1.0.0 Gerbers (outer pads overhang outline, non-NSMD mask)
2026-10-12 pass30cm: docs only (C5 exception text pads 52-60, DFM fab note 9 VIPPO); rip-up/reroute reverted per footprint plan change
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2026-10-12 pass30cm FX1: P0.00 off In1 entirely (F/B reroute east of U1, 3 GND stitch vias); In1 GND 8140.8->8206.5 mm2
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2026-10-12 pass30cm step5: rip P0.13 under U1; route P0.12/P0.25/P0.31 via VIPPO at new pad centres; P0.13 reclosed; GND stitches
2026-10-12 fab-pass bc6d0fc: DRC as-is/refilled (10 real GND islands), U1 vs DK PASS, VIPPO 16+9 verified, staging fab outputs + zip, checklist re-assessed (gate RED)
2026-10-12 pass30cp step1: 5 GND stitch vias (islands 10->5); remaining 5 need in-pad/RF-keepout waiver
2026-10-12 pass30cp B: trim 4 overshooting stubs (VDD_GPIO x3, P0.11) - 0 dangling; SIM_RST via nudged 0.2mm from SIM_IO
2026-10-12 pass30cp step2: locked stackup (L1-L2 0.12 prepreg, 1.2 core, 0.12, ENIG, 1.6 mm)
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2026-10-13 v2 layout 4: all nets routed (Freerouting + scripted A* fixes), SIM ESD block moved below J7, GND islands stitched; unconnected 0, copper DRC 0
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2026-10-13 v2b-2: VDD_GPIO re-routed at 0.3 mm POWER clearance (141 mm vs 148 mm, 16 vias)
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2026-10-13 v2c-2 (F2): VDD1/VDD2 widened to 0.5 mm where clearance allows (VDD1 11.8/3.4 mm, VDD2 4.3/8.3 mm wide/narrow)
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2026-10-13 v2f-2: silk cleanup: refdes 1.0/0.15 upright, auto-placed clear of pads/vias/silk (35 dense passives hidden); J20 top RX/RTS/CTS + bottom DTR/RI/nRST; LTE/GNSS/SWD labels; bottom board name; 8 non-fe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
2026-10-13 v2f-5: panel regenerated (KiKit 1.8.1, v2_panel.json, same N/S tab positions) from rounded-corner board; 128 mousebite holes; panel DRC 0 errors / 0 unconnected
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
